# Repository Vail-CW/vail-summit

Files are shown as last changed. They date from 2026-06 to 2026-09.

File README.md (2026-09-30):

# VAIL SUMMIT

A pocket-sized Morse code (CW) trainer and ham radio tool. Learn code from scratch, keep your
skills sharp, and use it on the air. It has a color screen, a built-in paddle and speaker, and
runs on its own battery, so you don't need a computer.





> **Now in testing. Official release is planned for July 2026.** You can get one early during the
> testing phase at [shop.ke9bos.com](https://shop.ke9bos.com), or email me (Brett, KE9BOS) at
> [ke9bos@pigletradio.org](mailto:ke9bos@pigletradio.org).

## What is it?

VAIL SUMMIT is a standalone device for learning and practicing Morse code. New to CW? It will take
you from your first character to real copy. Been at it a while? Use it to warm up, log contacts,
and get on the air.

Turn it on and you start at a home screen with your training progress and the day's band
conditions. From there you can take a lesson, run a quick drill, play a game, key a real radio, or
hop on the internet Morse repeater and ragchew with other ops in code.

It does two jobs:

- It teaches CW with a structured course that starts at full character speed.
- It works as a portable ham tool for logging contacts, POTA, propagation, keying your rig, and
  storing CW messages.

## What you can do with it

### Learn CW

One course that takes you from your first character to solid copy. It uses the Koch method: you
hear letters at full speed from the start, so you learn the sound of each character instead of
counting dits and dahs. Each lesson moves from a quick intro to solo practice, then mixed copy,
then real words and callsigns. It saves your place, so you pick up where you left off.

Three ways to practice once you're going:

- **Daily practice:** a short warm-up that mixes in everything you've learned.
- **Copy practice:** open-ended listen-and-type, for as long as you want.
- **Send practice:** key the paddle and the device decodes your sending as you go.

### Practice and decode

There's a practice oscillator with a live decoder built in. Key on the paddle (or a straight key)
and the device shows your Morse as text on screen, along with your speed in words per minute. It's
a handy way to check your own fist.

### Games

A few games to make practice less of a chore: **Morse Shooter** (arcade-style falling characters),
**Memory Chain**, the maritime-themed **Spark Watch**, a speed challenge, and more. Each one keeps
score.

### On the air

- **Key your radio:** a 3.5 mm jack keys an external transceiver, either as a keyer or a
  straight-through key.
- **CW memories:** store your common calls and exchanges and send them with one button.
- **QSO logger:** log contacts on the device or in your browser, view them on a map, and export to
  ADIF or CSV for your main logging program.
- **POTA:** Parks On The Air lookups and activation tracking for portable operating.
- **Band conditions and band plans:** live solar and propagation numbers, plus frequency
  privileges by license class, so you know where and when to call CQ.

### Vail internet repeater

Connect over WiFi to the Vail Morse repeater (vailmorse.com) and send and receive real, hand-keyed
Morse with other operators around the world. It's an easy way to get on the "air" when you don't
have a radio in front of you.

### Connect it

- **WiFi web interface:** open the device in any browser on your network to practice, log contacts,
  manage files, and change settings on a bigger screen. It's password-protected, and your password
  shows on the device under System Info.
- **Bluetooth:** works as a wireless keyer for software like MorseRunner, speaks standard BLE MIDI,
  and can connect to a Bluetooth keyboard.

## Getting started

### 1. Put firmware on it

No software to install:

1. Open the [web flasher](https://update.vailadapter.com) in Chrome or Edge.
2. Plug the device into your computer with a USB cable.
3. Pick **VAIL SUMMIT**, click **Flash**, and follow the prompts.

### 2. First steps

1. Power on. You'll land on the home screen.
2. Move with the **arrow keys**, select with **Enter**, go back with **Esc**.
3. Pick **Learn CW** to start your first lesson, or look around the menus.
4. For WiFi (needed for the repeater, logging, and the web interface), go to
   **More > Settings > WiFi** and join your network.

### 3. Handy to know

- **Quick settings:** press **V** from a menu to adjust volume, brightness, CW speed, and tone
  without leaving what you're doing.
- **Web access:** once you're on WiFi, open `http://vail-summit.local/` from a browser on the same
  network.
- **Start over:** there's a factory reset under **Settings > Device Settings**, or hold both paddle
  levers while you power on.

## What's in it

A small, battery-powered computer set up for CW:

- **4-inch color LCD** with a card-style menu
- **Built-in speaker**, plus a real **iambic paddle and capacitive touch pads** (straight key works too)
- **Rechargeable battery** with a charge readout on screen
- **WiFi and Bluetooth** built in
- **microSD card** slot for logs and files
- **3.5 mm jack** for keying an external radio

## Help and community

- **Buy a Summit (testing phase):** [shop.ke9bos.com](https://shop.ke9bos.com) or [ke9bos@pigletradio.org](mailto:ke9bos@pigletradio.org)
- **Questions or ideas:** [GitHub Discussions](https://github.com/Vail-CW/vail-summit/discussions)
- **Found a bug?** [GitHub Issues](https://github.com/Vail-CW/vail-summit/issues)

## For tinkerers and developers

VAIL SUMMIT runs on an ESP32-S3, and the firmware source is open for noncommercial use. If you want
to build it, change it, or just look around:

- [Building from source](docs/BUILDING.md): toolchain setup and compiling
- [Hardware reference](docs/HARDWARE.md): board, pins, and interfaces
- [Architecture](docs/ARCHITECTURE.md) and [development notes](docs/DEVELOPMENT.md)

## License

Copyright (c) 2025 Brett Hollifield (KE9BOS) / Vail-CW.

The firmware is licensed under the **PolyForm Noncommercial License 1.0.0** (see
[LICENSE.md](LICENSE.md)). You're free to use, modify, and share it for noncommercial purposes.
Selling devices that run this firmware needs a license from me. It's built with several
open-source libraries; see [THIRD_PARTY_NOTICES.md](THIRD_PARTY_NOTICES.md) for credits.

## Thanks

- The [Vail Morse Repeater](https://vailmorse.com) community for the internet CW connection
- [morse-pro](https://github.com/scp93ch/morse-pro) by Stephen C Phillips for the decoding foundation
- The CW clubs and Elmers who keep new hams getting on the air

*73 de KE9BOS, Brett Hollifield, [ke9bos@pigletradio.org](mailto:ke9bos@pigletradio.org)*

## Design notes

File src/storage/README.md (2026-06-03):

# Storage Module

SD card storage management for VAIL SUMMIT.

## Overview

The storage module provides SD card file management capabilities through a web interface. The SD card shares the SPI bus with the display and uses lazy initialization to avoid boot-time conflicts.

## Files

- **`sd_card.h`** - Core SD card functionality (initialization, file operations, storage stats)

## Hardware Configuration

**GPIO Pin:** 38 (SD_CS - Chip Select)
**Shared SPI Bus:** MOSI=35, SCK=36, MISO=37 (same as display)
**Display CS:** GPIO 10 (separate chip select allows bus sharing)

## SD Card Requirements

- **Format:** FAT32 (required - exFAT not supported)
- **Recommended Size:** 4-32 GB SDHC
- **Speed Class:** Class 10 or higher
- **Important:** Cards >32 GB must be reformatted to FAT32

## Initialization Strategy

The SD card uses **lazy initialization** (on-demand):

1. **Boot Time:** SD card is NOT initialized (prevents SPI conflicts with display)
2. **First Access:** When user accesses `/storage` page, SD card initializes automatically
3. **SPI Sharing:** LovyanGFX display is configured with `bus_shared=true` to allow coexistence

### Why Lazy Init?

Initializing the SD card during boot can interfere with the display's SPI configuration, causing a blank screen. By deferring initialization until first use, we ensure:
- Display always boots correctly
- SPI bus is properly shared between devices
- No user impact (SD init happens transparently on first page access)

## API Functions

### `bool initSDCard()`
Initialize SD card and detect card type. Returns `true` if successful, `false` if no card or init failed.

### `void updateSDCardStats()`
Update global variables for card size and usage statistics.

### `String listSDFiles(const char* dirname, bool recursive = false, int depth = 0)`
List files in directory, returns JSON array of file objects.

### `bool deleteSDFile(const char* path)`
Delete file at specified path.

### `bool fileExists(const char* path)`
Check if file exists.

### `size_t getFileSize(const char* path)`
Get file size in bytes.

### `String readSDFile(const char* path)`
Read entire file contents (for small files).

### `bool writeSDFile(const char* path, const char* data)`
Write data to file (overwrites existing).

### `bool appendSDFile(const char* path, const char* data)`
Append data to existing file.

## Web Interface Integration

The storage module integrates with the web server via:

- **`web_api_storage.h`** - REST API endpoints for file operations
- **`web_pages_storage.h`** - HTML/CSS/JS storage management page

### REST API Endpoints

- `GET /api/storage/status` - Get SD card statistics
- `GET /api/storage/files?path=/` - List files in directory
- `GET /api/storage/download?file=/filename` - Download file
- `DELETE /api/storage/delete?file=/filename` - Delete file
- `POST /api/storage/upload` - Upload file (multipart/form-data)

### Web Page

Access at: `http://vail-summit.local/storage`

Features:
- Storage usage graph
- File browser with icons and sizes
- Upload files via file picker
- Download and delete buttons for each file

## Usage Examples

### Initialize SD Card
```cpp
if (initSDCard()) {
  Serial.println("SD card ready!");
  Serial.printf("Size: %llu MB\n", sdCardSize);
}
```

### Write File
```cpp
writeSDFile("/data.txt", "Hello from VAIL SUMMIT!");
```

### Read File
```cpp
String contents = readSDFile("/data.txt");
Serial.println(contents);
```

### List Files
```cpp
String fileList = listSDFiles("/");
Serial.println(fileList);  // Prints JSON array
```

## Future Use Cases

This SD card infrastructure enables:

1. **Data Logging** - Log training sessions, practice statistics, WPM progress
2. **QSO Backups** - Export QSO logs to SD card for offline backup
3. **Configuration Backups** - Save/restore device settings to SD card
4. **Firmware Updates** - Store firmware binaries for OTA updates
5. **Custom Content** - Load callsign lists, practice text, custom character sets

## Troubleshooting

**Display is blank after boot:**
- Ensure SD card init is NOT called during boot sequence
- SD card should only initialize on first web access

**"SD card not available" error:**
- Check card is inserted
- Verify card is formatted as FAT32 (not exFAT)
- Check wiring: CS=38, MOSI=35, SCK=36, MISO=37

**Cannot upload large files:**
- FAT32 has 4 GB file size limit
- Check available free space on card

**Files not showing in web interface:**
- Ensure card is FAT32 formatted
- Check files are in root directory (/)
- Refresh the page to trigger re-initialization

## Technical Notes

- SD library uses 4 MHz SPI clock (safe speed for compatibility)
- Mount point: `/sd`
- Max open files: 5 (default SD library limit)
- File paths must start with `/` (e.g., `/data.txt`)

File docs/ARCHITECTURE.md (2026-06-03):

# Architecture

This document covers the system architecture, state machine, main loop responsibilities, and critical subsystems.

## Code Organization

The firmware follows a modular architecture with all source code organized into thematic folders:

```
vail-summit/
├── src/
│   ├── core/           # Core system (config, morse code, hardware init)
│   ├── audio/          # Audio system and morse decoder (I2S, WPM, adaptive decoder)
│   ├── ui/             # UI components (menu system, status bar)
│   ├── training/       # Training modes (Practice, CW Academy, Koch Method, Hear It Type It)
│   ├── games/          # Games (Morse Shooter, Memory Chain)
│   ├── radio/          # Radio integration (keying output, CW memories)
│   ├── settings/       # Settings management (WiFi, CW, volume, callsign, web password)
│   ├── qso/            # QSO logging (storage, input, validation, statistics)
│   ├── web/            # Web interface
│   │   ├── server/     # Web server core (AsyncWebServer, routing)
│   │   ├── api/        # REST API endpoints (WiFi, QSO, settings, memories)
│   │   ├── pages/      # HTML/CSS/JS pages (dashboard, logger, settings, games)
│   │   └── modes/      # WebSocket handlers (practice, memory chain, hear it)
│   └── network/        # Network services (Vail repeater, NTP, POTA API)
├── vail-summit.ino     # Main sketch file (setup, loop, mode handlers)
└── docs/               # Documentation
```

**Key Benefits:**
- **Modularity:** Each folder contains related functionality
- **Maintainability:** Easy to locate and modify specific features
- **Scalability:** New features added to appropriate folders
- **Clear dependencies:** Include paths reveal module relationships

**Include Path Conventions:**
- From `.ino` file: `#include "src/core/config.h"`
- Between headers: `#include "../core/config.h"` (relative paths)

## Mode-Based State Machine

The system operates as a state machine with different modes (`MenuMode` enum in vail-summit.ino). Each mode has its own input handler and UI renderer. The main loop delegates to the appropriate mode handler based on `currentMode`.

### Key Modes

**Menu Navigation:**
- `MODE_MAIN_MENU` - Top-level menu (Training, Games, Settings, Radio, Logs, Sleep)
- `MODE_TRAINING_MENU` - Training submenu
- `MODE_SETTINGS_MENU` - Settings submenu
- `MODE_GAMES_MENU` - Games submenu
- `MODE_RADIO_MENU` - Radio submenu

**Training Modes:**
- `MODE_HEAR_IT_TYPE_IT` - Receive training (type what you hear)
- `MODE_PRACTICE` - Practice oscillator with paddle keying
- `MODE_CW_ACADEMY_TRACK_SELECT` - CW Academy track selection
- `MODE_CW_ACADEMY_SESSION_SELECT` - Session selection
- `MODE_CW_ACADEMY_PRACTICE_TYPE_SELECT` - Practice type selection
- `MODE_CW_ACADEMY_MESSAGE_TYPE_SELECT` - Message type selection
- `MODE_CW_ACADEMY_COPY_PRACTICE` - CW Academy copy practice (listen and type)

**Games:**
- `MODE_MORSE_SHOOTER` - Arcade-style game with adaptive decoder (shoot falling letters with morse code, supports straight key and iambic keyer)

**Radio Integration:**
- `MODE_RADIO_OUTPUT` - Key external ham radios via 3.5mm jack outputs
- `MODE_CW_MEMORIES` - Store and playback CW message memories (placeholder)

**Network:**
- `MODE_VAIL_REPEATER` - Internet morse repeater via WebSocket

**Settings:**
- `MODE_WIFI_SETTINGS` - WiFi scanning, connection, credential management
- `MODE_CW_SETTINGS` - CW speed, tone frequency, key type
- `MODE_VOLUME_SETTINGS` - Volume adjustment
- `MODE_CALLSIGN_SETTINGS` - User callsign configuration

**Logging:**
- QSO Logger accessed via web interface (no dedicated device mode for input)

## Main Loop Responsibilities

The `loop()` function (vail-summit.ino) performs:

1. **Status Icon Updates** - Every 5 seconds (except during practice/training to avoid audio interference)
2. **Mode-Specific Updates** - Calls update functions (`updatePracticeOscillator()`, `updateVailRepeater()`, `updateMorseShooterInput()`, `updateMorseShooterVisuals()`, `updateRadioOutput()`)
3. **Keyboard Polling** - CardKB via I2C at 10ms intervals (50ms during practice/game modes for audio priority)
4. **Triple-ESC Sleep Timeout** - Tracks ESC presses for deep sleep entry

### Loop Timing

**Normal operation:** 10ms delay between iterations
**Audio-critical modes (Practice, Morse Shooter, Radio Output):** 50ms keyboard polling, 1ms main loop delay

## Audio System Architecture

The audio system uses **I2S DMA** for high-quality, glitch-free output through the MAX98357A amplifier. This replaces the legacy PWM buzzer.

### Critical Timing Requirements

1. **I2S DMA has highest interrupt priority** (`ESP_INTR_FLAG_LEVEL3`) to beat SPI display DMA
2. **I2S must be initialized BEFORE the display** to establish DMA priority
3. **Audio buffers are filled in interrupt context** - tone generation must be fast
4. **During practice mode, display updates are COMPLETELY DISABLED** to avoid audio glitches
5. **`continueTone()` function maintains phase continuity** for smooth audio transitions

### Volume Control

- **Software attenuation** (0-100%) applied during sample generation in `i2s_audio.h`
- Settings persisted in Preferences namespace "audio"
- Hardware gain on MAX98357A is fixed (GAIN pin configuration)

### Audio Functions

```cpp
beep(frequency_hz, duration_ms);  // Short beeps/tones (blocking)
startTone(frequency_hz);          // Start continuous tone
continueTone();                   // Maintain tone with phase continuity
stopTone();                       // Stop continuous tone
```

**Important:** Always use these functions instead of direct I2S manipulation. They handle volume scaling and phase continuity.

## Morse Code Timing

All timing uses the **PARIS standard** (50 dit units per word):

- **Dit duration:** `1200 / WPM` milliseconds
- **Dah duration:** `3 × dit`
- **Inter-element gap:** `1 × dit`
- **Letter gap:** `3 × dit`
- **Word gap:** `7 × dit`

**WPM Range:** 5-40 WPM (configurable per mode, stored in Preferences)

### MorseTiming Class

```cpp
#include "src/core/morse_code.h"
MorseTiming timing(20);  // 20 WPM timing calculator

// Available properties:
// timing.ditDuration
// timing.dahDuration
// timing.elementGap
// timing.letterGap
// timing.wordGap
```

## Input Handling Pattern

Each mode implements three key functions:

### Required Functions

1. **`start<Mode>(tft)`** - Initialize mode state and draw initial UI
2. **`handle<Mode>Input(key, tft)`** - Process keyboard input, return -1 to exit mode
3. **`update<Mode>()`** (optional) - Called every loop iteration for real-time updates

### Return Codes

Input handlers return:
- **`-1`** - Exit mode (return to parent menu)
- **`0` or `1`** - Normal input processed
- **`2`** - Full UI redraw requested
- **`3`** - Partial UI update (e.g., input box only)

### Example Implementation

```cpp
void startMyMode(LGFX& tft) {
  // Initialize state variables
  myModeState = 0;

  // Draw initial UI
  tft.fillScreen(COLOR_BACKGROUND);
  // ... draw UI elements
}

int handleMyModeInput(char key, LGFX& tft) {
  if (key == 0x1B) {  // ESC key
    return -1;  // Exit mode
  }

  // Process other keys
  // ...

  return 0;  // Input processed
}

void updateMyMode() {
  // Called every loop iteration
  // Perform real-time updates (non-blocking)
}
```

## Menu Navigation

The menu system uses a card-based UI where users scroll through options and select items.

### Navigation Controls

**Arrow Keys:**
- **Up/Down** - Navigate between menu items (scroll through cards)
- **Right** - Select highlighted menu item (enter submenu/mode)

**Other Keys:**
- **Enter** - Select highlighted menu item (same as Right arrow)
- **ESC** - Go back to parent menu / Exit current mode
- **ESC (triple press in main menu)** - Enter deep sleep mode

### Visual Design

Each menu card displays:
- Icon representing the menu option
- Title text
- Right arrow (→) indicating the option can be selected

The right arrow visual matches the keyboard input - pressing the **Right arrow key** or **Enter** selects the highlighted card.

### Implementation

Menu navigation is handled in `src/ui/menu_navigation.h`:
- `handleKeyPress()` routes input based on current mode
- `selectMenuItem()` transitions to the selected mode
- `drawMenuItems()` renders the card-based UI with arrow indicators

## Configuration Management

All user settings are stored in ESP32 Preferences (non-volatile flash storage).

### Preferences Namespaces

- **"wifi"** - Up to 3 WiFi network credentials (ssid1-3, pass1-3)
  - Auto-connect tries all saved networks in order at startup
  - Most recently connected network stored in slot 1
  - Saved networks marked with star (*) in WiFi settings UI
- **"cwsettings"** - WPM speed, tone frequency (Hz), key type
- **"audio"** - Volume percentage
- **"callsign"** - User callsign for Vail repeater
- **"cwa"** - CW Academy progress (track, session, practice type, message type)
- **"radio"** - Radio mode (Summit Keyer vs Radio Keyer)
- **"qso_operator"** - Station info (callsign, grid square, POTA reference)
- **"cw_memories"** - CW memory presets (10 slots)
  - Keys: "label1" through "label10", "message1" through "message10"
  - Each slot stores a label (max 15 chars) and message (max 100 chars)
  - Empty slots stored as empty strings
  - Loaded at startup via `loadCWMemories()` in `src/radio/radio_cw_memories.h`
  - Saved immediately on create/edit/delete
  - Debug logging: All load/save operations print to Serial for troubleshooting

### Best Practices

- Load settings on startup
- Save immediately when changed (don't batch writes)
- Use consistent key names across modules

## WiFi Configuration and AP Mode

### WiFi Connectivity Modes

The device supports two WiFi modes for flexible connectivity:

**Station (STA) Mode:**
- Default mode - connects to existing WiFi networks
- Auto-connects to saved networks on startup (tries all 3 slots in order)
- Web server accessible via mDNS at `http://vail-summit.local` or device IP
- Supports up to 3 saved network credentials

**Access Point (AP) Mode:**
- Creates its own WiFi network for direct connection
- Useful when no WiFi available or for initial setup
- SSID format: `VAIL-SUMMIT-XXXXXX` (XXXXXX = chip ID in hex)
- Default password: `vailsummit`
- IP address: `192.168.4.1` (standard ESP32 AP address)
- mDNS not available in AP mode (use IP address only)

### Entering AP Mode

**From Device:**
1. Navigate to Settings → WiFi Setup
2. Press 'A' key to enable AP mode
3. Device creates WiFi network and starts web server
4. Screen shows network name, password, and IP address

**Connecting to AP:**
1. On phone/laptop, connect to `VAIL-SUMMIT-XXXXXX` WiFi network
2. Enter password: `vailsummit`
3. Open browser to `http://192.168.4.1/`
4. Access web interface for device configuration

### Automatic AP Mode Exit

When connecting to a WiFi network from AP mode (via web or device):

1. **Device automatically:**
   - Stops AP mode and web server
   - Connects to the selected WiFi network
   - Saves credentials to preferences
   - Shows "Connected!" message for 2 seconds
   - Returns to main menu
   - Web server restarts in Station mode (via WiFi event handler)

2. **User experience:**
   - Web interface shows success modal: "Check Your Device"
   - Phone loses connection to AP (expected behavior)
   - Device is now accessible on the new WiFi network at its assigned IP

3. **Error handling:**
   - If connection fails, AP mode automatically restarts
   - User can try again without manual intervention

### Web Server Behavior

**WiFi Event Handler** (vail-summit.ino:182-190):
- Automatically starts web server when WiFi connects (Station mode)
- Automatically stops web server when WiFi disconnects
- `setupWebServer()` detects AP vs Station mode and configures accordingly

**AP Mode Web Server:**
- Starts automatically when `startAPMode()` is called
- Skips mDNS setup (not supported in AP mode)
- Accessible only via IP address: `http://192.168.4.1/`
- Stops automatically when AP mode exits

**Station Mode Web Server:**
- Starts via WiFi event handler on connection
- Includes mDNS responder: `http://vail-summit.local/`
- Accessible via mDNS or IP address
- Stops via WiFi event handler on disconnection

### WiFi Settings Module (src/settings/settings_wifi.h)

**State Machine:**
```cpp
enum WiFiSettingsState {
  WIFI_STATE_SCANNING,        // Scanning for networks
  WIFI_STATE_NETWORK_LIST,    // Showing available networks
  WIFI_STATE_PASSWORD_INPUT,  // Entering password
  WIFI_STATE_CONNECTING,      // Attempting connection
  WIFI_STATE_CONNECTED,       // Successfully connected
  WIFI_STATE_ERROR,          // Connection failed
  WIFI_STATE_RESET_CONFIRM,  // Confirming credential reset
  WIFI_STATE_AP_MODE         // Access Point mode active
};
```

**Key Functions:**
- `startAPMode()` - Creates AP, starts web server
- `stopAPMode()` - Stops AP, returns to Station mode
- `connectToWiFi(ssid, password)` - Handles connection with automatic AP exit
- `scanNetworks()` - Scans for available WiFi networks
- `saveWiFiCredentials()` - Stores up to 3 network credentials
- `autoConnectWiFi()` - Tries saved networks on startup

**Tracking Variables:**
- `isAPMode` - Global flag for AP mode state
- `connectedFromAPMode` - Tracks if connection made from AP mode
- `connectionSuccessTime` - Timestamp for auto-exit timer

## Vail Repeater Protocol

The Vail repeater (`src/network/vail_repeater.h`) uses a WebSocket connection with JSON messages:

### Transmission Format

```json
{"Timestamp":1759710473428,"Clients":0,"Duration":[198]}
```

- Each tone sent immediately as separate message
- **Timestamp:** Unix epoch milliseconds (when tone started)
- **Duration array:** Contains single tone duration in milliseconds
- Silences are implicit (gaps between tones)

### Reception Format

```json
{"Timestamp":1759710473428,"Clients":2,"Duration":[100,50,100,150]}
```

- **Even indices** (0, 2, 4...): tone durations
- **Odd indices** (1, 3, 5...): silence durations
- Clock skew calculated from initial handshake for synchronization
- 500ms playback delay buffer for network jitter
- Echo filtering: messages with our own timestamp are ignored

## Battery Monitoring

Two battery monitor chips are supported (I2C auto-detection on startup):

- **MAX17048** at address `0x36` (primary, used on Adafruit ESP32-S3 Feather V2)
- **LC709203F** at address `0x0B` (backup/alternative)

The fuel gauge chips provide voltage and state-of-charge percentage. Calibration improves over several charge/discharge cycles.

**USB charging detection is disabled** because GPIO 15 (A3) is used by I2S for the LRC clock signal. Using `analogRead(A3)` reconfigures the pin and completely breaks I2S audio output.

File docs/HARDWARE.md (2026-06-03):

# Hardware Interfaces

This document covers all hardware interfaces, pin assignments, and peripheral configurations for the VAIL SUMMIT device.

## Display (ST7796S 4.0" via SPI)

- **Model:** 4.0" TFT ST7796S LCD
- **Resolution:** 480×320 pixels (landscape orientation, `SCREEN_ROTATION = 1`)
- **Library:** LovyanGFX (replaces Adafruit_ST7789)
- **Chip Select:** GPIO 10 (`TFT_CS`)
- **Reset:** GPIO 11 (`TFT_RST`)
- **Data/Command:** GPIO 12 (`TFT_DC`)
- **MOSI:** GPIO 35 (Hardware SPI)
- **SCK:** GPIO 36 (Hardware SPI)
- **MISO:** GPIO 37 (Hardware SPI - required for ST7796S)
- **Backlight:** Hardwired to 3.3V (always on)

**Configuration:**
- Hardware SPI used for maximum performance
- Display updates disabled during audio-critical operations (practice, games, radio)
- Partial screen updates used where possible to minimize glitches

## SD Card (via SPI - shares bus with display)

- **Chip Select:** GPIO 38 (`SD_CS`)
- **MOSI:** GPIO 35 (Shared with display - Hardware SPI)
- **SCK:** GPIO 36 (Shared with display - Hardware SPI)
- **MISO:** GPIO 37 (Shared with display - Hardware SPI)

**Configuration:**
- SD card shares the same SPI bus as the display
- Separate chip select pins allow independent device control (Display: GPIO 10, SD: GPIO 38)
- Only one device can be active at a time (controlled by CS pin)
- SD card slot is integrated on the back of the ST7796S display board
- Requires separate wiring of all 4 SD card pins to ESP32-S3 Feather

**Library Support:**
- Standard Arduino SD library (FAT32 file system)
- SPI bus must be properly shared between display and SD card operations
- SD card initialized on-demand (first access to storage page) to avoid boot-time SPI conflicts

**Card Requirements:**
- Format: FAT32 (required)
- Recommended size: 4-32 GB SDHC
- Speed class: Class 10 or higher recommended
- Cards larger than 32 GB must be reformatted from exFAT to FAT32

## Keyboard (CardKB via I2C)

- **I2C Address:** `0x5F`
- **SDA:** GPIO 3
- **SCL:** GPIO 4

### Special Key Codes

- `0xB5` - UP arrow
- `0xB6` - DOWN arrow
- `0xB4` - LEFT arrow
- `0xB7` - RIGHT arrow
- `0x0D` - ENTER
- `0x1B` - ESC

### Polling Behavior

- **Normal modes:** 10ms intervals
- **Practice/Game modes:** 50ms intervals (audio priority)

## Paddle Input

**Physical Paddle Pins:**
- **DIT:** GPIO 6 (`PADDLE_DIT_PIN`)
- **DAH:** GPIO 9 (`PADDLE_DAH_PIN`)
- **Configuration:** Active LOW with internal pullups

**Supported Key Types:**
- Straight key (DIT paddle only)
- Iambic A (alternating priority)
- Iambic B (last-contact priority with memory)

**Implementation:**
- Iambic logic in `training_practice.h`
- Implements memory modes and squeeze keying
- State machine handles timing for WPM accuracy

## Capacitive Touch

**Touch Pad Pins:**
- **DIT:** GPIO 8 (T8) - `TOUCH_DIT_PIN`
- **DAH:** GPIO 5 (T5) - `TOUCH_DAH_PIN`
- **Threshold:** Configured in `config.h` (`TOUCH_THRESHOLD = 40000`)

### Critical Notes

**CRITICAL BUG WORKAROUNDS:**
1. **Must use GPIO numbers directly in `touchRead()`**, not T-constants (ESP32-S3 bug)
   - Correct: `touchRead(8)` and `touchRead(5)`
   - Incorrect: `touchRead(T8)` and `touchRead(T5)`

2. **Touch values RISE when touched on ESP32-S3**
   - Check `> threshold`, not `< threshold`
   - Opposite of ESP32 classic behavior

3. **GPIO 13 conflicts with GPIO 14** (I2S/touch shield channel)
   - Causes peripheral freeze
   - Avoid using GPIO 13 for touch sensing

4. **GPIO 8 and GPIO 5 work reliably together** without conflicts

### Hardware Requirements

- Uses ESP32-S3 internal capacitive sensing
- No external components required
- Conductive pads or bare PCB traces sufficient

## Radio Keying Output

**Output Pins:**
- **DIT output:** GPIO 18 (A0) - `RADIO_KEY_DIT_PIN`
- **DAH output:** GPIO 17 (A1) - `RADIO_KEY_DAH_PIN`
- **Format:** 3.5mm TRS jack (Tip = Dit, Ring = Dah, Sleeve = GND)
- **Logic:** Active HIGH (pin goes HIGH when keying)

### Hardware Interface Circuit

**CRITICAL:** Direct GPIO-to-radio connection may damage equipment. Always use driver circuit:

```
GPIO → 1kΩ resistor → NPN transistor base
Transistor collector → Radio keying input
Transistor emitter → GND
```

Recommended transistors: 2N2222, 2N3904, or similar NPN types

### Compatibility

- Tested and working with external ham radios
- Same design as standard Vail adapters
- Transistors pull radio keying inputs to ground when activated

## I2S Audio (MAX98357A)

**I2S Pins:**
- **BCK (Bit Clock):** GPIO 14 (`I2S_BCK_PIN`)
- **LRC (Word Select):** GPIO 15 (`I2S_LRC_PIN`)
- **DIN (Data In):** GPIO 16 (`I2S_DIN_PIN`)

**Audio Configuration:**
- **Sample Rate:** 44.1kHz
- **Bit Depth:** 16-bit
- **Channels:** Stereo (mono signal duplicated to both channels)
- **Software Volume Control:** 0-100%
- **Hardware Gain:** Set by GAIN pin (float=9dB, GND=12dB, VIN=6dB)

### Critical Initialization

1. **I2S must be initialized BEFORE display** - I2S needs higher DMA priority
2. **I2S DMA has highest interrupt priority** (`ESP_INTR_FLAG_LEVEL3`)
3. **Audio buffers filled in interrupt context** - tone generation must be fast

### Volume Control

- Software attenuation applied during sample generation in `i2s_audio.h`
- Settings persisted in Preferences namespace "audio"
- Hardware gain on MAX98357A is fixed (GAIN pin configuration)

## Battery Monitor

Two battery monitor chips supported (I2C auto-detection on startup):

### MAX17048 (Primary)

- **I2C Address:** `0x36`
- **Used on:** Adafruit ESP32-S3 Feather V2
- **Features:** Voltage and state-of-charge percentage
- **Library:** Adafruit MAX1704X

### LC709203F (Backup/Alternative)

- **I2C Address:** `0x0B`
- **Features:** Voltage and state-of-charge percentage
- **Library:** Adafruit LC709203F

### Calibration

- Fuel gauge chips provide voltage and SoC percentage
- Calibration improves over several charge/discharge cycles
- Initial readings may be lower than actual charge

### USB Charging Detection

**USB charging detection is DISABLED** because GPIO 15 (A3) is used by I2S for the LRC clock signal.

**Why:**
- Using `analogRead(A3)` reconfigures the pin
- This completely breaks I2S audio output
- No workaround available - I2S LRC cannot be moved

## Pin Repurposing Notes

### GPIO 5 (Originally BUZZER_PIN)

**Old usage:** PWM buzzer
**New usage:** Capacitive touch dit pad (`TOUCH_DIT_PIN`)
**Reason:** PWM buzzer replaced by I2S audio system

### GPIO 13 (Originally TFT_BL)

**Old usage:** Display backlight PWM
**New usage:** Capacitive touch dah pad (`TOUCH_DAH_PIN`)
**Reason:** Display backlight hardwired to 3.3V for always-on operation

**NOTE:** GPIO 13 was later changed to GPIO 5 due to conflicts with GPIO 14 (I2S)

### GPIO 15 (A3, USB_DETECT_PIN)

**Cannot be used for:** Analog input (USB charging detection)
**Current usage:** I2S LRC clock signal
**Reason:** Any `analogRead(A3)` call breaks audio

### GPIO 38 (SD Card CS)

**Current usage:** SD card chip select
**Notes:** One of the few remaining free GPIO pins on the ESP32-S3 Feather
**Functionality:** Web-based file management (upload, download, delete), data logging support
**Initialization:** On-demand (lazy init when storage management page is accessed)

## I2C Devices

**I2C Bus:**
- **SDA:** GPIO 3
- **SCL:** GPIO 4

**Devices:**
- `0x5F` - CardKB keyboard
- `0x36` - MAX17048 battery monitor (primary)
- `0x0B` - LC709203F battery monitor (backup)

**Auto-Detection:**
- I2C scan performed at startup
- Battery monitor type auto-detected
- Debug output on serial monitor

## GPIO Pin Summary

| GPIO | Function | Direction | Notes |
|---|---|---|---|
| 3 | I2C SDA | Bidirectional | CardKB, battery monitor |
| 4 | I2C SCL | Output | CardKB, battery monitor |
| 5 | Touch DIT | Input | Capacitive touch pad T5 |
| 6 | Paddle DIT | Input | Active LOW with pullup |
| 8 | Touch DAH | Input | Capacitive touch pad T8 |
| 9 | Paddle DAH | Input | Active LOW with pullup |
| 10 | TFT CS | Output | Display chip select |
| 11 | TFT RST | Output | Display reset |
| 12 | TFT DC | Output | Display data/command |
| 14 | I2S BCK | Output | Audio bit clock |
| 15 | I2S LRC | Output | Audio word select |
| 16 | I2S DIN | Output | Audio data |
| 17 | Radio DAH | Output | Radio keying (A1) |
| 18 | Radio DIT | Output | Radio keying (A0) |
| 35 | SPI MOSI | Output | Display/SD card data (hardware SPI) |
| 36 | SPI SCK | Output | Display/SD card clock (hardware SPI) |
| 37 | SPI MISO | Input | Display/SD card data in (hardware SPI) |
| 38 | SD CS | Output | SD card chip select |

## Power Considerations

**Active Power Consumption:**
- WiFi on: ~200mA
- WiFi off: ~100mA
- Deep sleep: ~20µA

**Wake Source:**
- DIT paddle press (GPIO 6)
- Triple-tap ESC in main menu to enter deep sleep

**Battery Life Estimates:**
- 500mAh battery: ~2-5 hours (WiFi dependent)
- Deep sleep: Several days to weeks

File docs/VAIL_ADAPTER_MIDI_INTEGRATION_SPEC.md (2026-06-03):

# Vail Adapter MIDI Integration Specification

## Overview

The Vail Adapter is an open-source Morse code keyer that provides both USB HID keyboard functionality and USB MIDI control. This document specifies how external applications can integrate with the MIDI portion of the adapter to control keyer behavior, tone generation, and timing parameters.

## Device Information

- **Device Type**: USB MIDI Class-Compliant Device
- **MIDI Channel**: 1 (Channel 0 in zero-indexed systems)
- **Vendor**: Open Source Hardware
- **Compatible with**: Any MIDI-capable application or DAW

## MIDI Message Types

The Vail Adapter responds to the following MIDI message types:

### Control Change Messages (0xBn)

#### CC0 - Mode Control
**Purpose**: Switch between Keyboard mode and MIDI mode

- **Message**: `B0 00 xx`
- **Values**:
  - `00-3F` (0-63): Enable Keyboard mode (sends USB HID keyboard events)
  - `40-7F` (64-127): Enable MIDI mode (sends MIDI note events)
- **Default**: Keyboard mode on startup
- **Example**: `B0 00 7F` enables MIDI mode

#### CC1 - Dit Duration (Speed Control)
**Purpose**: Control keying speed by setting dit duration

- **Message**: `B0 01 xx`
- **Formula**: Dit duration = `xx × 2` milliseconds
- **Range**: 2ms to 254ms (corresponds to ~600 WPM down to ~2.4 WPM)
- **Default**: 50 (100ms dit duration ≈ 12 WPM)
- **Example**: `B0 01 32` sets dit duration to 100ms (~12 WPM)

#### CC2 - Sidetone Note
**Purpose**: Set the MIDI note number for the sidetone frequency

- **Message**: `B0 02 xx`
- **Range**: 0-127 (standard MIDI note range)
- **Default**: 69 (A4 = 440Hz)
- **Notes**: Uses equal temperament tuning
- **Example**: `B0 02 45` sets sidetone to A2 (110Hz)

### Program Change Messages (0xCn)

#### Keyer Mode Selection
**Purpose**: Select the keyer algorithm/behavior

- **Message**: `C0 xx`
- **Keyer Types**:
  - `00`: Passthrough (manual control - sends MIDI notes C# and D for dit/dah)
  - `01`: Straight Key (cootie)
  - `02`: Bug (semi-automatic)
  - `03`: Electric Bug
  - `04`: Single Dot
  - `05`: Ultimatic
  - `06`: Plain Iambic
  - `07`: Iambic A
  - `08`: Iambic B
  - `09`: Keyahead
- **Default**: 1 (Straight Key)
- **Invalid values**: Default to passthrough (0)

### Note On/Off Messages (0x9n/0x8n)

#### Sidetone Control
**Purpose**: Manual sidetone generation (works like a standard MIDI synthesizer)

- **Note On**: `90 xx yy` (start playing note xx at velocity yy)
- **Note Off**: `80 xx yy` (stop playing note xx)
- **Range**: 0-127 (standard MIDI notes)
- **Behavior**: Only affects built-in buzzer, not keyer logic

## Integration Example

Here's a sample sequence for an integration to configure the adapter:

```
# Set to MIDI mode
B0 00 7F

# Set medium speed (120ms dit = ~10 WPM)
B0 01 3C

# Set sidetone to middle C (261.6Hz)
B0 02 3C

# Enable Iambic B keyer mode
C0 08
```

## Output Messages

When in MIDI mode, the adapter sends:

### Keyer Output (Passthrough Mode)
- **Dit**: Note On/Off C# (MIDI note 1)
- **Dah**: Note On/Off D (MIDI note 2)
- **Straight Key**: Note On/Off C (MIDI note 0)

### Implementation Notes

1. **Mode Priority**: The adapter automatically prioritizes MIDI mode when receiving MIDI commands, eliminating the need for manual mode switching
2. **Settings Persistence**: All settings (keyer type, dit duration, sidetone note) are saved to EEPROM and restored on power-up
3. **Real-time Response**: All MIDI commands take effect immediately
4. **Thread Safety**: MIDI processing is handled in the main loop with proper state management

## Technical Specifications

- **USB MIDI Class**: 1.0 compliant
- **Latency**: <1ms for MIDI command processing
- **Concurrent Notes**: Single note playback (monophonic)
- **Power Requirements**: USB bus powered
- **Operating System**: Windows, macOS, Linux (class-compliant)

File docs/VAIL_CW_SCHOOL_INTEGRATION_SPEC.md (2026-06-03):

# Vail CW School Integration Spec
## For Summit Device Linking & Progress Sync

**Document Version:** 1.1
**Date:** February 2026
**Audience:** Vail CW School Web Development Team

**Revision History:**
- 1.1: Updated to match Summit device implementation (checkCode uses GET, added device-side storage schema, HTTP headers, token exchange details)
- 1.0: Initial specification

---

## Executive Summary

This document specifies the backend services needed in Vail CW School to support integration with Vail Summit hardware devices. The integration enables:

1. **Device Linking** - Connect a Summit device to a user's CW School account
2. **Progress Sync** - Bidirectional synchronization of training progress
3. **Practice Time Reporting** - Track practice time from device sessions

The Summit device team will implement the device-side client. Your team needs to implement:
- 5 Firebase Cloud Functions (APIs)
- Firestore collections for device and progress data
- Web UI for device management

---

## 0. Configuration Requirements

The Summit device firmware requires the following configuration values from the CW School team:

| Value | Purpose | Example |
|---|---|---|
| `CWSCHOOL_FUNCTIONS_BASE` | Cloud Functions base URL | `https://us-central1-vail-cw-school.cloudfunctions.net` |
| `CWSCHOOL_FIREBASE_API_KEY` | Firebase Web API Key | `REDACTED_CWSCHOOL_API_KEY` |
| `CWSCHOOL_LINK_DEVICE_URL` | Link device web page | `https://learncw.vailmorse.com/link-device` |

These are configured in `src/network/cwschool_link.h` on the device side.

---

## 1. Device Linking Flow

### Overview

Users link their Summit device to their CW School account using a short alphanumeric code. This avoids requiring users to type passwords on a small device keyboard.

### Sequence Diagram

```
┌─────────────┐         ┌──────────────────┐         ┌─────────────────┐
│   Summit    │         │  Cloud Functions │         │   Web App       │
│   Device    │         │  (Firebase)      │         │   (Browser)     │
└──────┬──────┘         └────────┬─────────┘         └────────┬────────┘
       │                         │                            │
       │ 1. POST /requestCode    │                            │
       │ ───────────────────────>│                            │
       │                         │                            │
       │ {code: "ABC123",        │                            │
       │  expires_in: 600}       │                            │
       │ <───────────────────────│                            │
       │                         │                            │
       │                         │    2. User visits          │
       │                         │    vail.school/link-device │
       │                         │ <──────────────────────────│
       │                         │                            │
       │                         │    3. User enters code     │
       │                         │    POST /linkDevice        │
       │                         │ <──────────────────────────│
       │                         │                            │
       │                         │──┐                         │
       │                         │  │ 4. Generate custom      │
       │                         │  │    token for device     │
       │                         │<─┘                         │
       │                         │                            │
       │                         │    {success: true}         │
       │                         │ ──────────────────────────>│
       │                         │                            │
       │ 5. GET /checkCode       │                            │
       │    (polling every 5s)   │                            │
       │ ───────────────────────>│                            │
       │                         │                            │
       │ {status: "linked",      │                            │
       │  custom_token: "..."}   │                            │
       │ <───────────────────────│                            │
       │                         │                            │
       │ 6. Exchange custom      │                            │
       │    token for ID token   │                            │
       │ ───────────────────────>│ Firebase Auth              │
       │ <───────────────────────│                            │
       │                         │                            │
       ▼                         ▼                            ▼
   Device stores              Link complete              Shows success
   tokens locally                                        message
```

### Link Code Requirements

- **Format:** 6 alphanumeric characters (A-Z, 0-9, excluding confusables like 0/O, 1/I/L)
- **Valid characters:** `ABCDEFGHJKMNPQRSTUVWXYZ23456789` (32 chars)
- **Expiry:** 10 minutes from generation
- **Single use:** Code invalidated after successful link

---

## 2. Required Cloud Functions

### 2.1 `api_summit_requestCode`

**Type:** HTTPS REST endpoint (POST)
**Auth:** None required (device not yet linked)

**Request:**
```
POST /api_summit_requestCode
Content-Type: application/json

{
  "device_name": "VAIL Summit",
  "device_type": "vail_summit",
  "firmware_version": "0.41",
  "device_id": "ESP32-AABBCCDD1122"  // Optional on first link, included on re-link
}
```

Note: The `device_id` field is optional on first link (server generates new ID) but should be included when re-linking an existing device.

**Response (Success - 200):**
```json
{
  "code": "ABC123",
  "link_url": "https://learncw.vailmorse.com/link-device",
  "expires_in": 600,
  "device_id": "ESP32-AABBCCDD1122"
}
```

**Response (Error - 429):**
```json
{
  "error": "rate_limited",
  "message": "Too many requests. Try again in 60 seconds.",
  "retry_after": 60
}
```

**Backend Logic:**
1. Generate cryptographically random 6-char code
2. Check for collision with existing active codes
3. Store in Firestore `deviceCodes/{code}`:
   ```json
   {
     "code": "ABC123",
     "device_id": "ESP32-AABBCCDD1122",
     "device_type": "vail_summit",
     "device_name": "VAIL Summit",
     "firmware_version": "0.41",
     "status": "pending",
     "created_at": Timestamp,
     "expires_at": Timestamp (created + 10 min)
   }
   ```
4. Return code and metadata

**Rate Limiting:** Max 5 requests per device_id per hour

---

### 2.2 `api_summit_checkCode`

**Type:** HTTPS REST endpoint (GET)
**Auth:** None required

**Request:** GET with query parameters
```
GET /api_summit_checkCode?code=ABC123&device_id=ESP32-AABBCCDD1122
```

**Response (Pending - 200):**
```json
{
  "status": "pending"
}
```

**Response (Linked - 200):**
```json
{
  "status": "linked",
  "custom_token": "eyJhbGciOiJSUzI1NiIs...",
  "device_id": "ESP32-AABBCCDD1122",
  "user": {
    "uid": "firebase-auth-uid",
    "callsign": "W1ABC",
    "display_name": "John Smith"
  }
}
```

**Response (Expired - 410):**
```json
{
  "status": "expired",
  "error": "Code has expired"
}
```

**Response (Invalid - 404):**
```json
{
  "status": "invalid",
  "error": "Code not found"
}
```

**Backend Logic:**
1. Parse `code` and `device_id` from query parameters
2. Look up code in Firestore
3. Verify device_id matches (prevents code theft)
4. Check expiry time
5. If status is "linked", return custom_token, device_id, and user info
6. If status is "pending" and not expired, return pending
7. If expired, delete document and return expired status

**Polling:** Device will call this every 5 seconds for up to 10 minutes

---

### 2.3 `api_summit_linkDevice`

**Type:** HTTPS Callable
**Auth:** Required (user must be logged in)

**Request:**
```json
{
  "code": "ABC123"
}
```

**Response (Success - 200):**
```json
{
  "success": true,
  "device_id": "ESP32-AABBCCDD1122",
  "device_name": "VAIL Summit"
}
```

**Response (Invalid Code - 400):**
```json
{
  "success": false,
  "error": "invalid_code",
  "message": "Invalid or expired code"
}
```

**Response (Already Linked - 409):**
```json
{
  "success": false,
  "error": "already_linked",
  "message": "This device is already linked to another account"
}
```

**Backend Logic:**
1. Verify user is authenticated
2. Look up code, verify status is "pending" and not expired
3. Generate Firebase custom token: `admin.auth().createCustomToken(uid, { device_id, device_type })`
4. Update Firestore `deviceCodes/{code}`:
   ```json
   {
     "status": "linked",
     "linked_at": Timestamp,
     "user_uid": "auth-uid",
     "custom_token": "generated-token"
   }
   ```
5. Add device to user's device list (see Firestore Schema below)
6. Return success

---

### 2.4 `api_summit_listDevices`

**Type:** HTTPS Callable
**Auth:** Required

**Request:** None (uses auth context)

**Response (200):**
```json
{
  "devices": [
    {
      "device_id": "ESP32-AABBCCDD1122",
      "device_name": "VAIL Summit",
      "device_type": "vail_summit",
      "firmware_version": "0.41",
      "linked_at": "2026-01-30T12:00:00Z",
      "last_sync_at": "2026-02-01T08:30:00Z"
    }
  ]
}
```

---

### 2.5 `api_summit_unlinkDevice`

**Type:** HTTPS Callable
**Auth:** Required

**Request:**
```json
{
  "device_id": "ESP32-AABBCCDD1122"
}
```

**Response (Success - 200):**
```json
{
  "success": true
}
```

**Backend Logic:**
1. Verify user owns this device
2. Delete from `users/{uid}/devices/{device_id}`
3. Optionally: revoke any active refresh tokens for this device

---

## 3. Progress Sync APIs

### 3.1 `api_summit_syncProgress`

**Type:** HTTPS Callable
**Auth:** Required (device uses ID token from custom token exchange)

This is the main bidirectional sync endpoint. Device sends its progress, server merges with cloud data, returns merged result.

**Request:**
```json
{
  "v": 1,
  "device_id": "ESP32-AABBCCDD1122",
  "last_sync_time": 1706900000000,
  "session": {
    "start_time": 1706898200000,
    "duration_sec": 1800,
    "mode": "vail_course"
  },
  "vail_course": {
    "current_module": "letters-3",
    "current_lesson": 2,
    "completed_lessons": ["letters-1-1", "letters-1-2", "letters-2-1"],
    "char_mastery": {
      "E": { "mastery": 850, "attempts": 120, "correct": 108, "avg_ttr_ms": 450 },
      "T": { "mastery": 780, "attempts": 95, "correct": 82, "avg_ttr_ms": 520 },
      "A": { "mastery": 620, "attempts": 45, "correct": 35, "avg_ttr_ms": 680 }
    },
    "achievements": 7
  },
  "practice_time": {
    "today_sec": 1800,
    "total_sec": 72000,
    "history": {
      "2026-02-01": 1800,
      "2026-01-31": 2400
    }
  }
}
```

**Response (200):**
```json
{
  "sync_time": 1706900500000,
  "conflict_resolution": "merged",
  "merged_progress": {
    "vail_course": {
      "current_module": "letters-3",
      "current_lesson": 2,
      "completed_lessons": ["letters-1-1", "letters-1-2", "letters-2-1", "letters-2-2"],
      "module_progress": {
        "letters-1": { "unlocked": true, "lessons_completed": 2, "total_lessons": 2 },
        "letters-2": { "unlocked": true, "lessons_completed": 2, "total_lessons": 3 },
        "letters-3": { "unlocked": true, "lessons_completed": 1, "total_lessons": 3 }
      },
      "char_mastery": {
        "E": { "mastery": 920, "attempts": 180, "correct": 165 },
        "T": { "mastery": 850, "attempts": 140, "correct": 125 },
        "A": { "mastery": 720, "attempts": 85, "correct": 68 }
      }
    },
    "stats": {
      "total_practice_sec": 95000,
      "today_practice_sec": 3600,
      "current_streak": 5,
      "longest_streak": 14,
      "total_xp": 4520
    }
  },
  "xp_earned": 85,
  "new_achievements": ["STREAK_7"]
}
```

**Merge Rules:**
| Field | Resolution Strategy |
|---|---|
| `completed_lessons` | Union (completed on either = completed) |
| `char_mastery.mastery` | Take maximum value |
| `char_mastery.attempts/correct` | Sum deltas since last sync |
| `practice_time.total_sec` | Add session duration |
| `practice_time.history` | Merge maps, sum overlapping dates |
| `achievements` | Bitwise OR |
| `current_module/lesson` | Take furthest progression |

---

### 3.2 `api_summit_getProgress`

**Type:** HTTPS Callable
**Auth:** Required

Read-only endpoint for initial sync when device has no local data.

**Request:**
```json
{
  "device_id": "ESP32-AABBCCDD1122"
}
```

**Response:** Same format as `merged_progress` above

---

## 4. Device-Side Storage Schema

The Summit device stores CW School credentials in ESP32 NVS (flash) under the `cwschool` namespace:

| Key | Type | Description |
|-----|---|---|
| `linked` | bool | Whether device is linked to an account |
| `device_id` | string | Unique device identifier |
| `id_token` | string | Firebase ID token (for authenticated API calls) |
| `refresh_tkn` | string | Firebase refresh token |
| `token_exp` | ulong | Token expiry time (millis timestamp) |
| `uid` | string | Firebase Auth UID of linked user |
| `callsign` | string | User's callsign (if set) |
| `display` | string | User's display name |

---

## 5. Firestore Schema

### Collection: `deviceCodes`

Temporary storage for active link codes. Clean up expired entries periodically.

```
deviceCodes/{code}
├── code: string                    "ABC123"
├── device_id: string               "ESP32-AABBCCDD1122"
├── device_type: string             "vail_summit"
├── device_name: string             "VAIL Summit"
├── firmware_version: string        "0.41"
├── status: string                  "pending" | "linked" | "expired"
├── created_at: timestamp
├── expires_at: timestamp
├── linked_at: timestamp | null
├── user_uid: string | null
└── custom_token: string | null     (only set when linked)
```

**Indexes:**
- `status` + `expires_at` (for cleanup query)

**TTL:** Set Firestore TTL policy to auto-delete documents 24 hours after `expires_at`

---

### Collection: `users/{uid}/devices`

Track which devices are linked to each user.

```
users/{uid}/devices/{device_id}
├── device_id: string               "ESP32-AABBCCDD1122"
├── device_type: string             "vail_summit"
├── device_name: string             "VAIL Summit"
├── firmware_version: string        "0.41"
├── linked_at: timestamp
├── last_sync_at: timestamp
└── last_seen_at: timestamp
```

---

### Collection: `users/{uid}/progress`

Extend existing progress document to include device sync metadata.

```
users/{uid}/progress/current
├── ... (existing progress fields) ...
│
├── device_sync: {
│   ├── last_sync_time: number (timestamp ms)
│   ├── last_device_id: string
│   └── pending_merge: boolean
│ }
│
└── vail_course: {                  (NEW - matches web course structure)
    ├── current_module: string
    ├── current_lesson: number
    ├── completed_lessons: string[]
    ├── module_progress: {
    │   [module_id]: {
    │     unlocked: boolean
    │     lessons_completed: number
    │   }
    │ }
    └── char_mastery: {
        [char]: {
          mastery: number (0-1000)
          attempts: number
          correct: number
          avg_ttr_ms: number
          confused_with: { [char]: count }
        }
      }
    }
```

---

## 6. Security Rules

```javascript
rules_version = '2';
service cloud.firestore {
  match /databases/{database}/documents {

    // Device codes - public read for checking, no direct writes
    match /deviceCodes/{code} {
      allow read: if true;
      allow write: if false;  // Only via Cloud Functions
    }

    // User devices - only owner can read
    match /users/{userId}/devices/{deviceId} {
      allow read: if request.auth != null && request.auth.uid == userId;
      allow write: if false;  // Only via Cloud Functions
    }

    // User progress - only owner can read, write via functions
    match /users/{userId}/progress/{doc} {
      allow read: if request.auth != null && request.auth.uid == userId;
      allow write: if false;  // Only via Cloud Functions
    }
  }
}
```

---

## 7. Web UI Requirements

### 6.1 Device Link Page (`/link-device`)

**Route:** `https://learncw.vailmorse.com/link-device`

**UI Flow:**
1. If not logged in → redirect to login with return URL
2. Show text input for 6-character code
3. On submit → call `api_summit_linkDevice`
4. Show success message with device name
5. Optionally redirect to device management

**Mockup:**
```
┌─────────────────────────────────────────────┐
│           Link Your VAIL Summit             │
│                                             │
│  Enter the code displayed on your device:   │
│                                             │
│  ┌─────────────────────────────────┐        │
│  │  A B C 1 2 3                    │        │
│  └─────────────────────────────────┘        │
│                                             │
│           [ Link Device ]                   │
│                                             │
│  Code expires in 8:42                       │
└─────────────────────────────────────────────┘
```

### 6.2 Device Management (in Account Settings)

**Location:** Account Settings → Linked Devices

**Features:**
- List all linked devices with name, type, last seen
- Unlink button per device (with confirmation)
- Show sync status (last sync time)

**Mockup:**
```
┌─────────────────────────────────────────────┐
│  Linked Devices                             │
├─────────────────────────────────────────────┤
│  ┌─────────────────────────────────────┐    │
│  │ 📟 VAIL Summit                      │    │
│  │    Firmware: v0.41                  │    │
│  │    Last synced: 2 hours ago         │    │
│  │    Linked: Jan 30, 2026             │    │
│  │                        [ Unlink ]   │    │
│  └─────────────────────────────────────┘    │
│                                             │
│  [ + Link New Device ]                      │
└─────────────────────────────────────────────┘
```

---

## 8. XP & Achievement Integration

### XP Awards from Device Activity

| Activity | XP |
|---|-----|
| Correct character (first 100/day) | 1 |
| Complete lesson | 50 |
| Complete module | 200 |
| Daily practice (any duration) | 10 |
| Streak milestone (7 days) | 100 |
| Streak milestone (30 days) | 500 |
| First device link | 50 |

### Device-Specific Achievements

| Achievement ID | Criteria |
|---|---|
| `SUMMIT_LINKED` | First device linked |
| `SUMMIT_FIRST_LESSON` | Complete first lesson on device |
| `SUMMIT_STREAK_7` | 7-day streak with device practice |
| `SUMMIT_PRACTICE_1HR` | 1 hour total practice on device |
| `SUMMIT_PRACTICE_10HR` | 10 hours total practice on device |

---

## 9. HTTP Headers for Authenticated Requests

For all authenticated API calls, the device includes these headers:

```
Authorization: Bearer <firebase_id_token>
X-Device-ID: <device_id>
Content-Type: application/json
```

The `X-Device-ID` header allows the backend to verify the request comes from the claimed device.

---

## 10. Error Handling

### HTTP Status Codes

| Code | Meaning |
|---|---|
| 200 | Success |
| 400 | Bad request (invalid input) |
| 401 | Unauthorized (invalid/expired token) |
| 403 | Forbidden (not allowed for this user) |
| 404 | Not found (invalid code/device) |
| 409 | Conflict (device already linked) |
| 410 | Gone (code expired) |
| 429 | Rate limited |
| 500 | Server error |

### Error Response Format

```json
{
  "error": "error_code",
  "message": "Human-readable message",
  "details": { }
}
```

### Token Exchange (Custom Token → ID Token)

After receiving a custom token from `checkCode`, the device exchanges it for Firebase ID/refresh tokens:

**Endpoint:** `POST https://identitytoolkit.googleapis.com/v1/accounts:signInWithCustomToken?key={API_KEY}`

**Request:**
```json
{
  "token": "<custom_token_from_checkCode>",
  "returnSecureToken": true
}
```

**Response:**
```json
{
  "idToken": "<firebase_id_token>",
  "refreshToken": "<firebase_refresh_token>",
  "expiresIn": "3600"
}
```

The device stores both tokens and uses `idToken` for authenticated API calls.

### Token Refresh

Device uses Firebase Auth REST API to refresh expired tokens:

**Endpoint:** `POST https://securetoken.googleapis.com/v1/token?key={API_KEY}`

**Request:** (`application/x-www-form-urlencoded`)
```
grant_type=refresh_token&refresh_token=<stored_refresh_token>
```

**Response:**
```json
{
  "id_token": "<new_firebase_id_token>",
  "refresh_token": "<new_refresh_token>",
  "expires_in": "3600"
}
```

- Device handles HTTP 401 by attempting token refresh, then retrying the failed request
- If refresh fails (e.g., refresh token revoked), device must re-link
- Tokens are refreshed when expiring within 5 minutes (300 seconds safety margin)

---

## 11. Rate Limits

| Endpoint | Limit |
|---|---|
| `requestCode` | 5/hour per device |
| `checkCode` | 120/10min per code (polling) |
| `linkDevice` | 10/hour per user |
| `syncProgress` | 60/hour per device |
| `getProgress` | 30/hour per device |

---

## 12. Testing Checklist

### Device Linking
- [ ] Code generation returns valid 6-char code
- [ ] Code expires after 10 minutes
- [ ] Linking with valid code succeeds
- [ ] Linking with expired code fails (410)
- [ ] Linking with invalid code fails (404)
- [ ] Device receives custom token after link
- [ ] Custom token can be exchanged for ID token
- [ ] Multiple devices can link to same account
- [ ] Unlinking removes device from list
- [ ] Rate limits enforced

### Progress Sync
- [ ] Initial sync (no local data) returns cloud progress
- [ ] Device progress merges with cloud progress
- [ ] Completed lessons union correctly
- [ ] Character mastery takes max
- [ ] Practice time accumulates correctly
- [ ] Streak calculated from merged history
- [ ] XP awarded for new achievements
- [ ] Concurrent syncs from web and device resolve correctly

### Edge Cases
- [ ] Offline device queues sync, flushes on reconnect
- [ ] Expired token triggers re-auth flow
- [ ] Large progress payload (40 characters) fits response
- [ ] Clock skew between device and server handled

---

## Appendix A: Character Set

Characters tracked for mastery (40 total):

```
Letters: A B C D E F G H I J K L M N O P Q R S T U V W X Y Z (26)
Numbers: 0 1 2 3 4 5 6 7 8 9 (10)
Punctuation: . , ? / (4)
```

Character encoding for Firestore keys (some chars not allowed in keys):
- `.` → `_DOT_`
- `,` → `_COMMA_`
- `?` → `_QUESTION_`
- `/` → `_SLASH_`

---

## Appendix B: Module Definitions

Modules that need to be synced (matching web course):

| Module ID | Name | Characters | Prerequisites |
|---|---|---|---|
| letters-1 | Letters 1 | E, T | None |
| letters-2 | Letters 2 | A, N, I | letters-1 |
| letters-3 | Letters 3 | R, S, O | letters-2 |
| letters-4 | Letters 4 | H, D, L | letters-3 |
| letters-5 | Letters 5 | C, U, M | letters-4 |
| letters-6 | Letters 6 | W, F, Y | letters-5 |
| letters-7 | Letters 7 | P, G, K | letters-6 |
| letters-8 | Letters 8 | V, B, X, J, Q, Z | letters-7 |
| numbers | Numbers | 0-9 | letters-6 |
| punctuation | Punctuation | . , ? / | numbers |
| words-common | Common Words | (words) | punctuation |
| callsigns | Callsigns | (patterns) | words-common |

---

## Contact

**Summit Device Team:** (your contact)
**CW School Web Team:** (web team contact)

Questions about this spec? Reach out before implementing.

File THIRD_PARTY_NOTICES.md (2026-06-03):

# Third-Party Notices

VAIL SUMMIT firmware incorporates the following third-party software. Each component
is the property of its respective copyright holders and is used under the license
noted. Full license texts are in each library's source (bundled under
`arduino-cli/user/libraries/` and the ESP32 Arduino core).

| Component | Version | License | Copyright |
|---|---|---|---|
| ESP32 Arduino core | 2.0.14 | LGPL-2.1 / Apache-2.0 | Espressif Systems |
| LVGL | 8.3.11 | MIT | 2021 LVGL Kft |
| LovyanGFX | 1.1.16 | FreeBSD (BSD-2-Clause) | lovyan03 (Bonsai-Bonsai) |
| NimBLE-Arduino | 1.4.2 | Apache-2.0 | h2zero & contributors |
| ArduinoJson | 7.0.4 | MIT | Benoit Blanchon |
| ESP Async WebServer | 3.6.0 | **LGPL-3.0** | Hristo Gochkov / ESP32Async |
| AsyncTCP | 3.3.2 | **LGPL-3.0** | Hristo Gochkov / ESP32Async |
| WebSockets (arduinoWebSockets) | 2.4.1 | **LGPL-2.1** | 2015 Markus Sattler |
| Adafruit LC709203F | 1.3.4 | BSD-3-Clause | 2019 Adafruit Industries |
| Adafruit MAX1704X | 1.0.3 | BSD-3-Clause | 2022 Adafruit Industries |
| Adafruit BusIO | 1.17.4 | MIT | 2017 Adafruit Industries |

## Morse decoding (derived work)

`src/audio/morse_decoder.h`, `src/audio/morse_decoder_adaptive.h`, and
`src/audio/morse_wpm.h` are ported/derived from **morse-pro** by Stephen C Phillips
(<https://github.com/scp93ch/morse-pro>).

- Original work: Copyright (c) 2024 Stephen C Phillips
- Modifications: Copyright (c) 2025 VAIL SUMMIT Contributors
- License: **European Union Public Licence (EUPL) v1.2** — <https://opensource.org/licenses/EUPL-1.2>

The EUPL is a copyleft license. The source of these modules is made available under the
EUPL; their attribution and license headers must be preserved in distributions.

## Copyleft obligations (important for distribution)

The firmware statically links the **LGPL** components above (ESP Async WebServer,
AsyncTCP, WebSockets) and **LGPL** parts of the ESP32 core. LGPL permits use in a
commercial/closed product, but requires that recipients be able to replace the LGPL
library with a modified version — in practice for embedded firmware this means
distributing either the firmware source or the relinkable object files for the product.
Keeping this repository's source available satisfies that. The **EUPL** modules
similarly require their source to remain available under the EUPL.

> This file is informational, not legal advice. Confirm the obligations above with
> counsel before commercial distribution, especially if any part of the firmware is
> closed-sourced.

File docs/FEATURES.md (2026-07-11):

# Features

This document covers detailed documentation for major features including CW Academy, Morse Shooter, Memory Chain, Radio Mode, and Morse Decoder.

## CW Academy Training Mode

### Overview

The CW Academy mode implements the official CW Academy curriculum across **four training tracks**. Each track is a comprehensive 16-session program with progressive difficulty.

### Training Tracks

1. **Beginner** - Learn CW from zero (4 → 44 characters over Sessions 1-10)
2. **Fundamental** - Build solid foundation (assumes basic CW knowledge)
3. **Intermediate** - Increase speed & skill (higher WPM targets)
4. **Advanced** - Master advanced CW techniques

### Module Architecture: `training_cwa.h`

**Track Structure:**
```cpp
enum CWATrack {
  TRACK_BEGINNER = 0,
  TRACK_FUNDAMENTAL = 1,
  TRACK_INTERMEDIATE = 2,
  TRACK_ADVANCED = 3
};
```

**Session Data Structure:**
```cpp
struct CWASession {
  int sessionNum;           // Session number (1-16)
  int charCount;            // Total characters learned by this session
  const char* newChars;     // New characters introduced
  const char* description;  // Session description
};
```

### Beginner Track Session Progression

**Sessions 1-10:** Progressive character introduction (4 chars → 44 chars)
- Session 1: A, E, N, T (4 chars) - Foundation
- Session 2: + S, I, O, 1, 4 (9 chars) - Numbers Begin
- Session 10: + X, Z, ., <BK>, <SK> (44 chars) - Complete!

**Sessions 11-13:** QSO (conversation) practice with all 44 characters

**Sessions 14-16:** On-air preparation and encouragement

### Practice Types

```cpp
enum CWAPracticeType {
  PRACTICE_COPY = 0,           // Listen and type what you hear
  PRACTICE_SENDING = 1,        // Send with physical key
  PRACTICE_DAILY_DRILL = 2     // Warm-up drills
};
```

**Practice Type Locking:**
- **Sessions 1-10:** Only Copy Practice available (advanced types locked)
- **Sessions 11+:** All practice types unlocked
- Visual lock indicators with "Unlocks at Session 11" hint
- Error beep feedback when attempting to access locked content

### Message Types

```cpp
enum CWAMessageType {
  MESSAGE_CHARACTERS = 0,      // Random character practice
  MESSAGE_WORDS = 1,           // Common words
  MESSAGE_ABBREVIATIONS = 2,   // CW abbreviations (73, QSL, etc.)
  MESSAGE_NUMBERS = 3,         // Number sequences
  MESSAGE_CALLSIGNS = 4,       // Random callsigns
  MESSAGE_PHRASES = 5          // Full sentences
};
```

### Navigation Flow

1. Training Menu → **CW Academy**
2. **Track Selection** (MODE_CW_ACADEMY_TRACK_SELECT)
3. **Session Selection** (MODE_CW_ACADEMY_SESSION_SELECT)
4. **Practice Type Selection** (MODE_CW_ACADEMY_PRACTICE_TYPE_SELECT)
5. **Message Type Selection** (MODE_CW_ACADEMY_MESSAGE_TYPE_SELECT)
6. **Copy Practice** (MODE_CW_ACADEMY_COPY_PRACTICE) - Fully implemented

### State Management

- Progress saved to ESP32 Preferences namespace "cwa"
- Current track, session, practice type, and message type persisted across reboots
- Functions: `loadCWAProgress()`, `saveCWAProgress()`
- Variables: `cwaSelectedTrack`, `cwaSelectedSession`, `cwaSelectedPracticeType`, `cwaSelectedMessageType`

### Implementation Status

**Chunk 1.1 - Track and Session Selection (Complete):**
- ✅ Menu integration: "CW Academy" added to Training menu
- ✅ Track selection screen with 4 tracks
- ✅ Session selection screen with 16 sessions (Beginner track defined)
- ✅ Two-level navigation with ESC back navigation
- ✅ Progress persistence

**Chunk 1.2 - Practice and Message Type Selection (Complete):**
- ✅ Practice type selection screen with 3 types
- ✅ Message type selection screen with 6 types
- ✅ Complete navigation flow
- ✅ Practice type locking for Sessions 1-10
- ✅ Visual lock indicators
- ✅ Error beep feedback

**Chunk 1.3 - Copy Practice Mode (Complete):**
- ✅ MODE_CW_ACADEMY_COPY_PRACTICE mode added
- ✅ Complete character sets for all 16 Beginner sessions
- ✅ 10-round copy practice sessions with score tracking
- ✅ Adjustable character count (1-10)
- ✅ Replay functionality (SPACE bar)
- ✅ Context-aware help text
- ✅ State machine (listening → input → feedback)

**Future Chunks:**
- ⏳ Session content for Fundamental/Intermediate/Advanced tracks
- ⏳ Proper word lists for word practice
- ⏳ Abbreviations content (73, QSL, QTH, etc.)
- ⏳ Number sequences
- ⏳ Realistic callsign generation
- ⏳ Common phrases and QSO exchanges
- ⏳ Sending practice mode
- ⏳ Daily Drill mode
- ⏳ ICR (Instant Character Recognition) mode
- ⏳ QSO practice mode

## Morse Shooter Game

### Overview

The Morse Shooter is an arcade-style game where targets fall from the top of the screen and the player shoots them by keying morse code (straight key, iambic paddle, or ultimatic). The game uses the user-selected morse decoder (Adaptive or Direct, set in CW Settings) for real-time decoding. UI is fully LVGL (`lv_game_screens.h`); game logic lives in `game_morse_shooter.h`.

### Game Modes

| Mode | Targets | Notes |
|---|---|---|
| **Classic** | Single characters | Charset from preset, or custom flags (letters / +numbers / +punctuation) |
| **Progressive** | Single characters | Starts with E/T; unlocks more characters, faster falls, and more concurrent targets as levels advance (every 30s or 10 hits) |
| **Word** | Short CW words (CQ, QTH, RST...) | Word list difficulty follows the preset; words fall at 0.6x speed |
| **Callsign** | Randomly generated callsigns | US + 30% international prefixes |

Each mode keeps its own persistent high score.

### Difficulty Presets

Seven presets (Custom, Beginner, Easy, Medium, Hard, Expert, Insane) control fall speed, spawn rate, lives, max concurrent targets, and charset. Expert/Insane include numbers and punctuation. The Custom preset unlocks the Speed(fall), Lives, and Charset rows. Keying WPM and sidetone are always editable — they are player settings, not difficulty settings.

### Game Loop Architecture

**Dual update system** (both dispatched from `pollTable` every main-loop iteration; the mode is `MODE_FLAG_AUDIO_CRITICAL`, so the loop runs at 1ms):

1. **`updateMorseShooterInput()`** — every iteration: polls paddles, ticks the unified keyer and decoder, flushes the decoder after a word gap of silence.
2. **`updateMorseShooterVisuals()`** — dt-based physics tick every 50ms (speeds are in px/sec). **Frozen while keying**: moving LVGL objects forces display flushes that can crunch live audio, and it gives the player a fair chance to finish the character they started. The tick clock is kept current during the freeze so no teleport-jump happens on unfreeze.

### Shooting

Characters are processed **as soon as they decode** (per-character, at character-gap latency) via the decoder `messageCallback` — not after a word gap. This is what makes Word/Callsign modes playable: every keystroke in a sequence registers.

- **Classic/Progressive**: the matching letter *closest to the ground* is shot.
- **Word/Callsign**: the first matched character "commits" you to a word (prevents callsigns sharing a prefix from stealing keystrokes); a mistype abandons progress and can start another word. Typed prefix renders green via LVGL recolor.
- Prosigns (`<AR>` etc.) are ignored, never treated as targets.
- Miss (decoded char matches nothing): 600 Hz beep, combo resets.

### Scoring

- Base 10 points x combo multiplier (x2 at 3 streak, x3 at 5, x5 at 10, x10 at 20) + speed bonus for hits near the top. Words score x word length.
- High scores update in-memory during play and are committed to NVS **only at game over/exit** — flash commits stall both cores' cache and would crunch live audio if done per hit.

### Spawning

- Letters: random x with 20-attempt collision avoidance (34px horizontal / 40px vertical spacing).
- Words: width-aware placement — the whole word is kept on screen, horizontal overlap with other high words is avoided, and no new word spawns while another is still near the top (prevents same-line overlap).

### Game Over and Restart

- Lives reach 0 (targets hitting the ground each cost one life), or ESC ends the game early to see results.
- Overlay shows final score + NEW HIGH SCORE banner; ENTER restarts (full screen recreation via `startShooterFromSettings()`), ESC exits to the games menu.

## Memory Chain Game

### Overview

Memory Chain is a progressive memory training game that challenges players to remember and reproduce increasingly long sequences of morse code characters. Similar to the classic "Simon Says" game but using CW, it tests both character recognition and short-term memory skills.

### Module: `game_morse_memory.h`

**Game Flow:**
1. Device plays a morse code sequence
2. Player must reproduce the exact sequence using their key
3. On success: sequence grows by one character
4. On failure: game over (Standard mode) or lose a life (Practice mode)

### Game Modes

**Standard Mode:**
- One mistake = game over
- Pure score chase for maximum chain length
- High pressure, tests focus and accuracy

**Practice Mode:**
- 3 lives/hearts per game
- Mistakes cost one life but game continues
- Allows recovery and continued practice
- Better for learning and improvement

**Timed Challenge:**
- Complete as many rounds as possible in 60 seconds
- No game over on mistakes
- Score = total successful chains completed

### Difficulty Levels

**Beginner:**
- Letters only (A-Z)
- 26 character pool
- Ideal for character recognition practice

**Intermediate:**
- Letters + Numbers (A-Z, 0-9)
- 36 character pool
- Increased complexity

**Advanced:**
- Letters + Numbers + Prosigns
- Includes: SK, AR, BT, BK, AS, SN, SOS, HH, CT
- Full morse code challenge

### Settings

**Speed:** 5-40 WPM (adjustable in 5 WPM increments)
**Sound:** ON/OFF (controls sequence playback audio)
**Show Hints:** ON/OFF (default OFF)
- OFF: True memory training - no visual hints
- ON: Display character sequence on screen for reference

All settings persist across power cycles via ESP32 Preferences.

### Keyer Support

Full integration with existing CW settings:
- **Straight Key Mode:** Uses DIT pin only
- **Iambic A/B Mode:** Full paddle squeeze support
- Uses same keyer implementation as Practice Mode and Morse Shooter
- Respects global key type setting from CW Settings menu

### Decoder Integration

**Real-time decoder (Adaptive or Direct based on user setting):**
```cpp
MorseDecoder* mcDecoder = (decoderType == DECODER_DIRECT)
    ? (MorseDecoder*) new MorseDecoderDirect(15, 20, 30)
    : (MorseDecoder*) new MorseDecoderAdaptive(15, 20, 30);
```

**Character Detection:**
- Automatic character gap detection (5× dit duration)
- Decoder flush after character gap for immediate recognition
- Callback-based character processing
- Immediate feedback on correct/incorrect input

**Timing States:**
- Tracks tone-on/tone-off transitions
- Sends positive timing for tone duration
- Sends negative timing for silence duration
- Decoder adapts to player's sending speed

### Visual Feedback

**Game States:**
- **READY:** Green - Game starting (1 second countdown)
- **LISTEN:** Blue - Device playing sequence
- **YOUR TURN:** Yellow/Orange - Awaiting player input
- **CORRECT!:** Green - Successful sequence reproduction
- **WRONG!:** Red - Incorrect character sent

**Display Elements:**
- Chain length (top right): "Chain: X"
- Current score and all-time best (bottom)
- Lives remaining (Practice mode only)
- Optional character hints (if enabled)
- Instructions: "ESC=Menu  S=Settings"

### Audio Feedback

**Success Sounds:**
- Correct answer: High beep (1000 Hz, 200ms)
- New high score: Victory fanfare (3 ascending tones)

**Error Sounds:**
- Wrong answer: Low buzz (200 Hz, 300ms)

**Sidetone:**
- Always plays during keying (regardless of Sound setting)
- Uses global CW tone setting
- Provides immediate audio feedback

### Data Persistence

**Saved Settings (ESP32 Preferences "memory" namespace):**
- Difficulty level
- Game mode
- WPM speed
- Sound enabled/disabled
- Show hints enabled/disabled
- All-time high score

**High Score Tracking:**
- Session high score (resets on game start)
- All-time best (persists across power cycles)
- Separate high scores per difficulty level (future enhancement)

### State Machine

```cpp
enum MemoryGameState {
  MEMORY_STATE_READY,      // Countdown before first round
  MEMORY_STATE_PLAYING,    // Device playing sequence
  MEMORY_STATE_LISTENING,  // Player's turn to reproduce
  MEMORY_STATE_FEEDBACK,   // Show correct/wrong feedback
  MEMORY_STATE_GAME_OVER   // Final score display
};
```

**State Transitions:**
1. READY → PLAYING (after 1 second)
2. PLAYING → LISTENING (after sequence playback)
3. LISTENING → FEEDBACK (on complete sequence or error)
4. FEEDBACK → LISTENING (correct, next round) or GAME_OVER (out of lives)
5. GAME_OVER → READY (ENTER to play again)

### In-Game Menu (Press 'S')

Navigate settings without exiting the game:
- Up/Down arrows: Navigate menu
- Left/Right arrows: Change values
- Enter: Save & Return

Allows quick adjustment of difficulty, mode, speed, and hints during practice sessions.

### Technical Implementation

**Character Pool Management:**
```cpp
const char* getMemoryCharacterSet(MemoryDifficulty difficulty);
```
Returns appropriate character set based on difficulty.

**Sequence Generation:**
```cpp
void startNextRound() {
  memoryGame.sequenceLength++;
  char newChar = characterSet[random(0, setSize)];
  memoryGame.sequence[memoryGame.sequenceLength - 1] = newChar;
}
```
Adds one random character each round.

**Input Validation:**
```cpp
bool checkPlayerSequence(char inputChar) {
  char expected = memoryGame.sequence[memoryGame.playerPosition];
  bool correct = (inputChar == expected);
  memoryGame.playerPosition++;
  return correct;
}
```
Validates each character as it's decoded.

### Menu Integration

**Location:** Games Menu → Memory Chain
**Menu Icon:** "C" (for Chain)
**Menu Navigation:** Same as other game modes

Access from main menu via right arrow on "Memory Chain" card.

## Radio Mode

### Overview

The Radio Mode provides integration with external ham radios via 3.5mm jack outputs. It allows keying a connected radio using the Summit's paddle inputs with two distinct operating modes.

### Architecture: `radio_output.h`

**Radio Mode Types:**
```cpp
enum RadioMode {
  RADIO_MODE_SUMMIT_KEYER,   // Summit does keying logic, outputs straight key format
  RADIO_MODE_RADIO_KEYER     // Passthrough dit/dah contacts to radio's internal keyer
};
```

**Output Pins:**
- **DIT output:** GPIO 18 (A0) - `RADIO_KEY_DIT_PIN`
- **DAH output:** GPIO 17 (A1) - `RADIO_KEY_DAH_PIN`
- **Format:** 3.5mm TRS jack (Tip = Dit, Ring = Dah, Sleeve = GND)
- **Logic:** Active HIGH (pin goes HIGH when keying)

### Summit Keyer Mode

Device performs all keying logic internally and outputs a straight key format signal:

**Straight Key:**
- DIT pin outputs key-down/key-up timing
- DAH pin remains LOW
- Timing follows physical paddle presses directly

**Iambic (A or B):**
- Summit's iambic keyer generates dit/dah elements with proper timing
- DIT pin outputs composite keyed signal (straight key format)
- DAH pin remains LOW
- Timing based on configured WPM speed (`cwSpeed`)
- Full memory paddle support (squeeze keying)

**No Audio Output:**
- Radio output mode does not play sidetone through Summit's speaker
- External radio provides sidetone

### Radio Keyer Mode

Device passes paddle contacts directly to the radio:

**Straight Key:**
- DIT pin mirrors DIT paddle state (HIGH when pressed)
- DAH pin remains LOW

**Iambic:**
- DIT pin mirrors DIT paddle state
- DAH pin mirrors DAH paddle state
- Radio's internal keyer interprets squeeze keying and timing
- Radio's WPM setting controls speed (Summit's WPM ignored)

### Radio Output UI

The Radio Output screen displays three configurable settings:

1. **Speed (WPM):** 5-40 WPM
   - Only affects Summit Keyer mode
   - Ignored in Radio Keyer mode (radio controls speed)
   - Shares global `cwSpeed` setting with Practice mode

2. **Key Type:** Straight / Iambic A / Iambic B
   - Determines paddle input interpretation
   - Affects both modes
   - Shares global `cwKeyType` setting

3. **Radio Mode:** Summit Keyer / Radio Keyer
   - Toggles between internal and external keying logic
   - Persisted in Preferences namespace "radio"

**Navigation:**
- UP/DOWN: Select setting
- LEFT/RIGHT: Adjust value
- ESC: Exit to Radio menu

### Input Sources

Radio Output accepts input from multiple sources simultaneously (OR logic):

1. **Physical Paddle** (GPIO 6 for DIT, GPIO 9 for DAH)
2. **Capacitive Touch** (GPIO 8 for DIT, GPIO 5 for DAH)

Both checked every loop iteration for responsive keying.

### Use Cases

**Contest Operation:**
- Summit Keyer mode for consistent sending at configured speed
- Memory messages for exchanges (future feature)
- Physical paddle for flexibility

**Casual QSOs:**
- Radio Keyer mode to use radio's built-in keyer settings
- Capacitive touch pads for portable operation
- Radio provides sidetone and QSK

**Training Aid:**
- Practice sending at various speeds
- Compare Summit Keyer vs. Radio Keyer behavior
- Use with actual radio for on-air confidence

### CW Memories

The **CW Memories** feature allows storage and management of up to 10 reusable morse code message presets. Presets can be created, edited, deleted, and previewed on the device, or managed via the web interface. They integrate seamlessly with Radio Output mode for transmission.

#### Architecture: `radio_cw_memories.h`

**Preset Structure:**
```cpp
#define CW_MEMORY_MAX_SLOTS 10
#define CW_MEMORY_LABEL_MAX_LENGTH 15
#define CW_MEMORY_MESSAGE_MAX_LENGTH 100

struct CWMemoryPreset {
  char label[CW_MEMORY_LABEL_MAX_LENGTH + 1];     // Label (15 chars + null)
  char message[CW_MEMORY_MESSAGE_MAX_LENGTH + 1]; // Message (100 chars + null)
  bool isEmpty;
};
```

**Storage:**
- Persistent storage via ESP32 Preferences namespace `"cw_memories"`
- Keys: `"label1"` through `"label10"`, `"message1"` through `"message10"`
- Loaded at startup via `loadCWMemories()`
- Saved immediately on create/edit/delete

#### Device UI - CW Memories Mode

Accessible from: **Radio Menu → CW Memories**

**Main Screen:**
- Scrollable list of all 10 preset slots (5 visible at a time)
- Shows `[Slot #] Label` or `[Slot #] (empty)` for unused slots
- Navigation: UP/DOWN to select, ENTER to open action menu, ESC to exit
- Footer: `↑↓ Select  ENTER Menu  ESC Back`

**Action Menu (Full-Screen):**
When ENTER is pressed on a slot, a full-screen action menu appears:

**Empty Slot Actions:**
- **Create Preset** - Opens label entry screen
- **Cancel** - Returns to main list

**Occupied Slot Actions:**
- **Preview** - Plays preset on device speaker
- **Edit Preset** - Opens label/message editor
- **Delete Preset** - Shows delete confirmation
- **Cancel** - Returns to main list

Navigation: UP/DOWN to select action, ENTER to confirm, ESC to cancel

**Create/Edit Flow (Full-Screen):**
1. **Label Entry Screen:**
   - Title: "CREATE PRESET" or "EDIT PRESET"
   - Input box with character counter (max 15 chars)
   - Auto-uppercase text entry
   - Blinking cursor indicator
   - Footer: `Type text  ENTER Save  ESC Cancel`

2. **Message Entry Screen:**
   - Title: "CREATE PRESET" or "EDIT PRESET"
   - Multi-line input box with word wrap (max 100 chars)
   - Character counter showing current/max
   - Validation for valid morse characters (A-Z, 0-9, space, `.`,`,`,`?`,`/`,`-`)
   - Supports prosigns entered as `<AR>`, `<SK>`, etc.
   - Footer: `Type text  ENTER Save  ESC Cancel`

3. **Save:** ENTER advances from label → message → save, ESC cancels at any time

**Delete Confirmation (Full-Screen):**
- Title: "DELETE PRESET?" in red
- Shows preset label being deleted
- Warning: "This action cannot be undone"
- Two large buttons: **Yes, Delete** (red highlight) and **No, Cancel** (blue highlight)
- Navigation: UP/DOWN arrows to select, ENTER to confirm
- Footer: `↑↓ Select  ENTER Confirm  ESC Cancel`

**Preview:**
- Plays preset message on device speaker using current WPM and tone settings
- Does NOT transmit via radio output pins (GPIO 18/17 remain LOW)
- Press ESC to stop playback early

#### Radio Output Mode Integration

In Radio Output mode, press the **'M'** key to open the memory selector:

**Memory Selector Overlay:**
- Modal overlay showing all 10 preset slots
- Scrollable list (5 visible at a time)
- Shows slot number and label (or "(empty)")
- Navigation: UP/DOWN to select, ENTER to queue for transmission, ESC to cancel

**Transmission:**
- Selected preset message is queued via existing `queueRadioMessage()` function
- Uses current WPM speed and Radio Mode settings
- Transmitted via radio output pins (GPIO 18/17)
- Queue limit: 5 messages (error beep if full)

**UI Indicator:**
- Footer in Radio Output mode shows: `M Memories` as hint

#### Debugging and Troubleshooting

**Debug Logging:**
The CW Memories module includes comprehensive debug output via Serial (115200 baud) for troubleshooting:

- `loadCWMemories()` - Prints each slot's label and message when loading from Preferences
- `saveCWMemory()` - Prints label and message when saving to Preferences
- `previewCWMemory()` - Prints label, message, and length before playback
- `queueRadioMessage()` - Prints message and length when queuing for transmission
- `processRadioMessageQueue()` - Prints message and length when transmitting via radio
- `radioIambicKeyerHandler()` - Prints dit/dah duration values for timing verification

**Known Issues:**

1. **Summit Keyer Mode Timing:**
   - In Summit Keyer mode, if `radioDitDuration` becomes corrupted or zero, both manual keying and memory transmission produce "random dits" (rapid/instant timing)
   - Radio Keyer mode works correctly for manual keying (passthrough to radio's keyer)
   - Memories may still sound incorrect in Radio Keyer mode if message queue conflicts with keyer state machine

2. **State Machine Conflict:**
   - `playMorseCharViaRadio()` uses blocking delays while `updateRadioOutput()` keyer state machine runs simultaneously
   - Both functions control the same GPIO pins (18 and 17), causing interference
   - Current mitigation: `processRadioMessageQueue()` waits for keyer state machine to be idle in Summit Keyer mode (checks `radioKeyerActive` and `radioInSpacing` flags)

3. **Preview Crashes:**
   - Preview function (`previewCWMemory()`) may crash and reset device halfway through playback
   - Likely related to blocking audio playback conflicting with other system tasks
   - Workaround: Keep preview messages short or use radio transmission instead

**Troubleshooting Steps:**

1. Enable Serial Monitor at 115200 baud
2. Create a simple test memory (e.g., "TEST" → "SOS")
3. Preview the memory and check serial output for:
   - Correct label and message strings
   - Correct message length
   - Dit/dah duration values (should be non-zero and proportional to WPM)
4. Compare behavior between Summit Keyer and Radio Keyer modes
5. Check if manual keying works correctly in both modes (isolates keyer vs. message queue issues)

#### Supported Characters

**Valid Characters:**
- Letters: A-Z (auto-uppercased)
- Numbers: 0-9
- Punctuation: `.` `,` `?` `/` `-`
- Prosigns: Entered as text like `<AR>`, `<SK>`, `<BK>`, `<BT>`, `<CT>`, `<HH>`, `<SN>`, `<SOS>`
- Spaces: Word spacing in morse code

**Validation:**
- Label and message cannot be empty
- Message must contain only valid morse characters
- Invalid characters trigger error beep and validation message

#### Use Cases

**Contest Operation:**
- Store common exchanges: `"5NN CA"`, `"TU K6ABC"`, `"CQ CQ DE K6ABC K"`
- Quick send via 'M' key in Radio Output mode
- Consistent, error-free messaging

**Casual Operation:**
- Store callsign, standard sign-offs: `"73 ES CUL <SK>"`
- CQ calls with proper prosigns
- Frequently used phrases

**Training:**
- Pre-configured examples for learning proper formats
- Practice sending stored messages

#### State Variables

```cpp
CWMemoryPreset cwMemories[CW_MEMORY_MAX_SLOTS];  // Global array of presets
int cwMemorySelection;                            // Currently selected slot in UI
CWMemoryContextMenu contextMenuActive;            // Current context menu state
CWMemoryEditMode editMode;                        // Current edit mode state
bool memorySelectorActive;                        // True when selector active in Radio Output
int memorySelectorSelection;                      // Selected slot in Radio Output selector
```

## Hear It Type It Training Mode

### Overview

Hear It Type It is a morse code receive training mode that plays random character groups (callsigns, letters, numbers, or custom sets) and challenges users to type what they hear. Available both on-device and via the web interface.

### Module: `training_hear_it_type_it.h`

**Training Workflow:**
1. Device/browser plays a morse code character group
2. User types what they heard
3. System provides instant feedback (correct/incorrect)
4. On success: new group plays
5. On error: same group replays for practice

### Training Modes

**Five Training Modes:**
```cpp
enum HearItMode {
  MODE_CALLSIGNS,        // Realistic ham radio callsigns (W1ABC format)
  MODE_RANDOM_LETTERS,   // Random letters A-Z only
  MODE_RANDOM_NUMBERS,   // Random numbers 0-9 only
  MODE_LETTERS_NUMBERS,  // Mixed letters and numbers
  MODE_CUSTOM_CHARS      // User-specified character set
};
```

**Mode Details:**

1. **Callsigns Mode (Default)**
   - Generates realistic amateur radio callsigns
   - Format follows FCC call patterns: 1-2 prefix letters + number + 1-4 suffix letters
   - Examples: W1ABC, K6XYZ, VE3ABC, N7MNO
   - Prepares users for on-air copy work

2. **Random Letters**
   - Pure alphabet practice (A-Z)
   - Variable length groups (3-10 characters)
   - Tests letter recognition skills

3. **Random Numbers**
   - Number-only practice (0-9)
   - Variable length groups (3-10 characters)
   - Useful for contest exchanges and signal reports

4. **Letters + Numbers**
   - Mixed alphanumeric groups
   - Variable length (3-10 characters)
   - Full character set practice

5. **Custom Characters**
   - User specifies exact character set
   - Can practice specific problem characters
   - Examples: "ETI" (common letters), "QZ" (difficult letters), "0189" (similar numbers)
   - Groups randomly selected from custom set

### Settings

**Group Length:** 3-10 characters (adjustable)
- Callsigns mode: Fixed length based on callsign format (5-7 characters typical)
- All other modes: User-configurable length

**Custom Character Set:** (Custom mode only)
- Specify exact characters to practice
- Max 36 characters (A-Z, 0-9)
- Must contain at least 1 character
- Groups randomly generated from this set

**Speed:** Uses global CW speed setting (5-40 WPM)

**Persistence:** Settings stored in ESP32 Preferences namespace `"hear_it"` with keys:
- `"mode"` - Selected training mode (0-4)
- `"groupLength"` - Character count (3-10)
- `"customChars"` - Custom character string

### Device Implementation

**Navigation:** Training Menu → Hear It Type It

**UI Display:**
```
┌─────────────────────────┐
│  Hear It, Type It       │
│                         │
│  Mode: Letters+Numbers  │
│  Length: 5 chars        │
│  Speed: 20 WPM          │
│                         │
│  [Listening...]         │
│                         │
│  Your input:            │
│  ABC█                   │
│                         │
│  S Settings  ESC Menu   │
└─────────────────────────┘
```

**Settings Overlay (Press 'S'):**
- Full-screen settings menu
- Navigate with UP/DOWN arrows
- Adjust mode with 'M' key (cycles through 5 modes)
- Adjust length with '+' and '-' keys (3-10 range)
- Enter custom characters when Custom mode selected
- ESC to close and return to training
- Settings saved immediately to Preferences

**Input Handling:**
- Type characters as you decode them
- BACKSPACE to correct mistakes
- ENTER to submit answer
- SPACE bar to replay current group
- 'S' key to open settings overlay
- ESC to return to menu

**Feedback:**
- Green highlight + success beep for correct answers
- Red highlight + error beep for incorrect answers
- Automatic replay on errors for reinforcement
- New group generated on success

### Web Interface Implementation

**Access:** `http://vail-summit.local/hear-it`

**Files:**
- `web_pages_hear_it_type_it.h` - Complete HTML/CSS/JavaScript interface
- `web_hear_it_mode.h` - Device-side mode handler
- `web_hear_it_socket.h` - WebSocket communication handler

**Architecture:**

```
Browser (Computer)
├── Settings Panel (Mode, Length, Custom Chars)
├── Audio Playback (Web Audio API - browser plays morse)
├── Input Field (Type what you hear)
└── WebSocket Client (Submit answers, receive results)
        ↕ WebSocket (/ws/hear-it)
VAIL SUMMIT Device
├── Character Generation (generateCharacterGroup)
├── Answer Validation (check correctness)
└── Device Display (Static "Web Hear It Mode Active")
```

**Key Design Decision - Browser Audio:**
- Audio playback handled entirely in browser using Web Audio API
- Device sends morse pattern (e.g., ".- -... -.-.") via WebSocket
- Browser plays morse tones using OscillatorNode with PARIS timing
- Prevents device crashes from audio conflicts
- Provides cleaner, more reliable audio playback

**Settings Panel:**
- **Mode Dropdown:** Callsigns, Random Letters, Random Numbers, Letters+Numbers, Custom
- **Length Input:** Number selector (3-10), hidden for Callsigns mode
- **Custom Characters Input:** Text field, visible only in Custom mode
- Settings sent to device via POST before starting training
- Device applies settings and generates groups accordingly

**Training Flow:**
1. User opens `/hear-it` in browser
2. Selects mode, length, custom characters
3. Clicks "Start Training"
   - Browser sends POST `/api/hear-it/start` with settings
   - Device applies settings to `hearItSettings` struct
   - Device switches to `MODE_WEB_HEAR_IT`
   - Browser opens WebSocket to `/ws/hear-it`
4. Device generates character group using selected mode
5. Device sends morse pattern to browser via WebSocket
6. Browser plays morse code audio using Web Audio API
7. Browser shows input field when audio completes
8. User types answer and submits
9. Browser sends answer to device
10. Device validates and sends result (correct/incorrect)
11. On correct: device generates new group after 2s delay
12. On incorrect: device replays same group after 2s delay
13. User can click "Replay" or "Skip" buttons at any time

**WebSocket Protocol:**

**Device → Browser Messages:**
```json
// New character group
{
  "type": "new_callsign",
  "callsign": "W1ABC",
  "wpm": 18,
  "morse": ".- -.-- .---- .- -... -.-."
}

// Start audio playback
{
  "type": "playing"
}

// Ready for user input
{
  "type": "ready_for_input"
}

// Validation result
{
  "type": "result",
  "correct": true,
  "answer": "W1ABC"
}
```

**Browser → Device Messages:**
```json
// Submit answer
{
  "type": "submit",
  "answer": "W1ABC"
}

// Replay request
{
  "type": "replay"
}

// Skip to next
{
  "type": "skip"
}
```

**Audio Implementation (Web Audio API):**
```javascript
async function playMorsePattern(patterns, wpm) {
  const audioContext = new AudioContext();
  const ditDuration = 1200 / wpm;  // PARIS standard

  for (const pattern of patterns.split(' ')) {
    for (const symbol of pattern) {
      if (symbol === '.') {
        playTone(audioContext, 700, ditDuration);
      } else if (symbol === '-') {
        playTone(audioContext, 700, ditDuration * 3);
      }
      await sleep(ditDuration);  // Inter-element gap
    }
    await sleep(ditDuration * 3);  // Letter gap
  }
}

function playTone(context, frequency, duration) {
  const oscillator = context.createOscillator();
  const gainNode = context.createGain();

  oscillator.frequency.value = frequency;
  gainNode.gain.value = 0.3;  // Constant volume (matches Memory Chain)

  oscillator.connect(gainNode);
  gainNode.connect(context.destination);
  oscillator.start(context.currentTime);
  oscillator.stop(context.currentTime + duration / 1000);
}
```

**State Management:**
```javascript
let ws = null;
let currentTrainingState = 'idle';  // idle, playing, waiting_input, replay, skip
let currentCallsign = '';
let currentWPM = 0;
```

### API Endpoints

**`POST /api/hear-it/start`**
- Starts web-based Hear It Type It mode
- Body: `{"mode": 0-4, "length": 3-10, "customChars": "ABC..."}`
- Device applies settings to `hearItSettings` struct
- Switches device to `MODE_WEB_HEAR_IT`
- Returns: `{"status": "active", "endpoint": "ws://vail-summit.local/ws/hear-it"}`

**WebSocket: `/ws/hear-it`**
- Bidirectional communication for training session
- Device sends morse patterns and validation results
- Browser sends answers and control commands (replay/skip)

### Character Generation Algorithm

**Callsigns Mode:**
```cpp
String generateCharacterGroup() {
  String prefix = randomPrefix();         // 1-2 letters (e.g., "W", "K", "VE")
  String number = String(random(0, 10));  // 0-9
  String suffix = randomSuffix();         // 1-4 letters
  return prefix + number + suffix;        // e.g., "W1ABC"
}
```

**Other Modes:**
```cpp
String generateCharacterGroup() {
  String pool = getCharacterPool();  // Based on mode setting
  String group = "";
  for (int i = 0; i < hearItSettings.groupLength; i++) {
    group += pool[random(0, pool.length())];
  }
  return group;
}
```

**Character Pools:**
- Random Letters: `"ABCDEFGHIJKLMNOPQRSTUVWXYZ"`
- Random Numbers: `"0123456789"`
- Letters+Numbers: `"ABCDEFGHIJKLMNOPQRSTUVWXYZ0123456789"`
- Custom: `hearItSettings.customChars`

### Use Cases

**Beginner Training:**
- Start with MODE_RANDOM_LETTERS, length 3-4
- Focus on common letters ("ETIANMSURWDKGO")
- Use custom mode to practice specific problem characters
- Gradually increase length as proficiency improves

**Number Practice:**
- Use MODE_RANDOM_NUMBERS for contest exchanges
- Practice RST reports (599, 579, etc.)
- Build confidence with number recognition

**Callsign Copy:**
- Use MODE_CALLSIGNS to prepare for on-air work
- Realistic patterns match FCC/international formats
- Essential for contesting and casual QSOs

**Advanced Training:**
- Use MODE_LETTERS_NUMBERS with length 8-10
- Increase WPM speed (30+ WPM)
- Custom mode for procedural signs and punctuation

**Remote Training:**
- Use web interface to practice from computer
- Larger display easier to read than device LCD
- Settings adjustable without touching device
- Browser audio quality excellent for recognition

### Advantages of Web vs Device Mode

**Web Interface:**
- ✅ Larger display (computer monitor vs 240px LCD)
- ✅ Full keyboard for fast typing
- ✅ Settings panel always visible
- ✅ Better audio quality (dedicated speakers)
- ✅ Can train while device is across room
- ⚠️ Requires WiFi connection (battery drain)
- ⚠️ 10-50ms network latency for validation

**Device Mode:**
- ✅ Fully offline (no WiFi required)
- ✅ Portable and self-contained
- ✅ No computer needed
- ✅ Settings overlay available via 'S' key
- ⚠️ Small screen (harder to read)
- ⚠️ CardKB keyboard less comfortable for extended typing

### Implementation Status

**Completed Features:**
- ✅ 5 training modes with configurable settings
- ✅ Device implementation with settings overlay
- ✅ Web interface with full settings panel
- ✅ WebSocket bidirectional communication
- ✅ Browser audio playback using Web Audio API
- ✅ Persistent settings (ESP32 Preferences)
- ✅ Answer validation and feedback
- ✅ Replay and skip functionality
- ✅ Group length configuration (3-10 chars)
- ✅ Custom character set support

**Future Enhancements:**
- ⏳ Session statistics (accuracy percentage, average WPM)
- ⏳ Difficulty progression (auto-increase length/speed)
- ⏳ Prosign support (<AR>, <SK>, etc.)
- ⏳ Timed challenge mode (X correct answers in Y minutes)
- ⏳ Leaderboard for web users

## Morse Code Decoder

### Overview

The morse decoder provides real-time decoding of paddle/key input. Two decoder algorithms are bundled and runtime-selectable from CW Settings ("Decoder Type"):

- **Adaptive** — adapts WPM estimate from incoming timings using a weighted moving average. Best when the operator's speed varies or for decoding incoming morse from another op (Vail Repeater Decoder room).
- **Direct** — timer-driven, fixed-WPM. Faster character flush at the cost of not auto-adjusting to speed drift. Best when the operator keys at a known consistent WPM.

The selected decoder is used everywhere morse needs to be decoded on-device: Practice, CW Academy, LICW, Vail Master, Memory Chain, Morse Shooter, CW Speeder, Morse Notes, web Practice/Memory, and the Vail Repeater Decoder room.

Based on the open-source [morse-pro](https://github.com/scp93ch/morse-pro) JavaScript library by Stephen C Phillips, ported to C++ for ESP32.

### Architecture: Four-Module Design

**Module Structure:**
- **`morse_wpm.h`** - WPM timing utilities (PARIS standard formulas)
- **`morse_decoder.h`** - Base decoder class (timings → morse patterns → text), virtual methods for `addTiming` / `reset` / `tick`
- **`morse_decoder_adaptive.h`** - Adaptive speed tracking with weighted averaging
- **`morse_decoder_direct.h`** - Timer-driven flush at fixed WPM (subclass of `MorseDecoderAdaptive` for the timing classification, but overrides flush behavior)

The base class is virtual so callers can hold a `MorseDecoder*` and let the concrete class be selected at runtime via `decoderType` (defined in `src/settings/settings_decoder.h`).

### How It Works

**Input Format:**
- Decoder accepts timing values in milliseconds
- **Positive values** = tone ON (dit or dah)
- **Negative values** = silence (element gap, character gap, word gap)

**Adaptive Speed Algorithm:**

Every decoded element provides speed information:
- Dit → duration = 1 dit
- Dah → duration = 3 dits
- Character gap → duration = 3 fdits (Farnsworth)

The decoder maintains a circular buffer of the last 30 timing samples and uses **weighted averaging** (newer samples weighted more heavily: 1, 2, 3, ..., 30) to continuously refine its WPM estimate.

**Classification Thresholds:**
- Dit/Dah boundary: 2 × dit length
- Dah/Space boundary: 5 × Farnsworth dit length
- Noise threshold: 10ms (filters glitches)
- **Word gap stability:** fditLen locked to ditLen for consistent word detection (prevents threshold drift)

### Integration with Practice Mode

**Real-Time Decoding:**
- Enabled by default in practice mode
- Press 'D' key to toggle display on/off
- Modern card-style UI with three info panels:
  - **SET WPM** (cyan badge): Configured speed
  - **ACTUAL** (green badge): Detected WPM with color coding (green = matches, yellow = different)
  - **KEY TYPE** (yellow badge): Straight/Iambic A/Iambic B
- Decoder display shows 2 lines of decoded text (17 chars per line, size 3 font)
- Supports 9 prosigns: AR, AS, BK, BT, CT, HH, SK, SN, SOS (displayed as `<AR>`, etc.)
- Hovering colored badges for visual hierarchy
- Arrow keys adjust speed (up/down) and key type (left/right)

**Timing Capture:**
- **Straight Key:** Measures tone-on and silence durations directly
- **Iambic:** Uses element start/stop times from iambic state machine
- Feeds timings to decoder after each element completes
- **First-run initialization:** `lastStateChangeTime` set to 0 to prevent spurious decoding on first entry
- Only calculates durations after first valid key press

**UI Update Strategy:**
- Decoder callback sets `needsUIUpdate = true`
- Main loop checks flag after `updatePracticeOscillator()`
- **Only updates when tone is NOT playing** to avoid audio glitches
- Calls `drawDecodedTextOnly()` for partial screen update
- Full redraw avoided during practice for best audio performance

**Auto-Flush Logic:**
- Character boundary detection: 2.5 dits of silence triggers automatic flush (in `addTiming()`)
- Backup timeout: Word gap duration (7 dits) for mid-character abandonment (in `updatePracticeOscillator()`)
- Prevents premature character splitting due to timing jitter
- Ensures real-time character display without waiting for next element
- Character overflow protection: Auto-clears after 34 characters (17 chars × 2 lines)

### Performance

**Memory Footprint:**
- `MorseDecoderAdaptive` instance: ~1-2 KB
- Decoded text buffers (200 chars): ~200 bytes
- Timing buffers (30 samples × 2): ~240 bytes
- **Total: ~2.5 KB** (negligible on ESP32-S3)

**CPU Usage:**
- Decoder processing: <1ms per character
- No floating-point intensive operations
- Real-time suitable for ESP32 at 240 MHz

### Licensing

The morse decoder modules are licensed under **EUPL v1.2** (European Union Public Licence):

- Original code: Copyright (c) 2024 Stephen C Phillips
- ESP32 port: Copyright (c) 2025 VAIL SUMMIT Contributors
- **Weak copyleft** - can be used in proprietary firmware
- **Must keep decoder modules open source** if modified
- Compatible with GPL, LGPL, MPL

Main VAIL SUMMIT firmware can remain under any license. Only the four decoder modules (`morse_wpm.h`, `morse_decoder.h`, `morse_decoder_adaptive.h`, `morse_decoder_direct.h`) are EUPL-licensed.

### Future Applications

The decoder is designed as a reusable component for:

1. **Receive training** - Decode audio from I2S microphone (requires tone detection)
2. **Accuracy metrics** - Compare intended vs. decoded patterns
3. **Contest logging** - Real-time callsign/exchange capture

(CW Academy validation and Vail Repeater Decoder-room decoding are already shipping as of v0.527+.)

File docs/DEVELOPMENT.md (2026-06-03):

# Development Guide

This document covers building, development patterns, critical constraints, and troubleshooting for VAIL SUMMIT development.

## Building the Firmware

### Required: Use Bundled Arduino CLI

This project uses a **standalone Arduino CLI environment** with pinned library and ESP32 core versions located in the `arduino-cli/` folder. This ensures reproducible builds across all development machines.

**NEVER use a system-installed Arduino CLI or Arduino IDE** - always use the bundled version to ensure correct library versions.

### Building on Windows (Recommended Method)

Due to Windows path length limitations (260 char limit), the standard build script often fails. **Use the short-path method instead:**
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

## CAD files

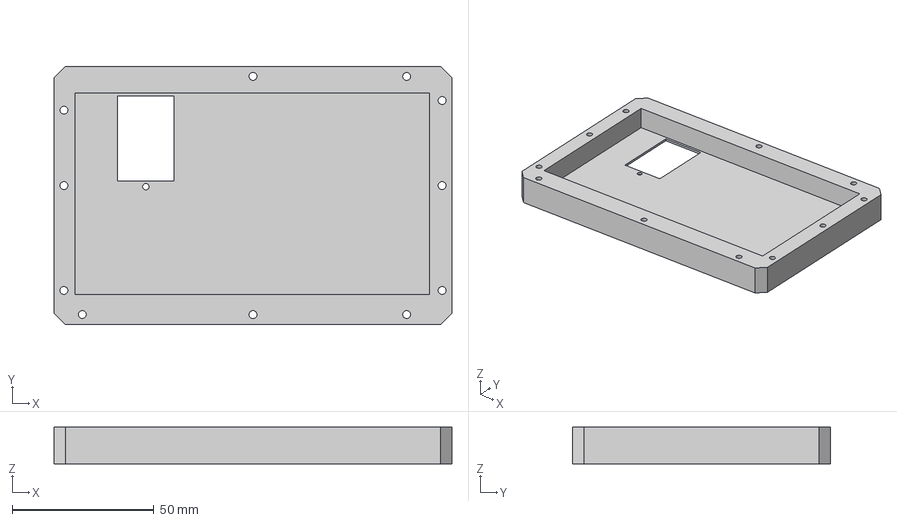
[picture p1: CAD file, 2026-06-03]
3d prints/battery bottom.3mf
140.4 x 91.0 x 13.0 mm

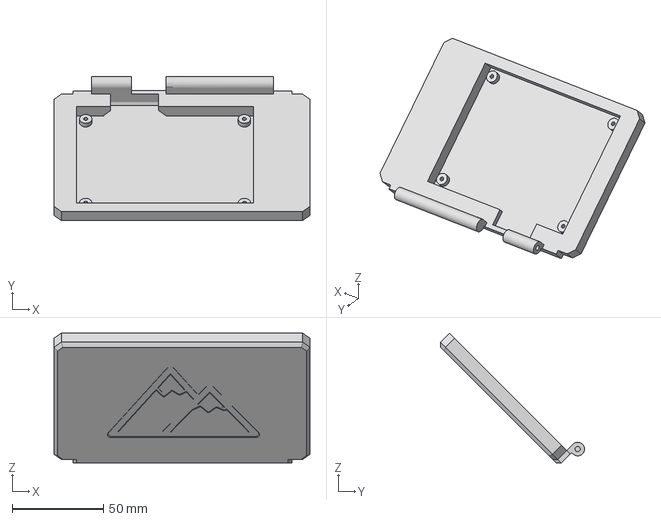
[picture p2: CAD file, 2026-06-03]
3d prints/summitkybdvinalv1.3mf
140.4 x 79.0 x 71.2 mm

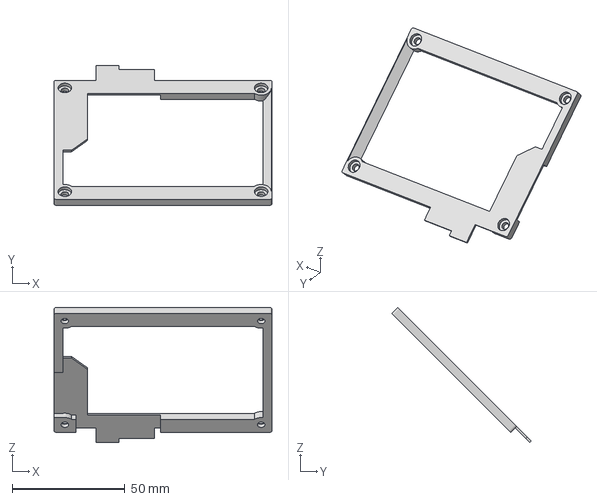
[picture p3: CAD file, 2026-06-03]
3d prints/keyboard top trim.3mf
96.6 x 61.9 x 59.9 mm

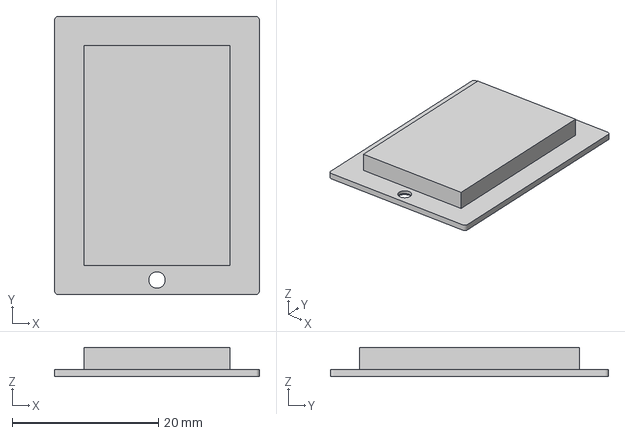
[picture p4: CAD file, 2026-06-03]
3d prints/expansion hatch.3mf
28.0 x 38.0 x 4.00 mm

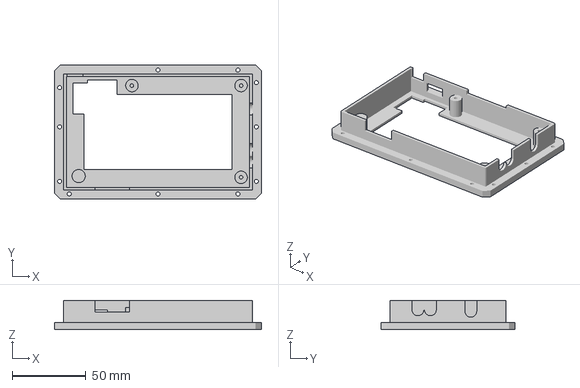
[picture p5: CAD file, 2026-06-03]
3d prints/summitbodybatterymod.3mf
140.4 x 91.0 x 20.0 mm

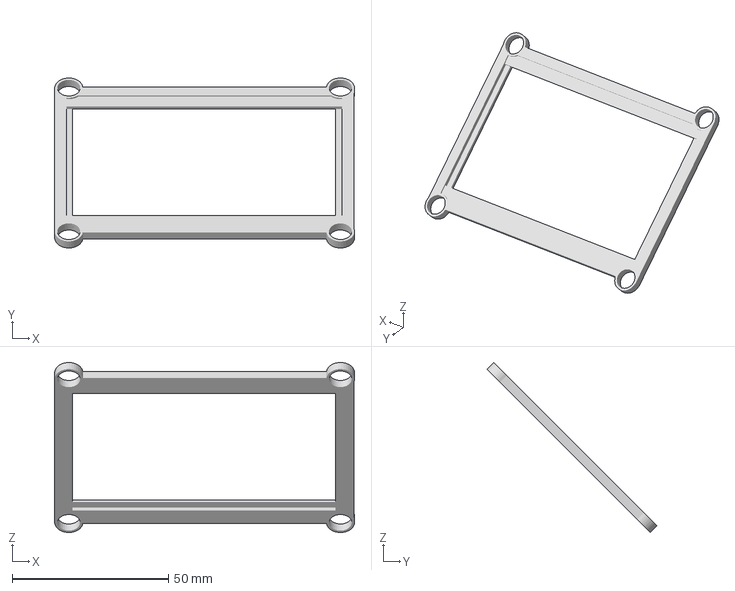
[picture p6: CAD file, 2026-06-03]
3d prints/keyboard trim.3mf
96.1 x 54.4 x 54.4 mm

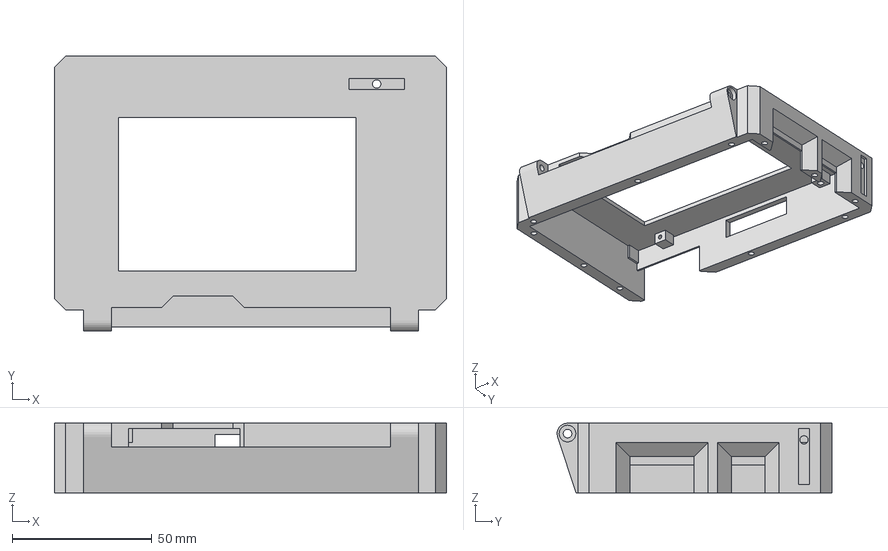
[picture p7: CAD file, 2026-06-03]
3d prints/summittopfinalv1.3mf
140.4 x 98.4 x 25.0 mm

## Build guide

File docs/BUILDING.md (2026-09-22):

# Building and Development

This document covers build setup, compilation, upload, and firmware updates for the VAIL SUMMIT morse code trainer.

## Arduino IDE Setup

### Board Configuration

Select **Adafruit Feather ESP32-S3 2MB PSRAM** from the boards menu, then configure:

| Setting | Value | Notes |
|---|---|---|
| **Board** | Adafruit Feather ESP32-S3 2MB PSRAM | Not "No PSRAM" variant |
| **USB CDC On Boot** | Enabled | Required for serial output |
| **USB Mode** | Hardware CDC and JTAG | **NOT TinyUSB** - TinyUSB causes boot failures |
| **Upload Mode** | UART0 / Hardware CDC | |
| **Flash Size** | 4MB (32Mb) | |
| **PSRAM** | QSPI PSRAM | **NOT OPI** - OPI causes PSRAM detection failures |
| **Partition Scheme** | Huge APP (3MB No OTA/1MB SPIFFS) | Provides 3MB app space + 1MB storage |
| **Upload Speed** | 921600 | |

**⚠️ Critical Settings:**
- **USB Mode must be "Hardware CDC and JTAG"** - Using "USB-OTG (TinyUSB)" will cause the device to crash before any serial output appears
- **PSRAM must be "QSPI PSRAM"** - The Adafruit Feather ESP32-S3 2MB PSRAM uses QSPI, not OPI. Using OPI will cause PSRAM detection to fail with error: `E (360) opi psram: PSRAM ID read error`

### ESP32 Core Version

**IMPORTANT:** This project requires **Arduino ESP32 core version 2.0.14** for display compatibility (especially for 4" ST7796S displays).

**To install/verify in Arduino IDE:**
1. Go to Tools → Board → Boards Manager
2. Search for "esp32"
3. Find "esp32 by Espressif Systems"
4. Select version **2.0.14** from dropdown
5. Click "Install" or verify current version

**Note:** Newer core versions (2.0.15+, 3.0.x) have compatibility issues with the ST7796S display driver that cause boot loops. Always use 2.0.14 for this project.

### Required Libraries

Install via Arduino Library Manager:

1. **LovyanGFX by lovyan03** - Advanced display graphics library for ST7796S 4.0" display
2. **lvgl v8.3.x** - UI framework (**must be v8.3.x, NOT v9.x** - API incompatible)
3. **Adafruit MAX1704X** - Battery monitoring for MAX17048
4. **Adafruit LC709203F** - Backup battery monitor support
5. **WebSockets by Markus Sattler** - WebSocket client for Vail repeater
6. **ArduinoJson by Benoit Blanchon** - JSON parsing/serialization
7. **NimBLE-Arduino** - Bluetooth Low Energy for BLE HID/MIDI

**Install from GitHub** (not in Library Manager):
- **ESPAsyncWebServer** - `https://github.com/me-no-dev/ESPAsyncWebServer`
- **AsyncTCP** - `https://github.com/me-no-dev/AsyncTCP` (dependency for ESPAsyncWebServer)

**⚠️ LVGL Version:** This project requires LVGL 8.3.x. LVGL 9.x has breaking API changes and will not compile. If using Arduino Library Manager, ensure you install version 8.3.11 or similar 8.3.x version.

**Note:** This project uses a 4.0" ST7796S display (480×320) with LovyanGFX library instead of the older Adafruit ST7789 library.

### Compilation and Upload

**Arduino IDE:**
```bash
# Open the main sketch in Arduino IDE
arduino morse_trainer/morse_trainer_menu.ino
```

**Arduino CLI:**
```bash
# Compile with required board options
arduino-cli compile \
  --fqbn "esp32:esp32:adafruit_feather_esp32s3:CDCOnBoot=cdc,PartitionScheme=huge_app,PSRAM=enabled,FlashSize=4M" \
  vail-summit/

# Upload (replace COM<X> with your port)
arduino-cli upload -p COM<X> \
  --fqbn "esp32:esp32:adafruit_feather_esp32s3:CDCOnBoot=cdc,PartitionScheme=huge_app,PSRAM=enabled,FlashSize=4M" \
  vail-summit/
```

**FQBN Options Explained:**
- `CDCOnBoot=cdc` - Enable USB CDC for serial output
- `PartitionScheme=huge_app` - 3MB app space, 1MB SPIFFS
- `PSRAM=enabled` - Enable PSRAM (auto-detects QSPI/OPI)
- `FlashSize=4M` - 4MB flash

### Serial Monitor

```bash
# Connect at 115200 baud for debug output
arduino-cli monitor -p COM<X> --config baudrate=115200
```

Debug output includes:
- I2C device detection (CardKB, battery monitor)
- WiFi connection status
- File system operations
- QSO logging activity
- Web server lifecycle events

## Firmware Version Management

### Version Information Location

`config.h` (lines 9-14):

```cpp
#define FIRMWARE_VERSION "1.0.0"
#define FIRMWARE_DATE "2025-01-30"  // Update this date each time you build new firmware
#define FIRMWARE_NAME "VAIL SUMMIT"
```

### When to Update

**FIRMWARE_VERSION:** Increment for major releases
- **Major version** (1.x.x → 2.x.x): Breaking changes or major new features
- **Minor version** (x.1.x → x.2.x): New features, backward compatible
- **Patch version** (x.x.1 → x.x.2): Bug fixes only

**FIRMWARE_DATE:** Update to current date (YYYY-MM-DD) **every time** you build firmware for distribution

**FIRMWARE_NAME:** Should remain "VAIL SUMMIT" unless device name changes

### Where Version Appears

- Web dashboard footer
- System Info page (version + build date)
- Serial output on startup
- ADIF export headers

**Important:** Always update FIRMWARE_DATE before building firmware, even if FIRMWARE_VERSION stays the same. This helps track when a specific build was created.

## Firmware Updates

VAIL SUMMIT firmware can be updated via:

1. **Web-based flasher** at `https://update.vailadapter.com` (recommended for users)
2. **Arduino IDE** (for developers)

### Repository Integration

**Important:** This is the Vail Summit source code in the Vail-CW/vail-summit repository. The default branch is `main`.

**How users get firmware:**

The web flasher at `https://update.vailadapter.com` reads its dropdown from this repository's GitHub Releases via the GitHub API:
- "Latest" entry = most recent non-prerelease
- "Test Release" entry = most recent prerelease (visible when "Show test release" is checked)

To make a build appear in the flasher, a corresponding GitHub Release must exist on `Vail-CW/vail-summit` with the three binaries (`vail-summit.bin`, `bootloader.bin`, `partitions.bin`) attached as assets.

### Building Firmware for Distribution

#### Option 1: Build-and-Release Workflow (Recommended)

The repository includes a GitHub Actions workflow that builds the firmware AND publishes a GitHub Release in a single dispatch. The release is what the flasher reads.

1. Go to the **Actions** tab on GitHub
2. Select **"Build and Release Summit Firmware"**
3. Click **"Run workflow"**
4. Set inputs:
   - **`source_branch`** (default: `main`) — the branch to build from
   - **`release_type`** (default: `prerelease`):
     - `prerelease` — appears as the **Test Release** entry in the flasher dropdown
     - `release` — appears as **Latest** in the flasher dropdown
     - `none` — build only, attach artifacts to the workflow run, no release
   - **`release_title`** (optional) — custom title; defaults to `vX.YZ - Test Release` / `Release`
   - **`release_notes`** (optional) — body markdown; defaults to a minimal template
   - **`psram`** (default: `enabled`) - leave it enabled for normal builds. `disabled` makes a build that acts like the 8MB no-PSRAM Feather (#5323), which runs on either board, so testers can try it on what they already have. A no-PSRAM build gets "(no PSRAM)" on the default title, a PSRAM line in the default notes, and a `-no-psram` suffix on the workflow artifact. The `.bin` names do not change, because the flasher looks for them by name.
5. Click the green **"Run workflow"** button

The workflow:
- Installs the pinned ESP32 core 2.0.14 and the pinned third-party libraries (LovyanGFX 1.1.16, lvgl 8.3.11, NimBLE-Arduino 1.4.2, ArduinoJson 7.0.4, ESP Async WebServer 3.6.0, etc. — versions live as `env:` vars at the top of the workflow file)
- Copies the in-repo `lv_conf.h` next to the lvgl library so LVGL finds its config
- Compiles with `--clean` and `-mtext-section-literals` for a clean reproducible build
- Captures `FIRMWARE_VERSION` from `src/core/config.h` and uses it to derive the tag (e.g. `v0.529`)
- If a release with that tag already exists, deletes and re-publishes it with the new binaries (useful for iterative test builds at the same `FIRMWARE_VERSION`)
- Uploads build artifacts to the workflow run for 30-day retention regardless of release type

#### Option 2: Manual Build (Windows - Recommended Method)

Due to Windows path length limitations (260 char limit), use the short-path method:

**One-Time Setup:**
```powershell
# Create junction for project (short path)
New-Item -ItemType Junction -Path 'C:\vs' -Target 'C:\Users\brett\Documents\Coding Projects\vail-summit'

# Copy arduino-cli to short path (required - arduino-cli resolves real paths internally)
Copy-Item -Path 'C:\vs\arduino-cli\*' -Destination 'C:\acli' -Recurse -Force

# Sync lv_conf.h next to the lvgl library so LVGL finds its config (must repeat
# any time the repo's lv_conf.h changes)
Copy-Item -Force 'C:\vs\lv_conf.h' 'C:\acli\user\libraries\lv_conf.h'
```

**Compiling:**
```powershell
cd C:\acli
.\arduino-cli.exe compile --config-file arduino-cli.yaml --fqbn "esp32:esp32:adafruit_feather_esp32s3:CDCOnBoot=cdc,PartitionScheme=huge_app,PSRAM=enabled,FlashSize=4M,USBMode=hwcdc" --output-dir C:\vs\build --export-binaries C:\vs
```

The compiled binaries land in `C:\vs\build\` as `vail-summit.ino.bin`, `vail-summit.ino.bootloader.bin`, and `vail-summit.ino.partitions.bin`. To distribute via the flasher, attach them to a GitHub Release on `Vail-CW/vail-summit` (or use Option 1 instead, which does this for you).

#### Option 3: Manual Build (Linux/macOS)

No path length issues on Linux/macOS:

```bash
cd arduino-cli
# Sync lv_conf.h next to the lvgl library
cp ../lv_conf.h user/libraries/lv_conf.h

./arduino-cli compile --config-file arduino-cli.yaml \
  --fqbn "esp32:esp32:adafruit_feather_esp32s3:CDCOnBoot=cdc,PartitionScheme=huge_app,PSRAM=enabled,FlashSize=4M,USBMode=hwcdc" \
  --output-dir ../build --export-binaries ..
```

**Firmware Stats:**
- Bootloader: ~15KB
- Partitions: ~3KB
- Application: ~2.4MB
- Total flash time: ~30 seconds

### Web-Based Flasher Details

The web updater at `https://update.vailadapter.com` uses **esptool-js** for browser-based flashing.

**Two-Step Process:**

1. **Step 1: Enter Bootloader Mode**
   - User selects device in normal mode (e.g., COM31)
   - Tool triggers 1200 baud reset to enter bootloader
   - Device reconnects with new COM port (e.g., COM32)

2. **Step 2: Connect and Flash**
   - User selects device in bootloader mode
   - Tool flashes all three binary files with progress indicators
   - User unplugs/replugs device after flashing completes

**Technical Implementation:**
- Uses Web Serial API (Chrome/Edge/Opera only)
- Converts firmware to binary strings for esptool-js compatibility
- MD5 verification disabled to avoid format issues
- Real-time progress indicators for each file
- Dark mode UI matching site theme

See `SUMMIT_INTEGRATION.md` in the vail-summit repository for complete technical details.

## Deep Sleep Power Management

**Entering sleep:** Triple-tap ESC in main menu within 2 seconds

**Wake source:** DIT paddle press (GPIO 6)

**Power consumption:**
- Active (WiFi on): ~200mA
- Active (WiFi off): ~100mA
- Deep sleep: ~20µA

Device performs full restart from `setup()` after wake.

## Troubleshooting

### Device won't boot / No serial output

**Symptom:** Device flashes successfully but crashes immediately with no serial output. COM port disappears until using physical boot/reset buttons.

**Cause:** Wrong USB Mode setting.

**Fix:** In Arduino IDE, change Tools → USB Mode to **"Hardware CDC and JTAG"** (not "USB-OTG (TinyUSB)").

### PSRAM detection failure

**Symptom:** Serial output shows `E (360) opi psram: PSRAM ID read error: 0x00000000` and device fails to boot properly.

**Cause:** Wrong PSRAM type selected.

**Fix:** In Arduino IDE, change Tools → PSRAM to **"QSPI PSRAM"** (not "OPI PSRAM"). The Adafruit Feather ESP32-S3 2MB PSRAM board uses QSPI PSRAM.

### LVGL display buffer allocation failed

**Symptom:** Serial output shows `[LVGL] ERROR: Failed to allocate display buffers!`

**Cause:** PSRAM not properly initialized, usually due to wrong PSRAM setting in build options.

**Fix:** Ensure firmware is compiled with correct PSRAM setting. For GitHub Actions builds, the workflow uses `PSRAM=enabled`. For Arduino IDE, use "QSPI PSRAM".

### Build errors with LVGL 9.x

**Symptom:** Compilation fails with errors like `'getLVGLInputGroup' was not declared`, `lv_msgbox_create` wrong number of arguments, or `LV_INDEV_STATE_PRESSED` not found.

**Cause:** LVGL 9.x installed instead of 8.3.x.

**Fix:** Uninstall LVGL 9.x and install LVGL 8.3.11 (or any 8.3.x version). The APIs changed significantly between v8 and v9.

### Display shows wrong colors or garbled output

**Symptom:** Display works but colors are inverted or image is corrupted.

**Cause:** Wrong ESP32 core version or display configuration.

**Fix:** Ensure Arduino ESP32 core version 2.0.14 is installed. Newer versions (2.0.15+, 3.x) have compatibility issues with the ST7796S display.

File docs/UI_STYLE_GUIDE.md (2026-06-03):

# VAIL SUMMIT UI Style Guide

**Version:** 2.0
**Last Updated:** 2025-01-10
**Design System:** Modern Minimal with Pastel Blue-Green Palette

---

## Overview

VAIL SUMMIT uses a clean, modern minimal design system inspired by iOS and contemporary mobile interfaces. This guide ensures visual consistency across all features and screens.

## Design Principles

1. **Solid Colors Only** - No banding or fake gradients (RGB565 limitation)
2. **Pastel Palette** - Subtle, muted blue-green colors throughout
3. **iOS-like Aesthetics** - Clean, minimal, modern design
4. **Clear Visual Hierarchy** - Text and element importance through color and size
5. **Context-Aware Accents** - Colors match content purpose (volume, brightness, status)

---

## Color Palette

### Background Colors

Foundation colors for the interface:

```cpp
COLOR_BG_DEEP           0x0841  // RGB(15, 20, 35) - Deep dark background
COLOR_BG_LAYER2         0x1082  // RGB(20, 30, 50) - Subtle raised layer
```

**Usage:**
- BG_DEEP: Main screen background
- BG_LAYER2: Card backgrounds, containers

### Card & Surface Colors (Pastel Blue-Green)

Solid pastel colors for cards and interactive elements:

```cpp
COLOR_CARD_BLUE         0x32AB  // RGB(50, 85, 90) - Soft muted blue
COLOR_CARD_TEAL         0x2B0E  // RGB(40, 95, 115) - Soft teal
COLOR_CARD_CYAN         0x3471  // RGB(50, 140, 140) - Muted cyan
COLOR_CARD_MINT         0x3D53  // RGB(60, 170, 155) - Soft mint
```

**Usage:**
- Use solid colors for cards (no gradients)
- Rotate through palette for variety (e.g., practice cards use teal, cyan, mint)
- Selection highlights: `COLOR_CARD_CYAN`

### Accent Colors (Subtle Highlights)

Brighter accents for important elements:

```cpp
COLOR_ACCENT_BLUE       0x4D5F  // RGB(75, 170, 255) - Soft bright blue
COLOR_ACCENT_CYAN       0x5EB9  // RGB(90, 215, 210) - Soft cyan accent
COLOR_ACCENT_GREEN      0x5712  // RGB(85, 225, 150) - Soft green accent
```

**Usage:**
- Icon circles, selected values, active states
- Use sparingly for emphasis

### Status Colors (Pastels)

Soft status indicators:

```cpp
COLOR_SUCCESS_PASTEL    0x4E91  // RGB(75, 210, 140) - Soft pastel green
COLOR_WARNING_PASTEL    0xFE27  // RGB(255, 195, 60) - Soft pastel orange
COLOR_ERROR_PASTEL      0xFACB  // RGB(250, 90, 90) - Soft pastel red
```

**Usage:**
- SUCCESS: Connected states, high battery, good values
- WARNING: Connecting, medium levels, caution
- ERROR: Disconnected, low battery, errors

### Border & Outline Colors

Subtle borders for depth:

```cpp
COLOR_BORDER_SUBTLE     0x39EC  // RGB(55, 65, 100) - Very subtle border
COLOR_BORDER_LIGHT      0x632C  // RGB(100, 100, 100) - Light neutral border
COLOR_BORDER_ACCENT     0x6D7F  // RGB(110, 170, 255) - Soft blue border
```

**Usage:**
- SUBTLE: Card outlines, container borders
- LIGHT: Progress bars, icon outlines
- ACCENT: Selection highlights, active borders

### Text Hierarchy Colors

Establish clear visual priority:

```cpp
COLOR_TEXT_PRIMARY      0xFFFF  // RGB(255, 255, 255) - White (main text)
COLOR_TEXT_SECONDARY    0xBDF7  // RGB(190, 190, 190) - Light gray (labels)
COLOR_TEXT_TERTIARY     0x8410  // RGB(130, 130, 130) - Medium gray (hints)
COLOR_TEXT_DISABLED     0x5ACB  // RGB(90, 90, 90) - Dark gray (inactive)
```

**Usage:**
- PRIMARY: Main content, values, headings, selected text
- SECONDARY: Labels, unselected items
- TERTIARY: Hints, placeholders
- DISABLED: Inactive states

### Background Color

```cpp
COLOR_BACKGROUND        COLOR_BG_DEEP  // Dark background (never pure black)
```

**Rule:** NEVER use pure black (0x0000). Always use COLOR_BACKGROUND or COLOR_BG_DEEP.

---

## Layout Constants

### Screen Dimensions

```cpp
SCREEN_WIDTH            480     // Display width
SCREEN_HEIGHT           320     // Display height
HEADER_HEIGHT           45      // Top status bar (reduced for better proportions)
FOOTER_HEIGHT           30      // Bottom instruction bar
```

### Common Dimensions

```cpp
CARD_MAIN_WIDTH         450     // Main menu card width
CARD_MAIN_HEIGHT        80      // Main menu card height
CARD_STACK_WIDTH_1      405     // First stacked card
CARD_STACK_WIDTH_2      375     // Second stacked card
STATUS_ICON_SIZE        12      // Battery/WiFi icon height
```

---

## Component Patterns

### 1. Clean Container Card

**Standard Pattern:**

```cpp
// Example: Settings screen, info display

int cardX = 20;
int cardY = 60;
int cardW = SCREEN_WIDTH - 40;  // 20px margins
int cardH = 150;

// Solid card background (no gradients)
display.fillRoundRect(cardX, cardY, cardW, cardH, 10, COLOR_BG_LAYER2);

// Subtle border
display.drawRoundRect(cardX, cardY, cardW, cardH, 10, COLOR_BORDER_SUBTLE);
```

**Rules:**
- Use solid colors only (no banding/gradients)
- 10px radius for cards, 8px for smaller elements
- Single subtle border (no double borders or glow)
- No shadow layers or shimmer effects

### 2. Info Card (Practice Mode)

**For displaying key metrics (speed, WPM, key type):**

```cpp
// Example: Practice mode info cards

int cardX = 10;
int cardY = 75;
int cardW = 155;
int cardH = 50;

// Solid card background (use pastel color from palette)
display.fillRoundRect(cardX, cardY, cardW, cardH, 8, COLOR_CARD_TEAL);

// Subtle border
display.drawRoundRect(cardX, cardY, cardW, cardH, 8, COLOR_BORDER_SUBTLE);

// Label at top (small, inside card)
display.setTextSize(1);
display.setTextColor(COLOR_TEXT_SECONDARY);
display.setCursor(cardX + 8, cardY + 8);
display.print("SET WPM");

// Value text (centered, large)
display.setFont(&FreeSansBold18pt7b);
display.setTextSize(1);
display.setTextColor(COLOR_TEXT_PRIMARY);
display.setCursor(cardX + (cardW - w) / 2, cardY + 36);  // Properly centered
display.print(value);
display.setFont(nullptr);
```

**Card Color Rotation:**
- Card 1: `COLOR_CARD_TEAL`
- Card 2: `COLOR_CARD_CYAN`
- Card 3: `COLOR_CARD_MINT`

### 3. Progress Bar (Solid Fill)

**Clean progress bars with single color:**

```cpp
// Example: Volume/Brightness bars

int barX = cardX + 20;
int barY = cardY + 70;
int barW = cardW - 40;
int barH = 14;

// Bar container (dark background)
display.fillRoundRect(barX, barY, barW, barH, 7, COLOR_BG_DEEP);

// Filled portion (solid color based on level)
int fillW = (barW * value) / 100;
if (fillW > 0) {
  uint16_t fillColor;
  if (value > 70) {
    fillColor = COLOR_ACCENT_CYAN;      // High
  } else if (value > 30) {
    fillColor = COLOR_CARD_CYAN;        // Medium
  } else {
    fillColor = COLOR_CARD_TEAL;        // Low
  }

  display.fillRoundRect(barX + 2, barY + 2, fillW - 4, barH - 4, 5, fillColor);
}

// Border on bar
display.drawRoundRect(barX, barY, barW, barH, 7, COLOR_BORDER_LIGHT);
```

**Rules:**
- Use solid colors only (no banding)
- Choose color based on value/context
- Keep consistent with overall pastel palette

### 4. Selection Highlight

**For interactive lists, settings rows:**

```cpp
// When item is selected

if (isSelected) {
  // Solid highlight background
  display.fillRoundRect(itemX, itemY, itemW, itemH, 8, COLOR_CARD_CYAN);

  // Accent border
  display.drawRoundRect(itemX, itemY, itemW, itemH, 8, COLOR_BORDER_ACCENT);
}

// Text color changes
display.setTextColor(isSelected ? COLOR_TEXT_PRIMARY : COLOR_TEXT_SECONDARY);
```

**Rules:**
- Background: `COLOR_CARD_CYAN` for selections
- Single border with `COLOR_BORDER_ACCENT`
- Text: white when selected, light gray when not

### 5. Menu Card (Main Selected)

**The signature VAIL SUMMIT card design:**

```cpp
int mainCardX = (SCREEN_WIDTH - CARD_MAIN_WIDTH) / 2;
int mainCardY = 110;

// Solid pastel background (no gradients)
tft.fillRoundRect(mainCardX, mainCardY, CARD_MAIN_WIDTH, CARD_MAIN_HEIGHT, 12, COLOR_CARD_CYAN);

// Clean border
tft.drawRoundRect(mainCardX, mainCardY, CARD_MAIN_WIDTH, CARD_MAIN_HEIGHT, 12, COLOR_BORDER_ACCENT);

// Icon circle (simple, clean)
int iconX = mainCardX + 40;
int iconY = mainCardY + 40;

// Solid icon circle
tft.fillCircle(iconX, iconY, 26, COLOR_ACCENT_BLUE);
tft.drawCircle(iconX, iconY, 26, COLOR_BORDER_LIGHT);

// Icon letter (clean white, no shadow)
tft.setFont(&FreeSansBold18pt7b);
tft.setTextColor(ST77XX_WHITE);
tft.setCursor(mainCardX + 30, mainCardY + 25);
tft.print(icon);

// Menu text (clean, no shadow)
tft.setCursor(mainCardX + 85, mainCardY + 25);
tft.print(menuText);

// Simple arrow indicator
tft.fillTriangle(mainCardX + CARD_MAIN_WIDTH - 30, mainCardY + 32,
                 mainCardX + CARD_MAIN_WIDTH - 30, mainCardY + 48,
                 mainCardX + CARD_MAIN_WIDTH - 15, mainCardY + 40, COLOR_TEXT_PRIMARY);
```

**Critical Pattern:**
- Solid pastel card color
- Single clean border
- Simple solid icon circle
- No shadows, no glow effects
- Clean text alignment

### 6. Stacked Cards (Background/Preview)

**For carousel/preview effects:**

```cpp
// Stacked card (next/previous item)
int stackY = mainCardY + CARD_MAIN_HEIGHT + 12;

// Solid dimmed background
display.fillRoundRect(stackX, stackY, stackW, stackH, 8, COLOR_BG_LAYER2);

// Subtle border
display.drawRoundRect(stackX, stackY, stackW, stackH, 8, COLOR_BORDER_SUBTLE);

// Small icon circle
display.fillCircle(stackX + 18, stackY + 16, 12, COLOR_CARD_BLUE);
display.drawCircle(stackX + 18, stackY + 16, 12, COLOR_BORDER_SUBTLE);

// Icon and text use secondary/tertiary colors
display.setTextColor(COLOR_TEXT_SECONDARY);
```

**Rules:**
- Darker solid backgrounds = further back in visual stack
- Smaller size, less detail = visual hierarchy
- Text: secondary or tertiary colors only

---

## Typography

### Font Sizes

```cpp
FreeSansBold18pt7b  // Main headings, selected items, large values
FreeSansBold12pt7b  // Menu text, settings labels, card headers
FreeSansBold9pt7b   // Secondary items, stacked cards, footer text
nullptr (default)   // Fallback for basic UI elements
```

### Text Color Usage

| Context | Color | Use Case |
|---|---|---|
| Primary content | `COLOR_TEXT_PRIMARY` | Main values, headings, selected items |
| Labels | `COLOR_TEXT_SECONDARY` | Field labels, descriptions |
| Hints | `COLOR_TEXT_TERTIARY` | Placeholder text, less important info |
| Disabled | `COLOR_TEXT_DISABLED` | Inactive elements, shadows |
| Success | `COLOR_GREEN_ACCENT` | Positive values, connected states |
| Warning | `COLOR_WARNING_NEW` | Caution, medium states |
| Error | `COLOR_ERROR_NEW` | Errors, low values, disconnected |
| Info | `COLOR_CYAN` | Neutral highlight, set values |

### Text Shadow (Optional Depth)

For large text on gradients, add subtle shadow:

```cpp
// Shadow (1px offset, dark color)
display.setTextColor(COLOR_TEXT_DISABLED);
display.setCursor(x + 1, y + 1);
display.print(text);

// Main text (white)
display.setTextColor(COLOR_TEXT_PRIMARY);
display.setCursor(x, y);
display.print(text);
```

---

## Spacing & Dimensions

### Corner Radius Standards

| Element Type | Radius | Use Case |
|---|---|---|
| Large cards | 10-12px | Settings containers, main cards |
| Medium cards | 8-10px | Info cards, decoder boxes |
| Small elements | 7-8px | Progress bars, badges |
| Icon circles | 26px (diameter 52px) | Menu icon circles |

### Padding & Margins

| Element | Spacing | Notes |
|---|---|---|
| Screen margins | 20px | Left/right margins for full-width cards |
| Card padding | 15px | Internal padding from edges |
| Label position | 8px from top | Labels inside cards |
| Line spacing | 45px | Vertical spacing between settings rows |
| Card gap | 4-12px | Space between stacked cards |

### Safe Zones

```
Screen: 480×320

Header: 0-45 (reserved - reduced height)
Footer: 308-320 (reserved for help text)
Content area: 47-306 (safe zone for UI elements)

Horizontal margins: 15-30px recommended
```

---

## Header & Footer Patterns

### Clean Minimal Header

```cpp
void drawHeader() {
  // Clean solid background
  tft.fillRect(0, 0, SCREEN_WIDTH, HEADER_HEIGHT, COLOR_BG_LAYER2);

  // Subtle bottom border
  tft.drawLine(0, HEADER_HEIGHT, SCREEN_WIDTH, HEADER_HEIGHT, COLOR_BORDER_SUBTLE);

  // Title (vertically centered)
  tft.setFont(&FreeSansBold12pt7b);  // Smaller font
  tft.setTextColor(COLOR_TEXT_PRIMARY);
  tft.setCursor(15, 28);  // y=28 for vertical center in 45px header
  tft.print(title);
  tft.setFont(nullptr);

  // Status icons (properly sized and positioned)
  drawStatusIcons();
}
```

**Rules:**
- Always 45px tall (HEADER_HEIGHT - reduced for better proportions)
- Use FreeSansBold12pt7b for title (not 18pt)
- Title at y=28 for perfect vertical centering
- Single subtle border at bottom

### Footer

```cpp
void drawFooter() {
  display.setFont(&FreeSansBold9pt7b);
  display.setTextColor(COLOR_WARNING_PASTEL);  // Soft pastel orange

  String helpText = "UP/DN Navigate   ENTER Select   ESC Back";

  // Center text
  int16_t x1, y1;
  uint16_t w, h;
  getTextBounds_compat(display, helpText.c_str(), 0, 0, &x1, &y1, &w, &h);
  int centerX = (SCREEN_WIDTH - w) / 2;

  display.setCursor(centerX, SCREEN_HEIGHT - 22);
  display.print(helpText);
  display.setFont(nullptr);
}
```

**Rules:**
- Use COLOR_WARNING_PASTEL (soft pastel orange)
- Single line, centered
- Position at y = SCREEN_HEIGHT - 22 (298px)

---

## Status Icons

### Battery Icon (Clean Minimal)

```cpp
// Clean battery outline (24x12)
int battW = 24;
int battH = 12;

tft.drawRoundRect(x, y, battW, battH, 2, COLOR_BORDER_LIGHT);

// Battery nub (small terminal)
tft.fillRect(x + battW, y + 4, 2, 4, COLOR_BORDER_LIGHT);

// Determine fill color based on level
uint16_t fillColor;
if (batteryPercent > 60) {
  fillColor = COLOR_SUCCESS_PASTEL;  // Soft green for high
} else if (batteryPercent > 20) {
  fillColor = COLOR_ACCENT_CYAN;     // Soft cyan for medium
} else {
  fillColor = COLOR_ERROR_PASTEL;    // Soft red for low
}

// Solid fill (no banding)
int fillWidth = (batteryPercent * (battW - 4)) / 100;
if (fillWidth > 0) {
  tft.fillRect(x + 2, y + 2, fillWidth, battH - 4, fillColor);
}
```

### WiFi Icon (Clean Simple Bars)

```cpp
// Simple WiFi bars (4 bars, increasing height)
uint16_t barColor = wifiConnected ? COLOR_ACCENT_CYAN : COLOR_TEXT_DISABLED;

// Draw 4 signal bars (3px wide each)
tft.fillRect(x, y + 8, 3, 4, barColor);
tft.fillRect(x + 5, y + 5, 3, 7, barColor);
tft.fillRect(x + 10, y + 2, 3, 10, barColor);
tft.fillRect(x + 15, y, 3, 12, barColor);
```

---

## Common Pitfalls & Solutions

### ❌ DON'T: Use Pure Black Background

```cpp
// WRONG
display.fillRect(0, 0, SCREEN_WIDTH, SCREEN_HEIGHT, 0x0000);
```

### ✅ DO: Use Deep Dark Background

```cpp
// CORRECT
display.fillRect(0, 0, SCREEN_WIDTH, SCREEN_HEIGHT, COLOR_BACKGROUND);
```

---

### ❌ DON'T: Use Hardcoded Colors

```cpp
// WRONG - Hardcoded hex values
display.setTextColor(0x7BEF);
display.fillRect(x, y, w, h, 0x1082);
```

### ✅ DO: Use Named Color Constants

```cpp
// CORRECT - Named constants from palette
display.setTextColor(COLOR_TEXT_SECONDARY);
display.fillRoundRect(x, y, w, h, 10, COLOR_BG_LAYER2);
```

---

### ❌ DON'T: Use Banded Gradients

```cpp
// WRONG - 16-bit banding looks tacky
int bandW = w / 3;
display.fillRect(x, y, bandW, h, COLOR_BLUE_MED);
display.fillRect(x + bandW, y, bandW, h, COLOR_BLUE_CYAN);
display.fillRect(x + 2*bandW, y, w - 2*bandW, h, COLOR_CYAN_GREEN);
```

### ✅ DO: Use Solid Pastel Colors

```cpp
// CORRECT - Single solid pastel color
display.fillRoundRect(x, y, w, h, 10, COLOR_CARD_CYAN);
display.drawRoundRect(x, y, w, h, 10, COLOR_BORDER_SUBTLE);
```

---

### ❌ DON'T: Text Without Hierarchy

```cpp
// WRONG - Everything is white
display.setTextColor(ST77XX_WHITE);
display.print("Label");  // Should be secondary
display.print(value);    // Should be primary
```

### ✅ DO: Clear Text Hierarchy

```cpp
// CORRECT - Labels vs values
display.setTextColor(COLOR_TEXT_SECONDARY);
display.print("Label");

display.setTextColor(COLOR_TEXT_PRIMARY);
display.print(value);
```

---

## Checklist for New Features

Before submitting new UI code, verify:

- [ ] Uses `COLOR_BACKGROUND` instead of pure black
- [ ] All cards have shadow layer (+2 or +3 offset)
- [ ] Glass borders include both glow and border layers
- [ ] Shimmer highlights on glass elements (top-left)
- [ ] Text uses hierarchy (PRIMARY/SECONDARY/TERTIARY)
- [ ] Progress bars use gradient fills (not flat colors)
- [ ] Rounded corners: 16px (large), 12px (medium), 8px (small)
- [ ] Status colors use modern palette (SUCCESS_NEW, WARNING_NEW, ERROR_NEW)
- [ ] No hardcoded color hex values (use named constants)
- [ ] Badges hover above cards (-8px offset)
- [ ] All elements fit within safe zones (62-306 vertical)
- [ ] Footer uses `COLOR_WARNING` (warm orange)
- [ ] Header title at y=35 for vertical centering
- [ ] Gradients use blue→cyan→green spectrum appropriately

---

## Quick Reference: Color Selection

**When to use which color:**

| Need | Color Constant | Notes |
|---|---|---|
| Main container background | `COLOR_GLASS_MED` | Standard glass body |
| Deep background | `COLOR_BACKGROUND` or `COLOR_BG_DEEP` | Never pure black |
| Shadow layer | `COLOR_GLASS_DARK` | Offset +2 or +3 |
| Light overlay | `COLOR_GLASS_LIGHT` | Top portion of containers |
| Border glow | `COLOR_GLASS_BORDER_GLOW` | Outer border |
| Border line | `COLOR_GLASS_BORDER` | Inner border |
| Shimmer | `COLOR_GLASS_SHIMMER` | Top-left highlights |
| Main text | `COLOR_TEXT_PRIMARY` | White, most important |
| Label text | `COLOR_TEXT_SECONDARY` | Light gray, labels |
| Hint text | `COLOR_TEXT_TERTIARY` | Medium gray, hints |
| Inactive text | `COLOR_TEXT_DISABLED` | Dark gray, shadows |
| Success state | `COLOR_GREEN_ACCENT` | Connected, high, good |
| Warning state | `COLOR_WARNING_NEW` | Caution, medium |
| Error state | `COLOR_ERROR_NEW` | Error, low, disconnected |
| Info badge | `COLOR_CYAN` | Neutral information |
| Progress start | `COLOR_BLUE_CYAN` | Blue end of spectrum |
| Progress mid | `COLOR_CYAN_GREEN` | Middle of spectrum |
| Progress end | `COLOR_GREEN_ACCENT` | Green end of spectrum |

---

## Examples

See these files for reference implementations:

- **Menu cards**: `src/ui/menu_ui.h` (lines 452-520)
- **Settings container**: `src/settings/settings_cw.h` (lines 94-108)
- **Info cards**: `src/training/training_practice.h` (lines 180-294)
- **Progress bars**: `src/settings/settings_volume.h` (lines 96-125)
- **Header**: `src/ui/menu_ui.h` (lines 294-410)
- **Status icons**: `src/ui/status_bar.h` (lines 29-119)

---

## Version History

**v1.0 (2025-01-10)**
- Initial glassmorphic design system
- Blue-green gradient spectrum
- Glass effect simulation patterns
- Text hierarchy system
- Complete component library

---

**Questions?** Refer to existing implementations or contact the design team.

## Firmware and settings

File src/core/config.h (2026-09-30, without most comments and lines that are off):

#define CONFIG_H
#define FIRMWARE_VERSION "0.87"
#define FIRMWARE_DATE "2026-09-29"  // Update this date each time you build new firmware
#define FIRMWARE_NAME "VAIL SUMMIT"
#define WEB_FILES_VERSION "1.7.0"   // Expected web interface version for this firmware
#define SETTINGS_SCHEMA_VERSION 2
#define TFT_CS      10    // Chip Select
#define TFT_RST     11    // Hardware Reset
#define TFT_DC      12    // Data/Command
#define TFT_MOSI    35    // SPI Data Out (hardware SPI)
#define TFT_SCK     36    // SPI Clock (hardware SPI)
#define TFT_MISO    37    // SPI Data In (required for ST7796S)
#define TFT_BL      39    // Backlight control (GPIO 39)
#define SCREEN_WIDTH    480
#define SCREEN_HEIGHT   320
#define SCREEN_ROTATION 3     // 0=Portrait, 1=Landscape, 2=Portrait flipped, 3=Landscape flipped
#define SD_CS       38    // SD Card Chip Select
#define SD_MOSI     35    // SPI Data Out (shared with display)
#define SD_SCK      36    // SPI Clock (shared with display)
#define SD_MISO     37    // SPI Data In (shared with display)
#define CARDKB_ADDR 0x5F  // I2C Address
#define I2C_SDA     3     // I2C Data (STEMMA QT)
#define I2C_SCL     4     // I2C Clock (STEMMA QT)
#define KEY_UP      0xB5  // Up arrow
#define KEY_DOWN    0xB6  // Down arrow
#define KEY_LEFT    0xB4  // Left arrow
#define KEY_RIGHT   0xB7  // Right arrow
#define KEY_ENTER   0x0D  // Enter/Return
#define KEY_ENTER_ALT 0x0A // Alternate Enter
#define KEY_BACKSPACE 0x08 // Backspace (Fn+X)
#define KEY_ESC     0x1B  // ESC (Fn+Z)
#define KEY_TAB     0x09  // Tab (Fn+Space)
#define I2S_BCK_PIN     14    // I2S Bit Clock (BCLK)
#define I2S_LCK_PIN     15    // I2S Left/Right Clock (LRC/WS)
#define I2S_DATA_PIN    16    // I2S Data Output (DIN)
#define TONE_SIDETONE   700   // Hz - Morse code audio tone
#define TONE_MENU_NAV   520   // Hz - Menu navigation beep (gentle, was 800)
#define TONE_SELECT     660   // Hz - Selection confirmation (gentle, was 1200)
#define TONE_SUCCESS    1000  // Hz - Success confirmation
#define TONE_ERROR      400   // Hz - Error/invalid beep
#define TONE_STARTUP    1000  // Hz - Startup beep
#define BEEP_SHORT      30    // ms - Short beep duration
#define BEEP_MEDIUM     100   // ms - Medium beep duration
#define BEEP_LONG       200   // ms - Long beep duration
#define I2S_SAMPLE_RATE 22050 // 22.05kHz sample rate (reduced for less I2S bus noise)
#define I2S_BUFFER_SIZE 256   // Total samples (128 stereo pairs = 256 int16 values)
#define DEFAULT_VOLUME  50    // Default volume (0-100%)
#define VOLUME_MIN      0     // Minimum volume
#define VOLUME_MAX      100   // Maximum volume
#define DEFAULT_BRIGHTNESS      100   // Default brightness (0-100%)
#define BRIGHTNESS_MIN          10    // Minimum brightness (prevent completely dark)
#define BRIGHTNESS_MAX          100   // Maximum brightness
#define BRIGHTNESS_PWM_CHANNEL  0     // ESP32 LEDC channel for backlight
#define BRIGHTNESS_PWM_FREQ     5000  // PWM frequency in Hz
#define BRIGHTNESS_PWM_RESOLUTION 8   // 8-bit resolution (0-255)
#define DIT_PIN     6     // Dit paddle (tip on 3.5mm jack)
#define DAH_PIN     9     // Dah paddle (ring on 3.5mm jack)
#define PADDLE_ACTIVE   LOW   // Paddles are active LOW (pullup enabled)
#define PADDLE_DEBOUNCE_MS 10 // Debounce time in milliseconds (prevents double-dits from contact bounce)
#define TOUCH_DIT_PIN   8     // GPIO 8 (T8) - Capacitive touch dit pad
#define TOUCH_DAH_PIN   5     // GPIO 5 (T5) - Capacitive touch dah pad
#define TOUCH_THRESHOLD 40000 // Touch threshold (values rise when touched on ESP32-S3)
#define RADIO_KEY_DIT_PIN   18    // A0 - Dit output for keying ham radio
#define RADIO_KEY_DAH_PIN   17    // A1 - Dah output for keying ham radio
#define VBAT_FULL   4.2   // Fully charged voltage
#define VBAT_EMPTY  3.3   // Empty voltage (cutoff)
#define DEFAULT_WPM     20    // Words per minute
#define WPM_MIN         5     // Minimum WPM
#define WPM_MAX         40    // Maximum WPM
#define DIT_DURATION(wpm) (1200 / wpm)
#define SERIAL_BAUD 115200
#define DEBUG_ENABLED true
#define WEB_FILES_BASE_URL "https://raw.githubusercontent.com/Vail-CW/vail-summit/main/firmware_files/web/www/"
#define WEB_FILES_MANIFEST "manifest.json"
#define WEB_FILES_PATH "/www/"  // SD card path for web files
#define ST77XX_BLACK       0x0000  // Black
#define ST77XX_WHITE       0xFFFF  // White
#define ST77XX_RED         0xF800  // Red
#define ST77XX_GREEN       0x07E0  // Green
#define ST77XX_BLUE        0x001F  // Blue
#define ST77XX_CYAN        0x07FF  // Cyan
#define ST77XX_MAGENTA     0xF81F  // Magenta
#define ST77XX_YELLOW      0xFFE0  // Yellow
#define ST77XX_ORANGE      0xFC00  // Orange
#define COLOR_BG_DEEP           0x0841  // RGB(15, 20, 35) - Deep dark background
#define COLOR_BG_LAYER2         0x1082  // RGB(20, 30, 50) - Subtle raised layer
#define COLOR_CARD_BLUE         0x32AB  // RGB(50, 85, 90) - Soft muted blue
#define COLOR_CARD_TEAL         0x2B0E  // RGB(40, 95, 115) - Soft teal
#define COLOR_CARD_CYAN         0x3471  // RGB(50, 140, 140) - Muted cyan
#define COLOR_CARD_MINT         0x3D53  // RGB(60, 170, 155) - Soft mint
#define COLOR_ACCENT_BLUE       0x4D5F  // RGB(75, 170, 255) - Soft bright blue
#define COLOR_ACCENT_CYAN       0x5EB9  // RGB(90, 215, 210) - Soft cyan accent
#define COLOR_ACCENT_GREEN      0x5712  // RGB(85, 225, 150) - Soft green accent
#define COLOR_SUCCESS_PASTEL    0x4E91  // RGB(75, 210, 140) - Soft pastel green
#define COLOR_WARNING_PASTEL    0xFE27  // RGB(255, 195, 60) - Soft pastel orange
#define COLOR_ERROR_PASTEL      0xFACB  // RGB(250, 90, 90) - Soft pastel red
#define COLOR_BORDER_SUBTLE     0x39EC  // RGB(55, 65, 100) - Very subtle border
#define COLOR_BORDER_LIGHT      0x632C  // RGB(100, 100, 100) - Light neutral border
#define COLOR_BORDER_ACCENT     0x6D7F  // RGB(110, 170, 255) - Soft blue border
#define COLOR_TEXT_PRIMARY      0xFFFF  // RGB(255, 255, 255) - White (main text)
#define COLOR_TEXT_SECONDARY    0xBDF7  // RGB(190, 190, 190) - Light gray (labels)
#define COLOR_TEXT_TERTIARY     0x8410  // RGB(130, 130, 130) - Medium gray (hints)
#define COLOR_TEXT_DISABLED     0x5ACB  // RGB(90, 90, 90) - Dark gray (inactive)
#define COLOR_BACKGROUND    COLOR_BG_DEEP
#define COLOR_TITLE         COLOR_ACCENT_CYAN
#define COLOR_TEXT          COLOR_TEXT_PRIMARY
#define COLOR_HIGHLIGHT_BG  COLOR_CARD_CYAN
#define COLOR_HIGHLIGHT_FG  COLOR_TEXT_PRIMARY
#define COLOR_SUCCESS       COLOR_SUCCESS_PASTEL
#define COLOR_ERROR         COLOR_ERROR_PASTEL
#define COLOR_WARNING       COLOR_WARNING_PASTEL
#define COLOR_SEPARATOR     COLOR_BORDER_SUBTLE
#define HEADER_HEIGHT       45    // Top status bar height (reduced for better proportions)
#define FOOTER_HEIGHT       30    // Bottom instruction bar height
#define CARD_MAIN_WIDTH     450   // Main menu card width
#define CARD_MAIN_HEIGHT    80    // Main menu card height
#define CARD_STACK_WIDTH_1  405   // First stacked card width
#define CARD_STACK_WIDTH_2  375   // Second stacked card width
#define ICON_RADIUS         30    // Menu card icon circle radius
#define STATUS_ICON_SIZE    36    // Status bar icon size (battery, WiFi)
#define GROUND_Y            300   // Ground position for Morse Shooter game
#define TITLE_SAFE_RIGHT_MARGIN 95
#define MENU_ITEMS      4
#define MENU_START_Y    55
#define MENU_ITEM_HEIGHT 35
#define MENU_TEXT_SIZE  3     // Increased from 2 for better readability on larger display
template<typename T>
inline void getTextBounds_compat(T& display, const char* text, int16_t x, int16_t y,
                                  int16_t* x1, int16_t* y1, uint16_t* w, uint16_t* h) {
  *w = display.textWidth(text);
  *h = display.fontHeight();
  *x1 = x;
  *y1 = y - *h;  // LovyanGFX draws from baseline, Adafruit from top-left
}

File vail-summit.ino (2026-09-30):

/*
 * VAIL SUMMIT - Morse Code Training Device
 * Main program file (refactored for modularity)
 */

// Note: PSRAM is enabled via Arduino IDE board settings (PSRAM: "OPI PSRAM")
// No explicit PSRAM initialization code needed for Arduino ESP32 core 2.0.14

// LovyanGFX for ST7796S 4.0" display (requires Arduino ESP32 core 2.0.14)
#define LGFX_USE_V1
#include <LovyanGFX.hpp>

// LVGL Graphics Library
// Uses lv_conf.h from Arduino/libraries folder (next to lvgl folder)
#include <lvgl.h>

// Use LovyanGFX built-in fonts (in lgfx::v1::fonts namespace)
// Available: FreeSansBold9pt7b, FreeSansBold12pt7b, FreeSansBold18pt7b, etc.
using namespace lgfx::v1::fonts;

// Standard libraries
#include <SPI.h>
#include <SD.h>
#include <Wire.h>
#include <WiFi.h>
#include <esp_task_wdt.h>

// Watchdog: reboot if loop() stalls this long (genuine hang/deadlock). Generous
// enough to tolerate blocking network ops (which have ~10-15s internal timeouts)
// and the chunked web-files download (polled per loop), so only a real hang trips it.
#define LOOP_WDT_TIMEOUT_S 30

// Configuration and battery monitoring
#include "src/core/config.h"
#include "src/core/settings_migration.h"
#include "src/core/memory_monitor.h"
#include "src/core/psram_json.h"
#include <Adafruit_LC709203F.h>
#include <Adafruit_MAX1704X.h>

// Core modules
#include "src/audio/i2s_audio.h"
#include "src/core/morse_code.h"
#include "src/core/task_manager.h"

// Hardware initialization (defines LGFX class, must come before LVGL modules)
#include "src/core/hardware_init.h"

// LVGL modules (must come after hardware_init.h for LGFX type)
#include "src/lvgl/lv_init.h"
#include "src/lvgl/lv_screen_manager.h"
#include "src/lvgl/lv_theme_summit.h"
#include "src/lvgl/lv_widgets_summit.h"
#include "src/lvgl/lv_menu_screens.h"

// LVGL is the only UI system - no legacy rendering

// Boot splash screen (LVGL version)
#include "src/lvgl/lv_splash_screen.h"

// Status bar
#include "src/ui/status_bar.h"

// Menu system
#include "src/ui/menu_ui.h"

// Training modes
#include "src/training/training_practice.h"
#include "src/training/training_license_ui.h"
#include "src/training/training_license_input.h"

// Games
#include "src/games/game_morse_shooter.h"
#include "src/games/game_memory_chain.h"
#include "src/games/game_story_time.h"
#include "src/games/game_cw_speeder.h"

// Settings modes
#include "src/settings/settings_wifi.h"
#include "src/settings/settings_cw.h"
#include "src/settings/settings_volume.h"
#include "src/settings/settings_brightness.h"
#include "src/settings/settings_general.h"
#include "src/settings/settings_web_password.h"

// Connectivity
#include "src/network/vail_repeater.h"
#include "src/network/morse_mailbox.h"
#include "src/network/cwschool_link.h"

// Practice time tracking (for CW School sync)
#include "src/settings/settings_practice_time.h"

// Progress sync (CW School cloud sync)
#include "src/network/progress_sync.h"

// Vail Course training mode
#include "src/training/training_vail_course_core.h"

// Radio modes (CW memories must be included before radio_output)
#include "src/radio/radio_cw_memories.h"
#include "src/radio/radio_output.h"

// NTP Time
#include "src/network/ntp_time.h"

// QSO Logger (order matters - validation and API must come first)
#include "src/qso/qso_logger_validation.h"
#include "src/network/pota_api.h"
#include "src/qso/qso_logger.h"
#include "src/qso/qso_logger_storage.h"
#include "src/qso/qso_logger_input.h"
#include "src/qso/qso_logger_ui.h"
#include "src/qso/qso_logger_view.h"
#include "src/qso/qso_logger_statistics.h"
#include "src/qso/qso_logger_settings.h"

// POTA Recorder (must come after QSO Logger for storage access)
#include "src/pota/pota_recorder.h"

// Web Server (must come after QSO Logger to access storage)
#include "src/web/server/web_server.h"

// Web Practice Mode
#include "src/web/modes/web_practice_mode.h"

// Web Memory Chain Mode
#include "src/web/modes/web_memory_chain_mode.h"

// Web Hear It Type It Mode
#include "src/web/modes/web_hear_it_mode.h"

// SD Card Storage
#include "src/storage/sd_card.h"

// SD-card settings backup/restore (must come after sd_card.h)
#include "src/settings/settings_sd_backup.h"

// Web File Downloader (needed early for boot-time download check)
#include "src/web/server/web_file_downloader.h"

// Web First Boot (must come after sd_card.h)
#include "src/web/server/web_first_boot.h"

// LVGL Web Download Screen (must come after web_first_boot.h)
#include "src/lvgl/lv_web_download_screen.h"

// Bluetooth modes
#include "src/bluetooth/ble_hid.h"
#include "src/bluetooth/ble_midi.h"

// Bluetooth keyboard host (external keyboard input)
#include "src/settings/settings_bt_keyboard.h"

// Menu navigation (must come after all mode headers that define input handlers)
#include "src/ui/menu_navigation.h"

// Additional LVGL screen modules (must come after settings modules for type access)
#include "src/lvgl/lv_settings_screens.h"
#include "src/lvgl/lv_training_screens.h"
#include "src/lvgl/lv_game_screens.h"
#include "src/lvgl/lv_mode_screens.h"
#include "src/lvgl/lv_pota_recorder.h"
#include "src/lvgl/lv_home_screen.h"
#include "src/lvgl/lv_school_screens.h"
#include "src/lvgl/lv_quick_settings.h"
#include "src/lvgl/lv_mode_integration.h"

// ============================================
// cwKeyType accessor functions for LVGL (needed because cwKeyType is KeyType enum)
// ============================================
int getCwKeyTypeAsInt() { return (int)cwKeyType; }
void setCwKeyTypeFromInt(int keyType) { cwKeyType = (KeyType)keyType; }

// ============================================
// Audio priority gate
// ============================================
// Audio wins over everything else, WiFi included. While audio priority is
// active, background work that can stall the Core-1 loop (blocking HTTPS,
// flash commits, SD writes, BLE scans) is held off, and WiFi modem sleep is
// turned off so the radio isn't cycling sleep/wake bursts under the tone.
// The hold keeps the gate closed through gaps between elements/characters
// so a multi-second TLS handshake can't start in a gap and land mid-tone.
#define AUDIO_PRIORITY_HOLD_MS 3000

static unsigned long lastAudioActiveMs = 0;
static bool audioPriorityWasActive = false;
static bool audioPriorityWifiWasUp = false;

bool audioPriorityActive() {
  if (isModeAudioCritical((int)currentMode)) return true;
  if (isTonePlaying() || isMorsePlaybackActive()) {
    lastAudioActiveMs = millis();
    return true;
  }
  return lastAudioActiveMs != 0 && (millis() - lastAudioActiveMs) < AUDIO_PRIORITY_HOLD_MS;
}

// Called once per loop: apply WiFi power-save changes on gate edges only
// (and when WiFi comes up, since a fresh connection starts in modem sleep)
void updateAudioPriority() {
  bool active = audioPriorityActive();
  bool wifiUp = (WiFi.status() == WL_CONNECTED);
  if (active == audioPriorityWasActive && wifiUp == audioPriorityWifiWasUp) return;
  audioPriorityWasActive = active;
  audioPriorityWifiWasUp = wifiUp;
  if (wifiUp) {
    WiFi.setSleep(active ? WIFI_PS_NONE : WIFI_PS_MIN_MODEM);
  }
}

// Deferred NVS saves (src/core/deferred_save.h) may only commit when no audio
// is active: a flash commit disables both cores' caches, and even in an
// inter-element gap it would delay the start of the next element.
bool deferredSavesAllowed() {
  return !audioPriorityActive();
}

// ============================================
// Global Hardware Objects
// ============================================

// Battery monitor (one of these will be present)
Adafruit_LC709203F lc;
Adafruit_MAX17048 maxlipo;
bool hasLC709203 = false;
bool hasMAX17048 = false;
bool hasBatteryMonitor = false;

// Create display object (LovyanGFX configured in hardware_init.h)
LGFX tft;

// ============================================
// Menu System State
// ============================================

MenuMode currentMode = MODE_MAIN_MENU;
int currentSelection = 0;
bool menuActive = true;

// Getter/setter for currentMode to allow LVGL integration without circular includes
int getCurrentModeAsInt() { return (int)currentMode; }
void setCurrentModeFromInt(int mode) { currentMode = (MenuMode)mode; }

// ============================================
// Early Boot Download Screen (direct TFT, no LVGL)
// ============================================
// Used during web file downloads that happen before LVGL init.
// Draws directly to the display using LovyanGFX.

#define DL_BAR_X      60
#define DL_BAR_Y      160
#define DL_BAR_W      360
#define DL_BAR_H      22
#define DL_STATUS_Y   210
#define DL_FILE_Y     245

void drawEarlyBootDownloadScreen() {
  tft.fillScreen(COLOR_BACKGROUND);

  // Title
  tft.setFont(&FreeSansBold18pt7b);
  tft.setTextColor(COLOR_TITLE);
  tft.setTextDatum(lgfx::top_center);
  tft.drawString("VAIL SUMMIT", SCREEN_WIDTH / 2, 30);

  // Subtitle
  tft.setFont(&FreeSansBold12pt7b);
  tft.setTextColor(COLOR_TEXT_PRIMARY);
  tft.drawString("Downloading Web Files", SCREEN_WIDTH / 2, 90);

  // "Please wait" note
  tft.setFont(&FreeSansBold9pt7b);
  tft.setTextColor(0x8C71);  // dim gray
  tft.drawString("Device will reboot when complete", SCREEN_WIDTH / 2, 125);

  // Progress bar outline
  tft.drawRect(DL_BAR_X, DL_BAR_Y, DL_BAR_W, DL_BAR_H, COLOR_TEXT_PRIMARY);

  // Initial status
  tft.setFont(nullptr);
  tft.setTextSize(2);
  tft.setTextColor(COLOR_ACCENT_CYAN);
  tft.setTextDatum(lgfx::top_center);
  tft.drawString("Initializing...", SCREEN_WIDTH / 2, DL_STATUS_Y);
  tft.setTextSize(1);
}

void earlyBootProgressCallback(const char* status, int currentFile, int totalFiles) {
  // Update progress bar fill
  if (totalFiles > 0) {
    int fillW = ((DL_BAR_W - 4) * currentFile) / totalFiles;
    tft.fillRect(DL_BAR_X + 2, DL_BAR_Y + 2, fillW, DL_BAR_H - 4, COLOR_ACCENT_CYAN);
  }

  // Clear text areas
  tft.fillRect(0, DL_STATUS_Y, SCREEN_WIDTH, 80, COLOR_BACKGROUND);

  // File counter
  tft.setFont(nullptr);
  tft.setTextSize(2);
  tft.setTextDatum(lgfx::top_center);

  if (totalFiles > 0) {
    char countBuf[32];
    snprintf(countBuf, sizeof(countBuf), "File %d / %d", currentFile, totalFiles);
    tft.setTextColor(COLOR_TEXT_PRIMARY);
    tft.drawString(countBuf, SCREEN_WIDTH / 2, DL_STATUS_Y);
  }

  // Status / filename
  tft.setTextColor(COLOR_ACCENT_CYAN);
  tft.drawString(status, SCREEN_WIDTH / 2, DL_FILE_Y);
  tft.setTextSize(1);
}

// ============================================
// Setup - Hardware Initialization
// ============================================

void setup() {
  Serial.begin(SERIAL_BAUD);
  // Never block on USB serial. Once a host enumerates the port, HWCDC defaults
  // to a 100ms TX timeout, so with nothing reading it every print into a full
  // buffer stalls the loop (and the keyer) for up to 100ms. Drop logs instead.
  Serial.setTxTimeoutMs(0);
  delay(500); // Brief wait for serial monitor
  Serial.println("\n\n=== VAIL SUMMIT STARTING ===");
  Serial.printf("Firmware: %s (Build: %s)\n", FIRMWARE_VERSION, FIRMWARE_DATE);

  // Log why the device last reset - useful for field diagnostics (a watchdog,
  // panic, or brownout reset points at a different problem than a clean power-on).
  switch (esp_reset_reason()) {
    case ESP_RST_POWERON:  Serial.println("Reset reason: power-on"); break;
    case ESP_RST_SW:       Serial.println("Reset reason: software restart"); break;
    case ESP_RST_PANIC:    Serial.println("Reset reason: PANIC/exception (crash)"); break;
    case ESP_RST_TASK_WDT: Serial.println("Reset reason: TASK WATCHDOG (loop hang)"); break;
    case ESP_RST_INT_WDT:  Serial.println("Reset reason: interrupt watchdog"); break;
    case ESP_RST_WDT:      Serial.println("Reset reason: other watchdog"); break;
    case ESP_RST_BROWNOUT: Serial.println("Reset reason: BROWNOUT (low voltage)"); break;
    case ESP_RST_DEEPSLEEP: Serial.println("Reset reason: deep sleep wake"); break;
    default:               Serial.println("Reset reason: other"); break;
  }
  Serial.println("Starting setup...");

  // ============================================
  // PSRAM Diagnostic - Run First
  // ============================================
  Serial.println("\n--- PSRAM Diagnostic ---");
  Serial.printf("ESP32 Chip Model: %s\n", ESP.getChipModel());
  Serial.printf("Chip Revision: %d\n", ESP.getChipRevision());
  Serial.printf("CPU Frequency: %d MHz\n", ESP.getCpuFreqMHz());
  Serial.printf("Flash Size: %d bytes\n", ESP.getFlashChipSize());

  Serial.println("\nChecking PSRAM (before manual init)...");
  Serial.printf("psramFound(): %s\n", psramFound() ? "true" : "false");
  Serial.printf("ESP.getPsramSize(): %d bytes\n", ESP.getPsramSize());

  // PSRAM is auto-initialized when "OPI PSRAM" is selected in Arduino IDE
  // Manual initialization (esp_psram_init) is not available in Arduino ESP32 core 2.0.14
  if (psramFound() && ESP.getPsramSize() == 0) {
    Serial.println("\nWARNING: PSRAM detected but reports 0 bytes size.");
    Serial.println("This may indicate a board configuration issue.");
  }

  Serial.println("\nRechecking PSRAM (after manual init)...");
  Serial.printf("psramFound(): %s\n", psramFound() ? "true" : "false");
  Serial.printf("ESP.getPsramSize(): %d bytes\n", ESP.getPsramSize());
  Serial.printf("ESP.getFreePsram(): %d bytes\n", ESP.getFreePsram());
  Serial.printf("ESP.getMinFreePsram(): %d bytes\n", ESP.getMinFreePsram());

  // Try a test allocation
  if (psramFound()) {
    Serial.println("\nPSRAM found! Testing allocation...");
    void* testPtr = ps_malloc(1024);
    if (testPtr) {
      Serial.println("PSRAM test allocation: SUCCESS");
      free(testPtr);
    } else {
      Serial.println("PSRAM test allocation: FAILED");
    }
  } else {
    Serial.println("\nWARNING: PSRAM NOT DETECTED!");
    Serial.println("Possible causes:");
    Serial.println("  1. PSRAM not enabled in Arduino IDE (Tools > PSRAM)");
    Serial.println("  2. Wrong board selected (should be ESP32-S3 variant)");
    Serial.println("  3. Hardware doesn't have PSRAM");
    Serial.println("  4. ESP32 Arduino core version issue");
  }
  Serial.println("--- End PSRAM Diagnostic ---\n");

  // NOTE: settings schema migration now runs AFTER initDisplay() below, so the
  // SD card (which shares SPI with the display and must init second) can take
  // a pre-migration backup. Constraint: only the "display" and "wifi"
  // namespaces are read before migrations run - migrations must never alter
  // the meaning of existing keys in those two namespaces.

  // Recovery gesture: hold BOTH paddles at power-on for 3s to factory-reset.
  // Display-independent so a misconfigured device can be recovered even if the
  // normal UI won't load. No-op unless both paddles are held at this moment.
  checkFactoryResetGesture(DIT_PIN, DAH_PIN, PADDLE_ACTIVE);

  // ============================================
  // Early Boot Web Download Check
  // ============================================
  // Check if a web files download was requested (via reboot)
  // This MUST happen before LVGL initialization when RAM is plentiful
  Serial.println("Checking for pending web download...");
  bool downloadPending = isWebDownloadPending();
  Serial.printf("Download pending flag: %s\n", downloadPending ? "TRUE" : "FALSE");
  if (downloadPending) {
    Serial.println("\n========================================");
    Serial.println("WEB DOWNLOAD PENDING - EARLY BOOT MODE");
    Serial.println("========================================");
    Serial.printf("Free heap: %d bytes, max block: %d bytes\n",
      ESP.getFreeHeap(), ESP.getMaxAllocHeap());

    // Initialize display + backlight early so user sees progress
    setupBrightnessPWM();
    loadBrightnessSettings();
    applyBrightness(brightnessValue);
    initDisplay();
    drawEarlyBootDownloadScreen();

    // Saved WiFi credentials live in "wifi" prefs as ssid1/pass1 .. ssid3/pass3.
    // The downloader tries all of them, starting with the one that was connected
    // when the download was requested.
    if (hasSavedWiFiForEarlyBoot()) {
      // Perform the download with progress callback for display updates
      bool success = performEarlyBootWebDownload(earlyBootProgressCallback);

      // Clear the pending flag
      clearWebDownloadPending();

      // Show result on screen before rebooting
      tft.fillRect(0, DL_STATUS_Y, SCREEN_WIDTH, 80, COLOR_BACKGROUND);
      tft.setFont(nullptr);
      tft.setTextSize(2);
      tft.setTextDatum(lgfx::top_center);
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
void loop() {

  // Feed the loop watchdog. If we never get back here within LOOP_WDT_TIMEOUT_S
  // (a hang/deadlock somewhere below), the WDT reboots the device.
  esp_task_wdt_reset();

  // Process LVGL timer tasks (handles ALL UI, input, animations, redraws)
  // LVGL reads CardKB directly via its input driver
  lv_timer_handler();

  // Display workload profiling (compiled out when DISPLAY_PERF_INSTRUMENT is 0)
  reportDisplayPerf((int)currentMode);

  // Process any pending deferred screen operations
  // (screen creation is deferred from event callbacks to avoid stack overflow)
  processQSOViewLogsPending();

  // Poll non-blocking WiFi connection state machine
  // This must be called every loop to check connection progress
  if (updateWiFiConnection()) {
    // State changed - if we're in WiFi settings, update the UI
    if (currentMode == MODE_WIFI_SETTINGS) {
      updateWiFiScreen();
    }
  }

  // Keep the clock synced once WiFi is up (non-blocking), so QSO timestamps are
  // correct even if WiFi connected after boot.
  ensureNTPStarted();

  // Update practice time activity accumulator (for inactivity detection)
  // This must run every loop to accurately track active practice time
  updateActivityAccumulator();

  // Check for pending web server restart (after file upload)
  if (isWebServerRestartPending()) {
    restartWebServer();
  }

  // Check for deferred web mode starts (safe to call LVGL from main loop)
  extern volatile bool webPracticeStartPending;
  extern volatile bool webHearItStartPending;
  extern volatile bool webMemoryChainStartPending;
  extern volatile bool webModeDisconnectPending;

  if (webPracticeStartPending) {
      webPracticeStartPending = false;
      onLVGLMenuSelect(MODE_WEB_PRACTICE);
  }
  if (webHearItStartPending) {
      webHearItStartPending = false;
      onLVGLMenuSelect(MODE_WEB_HEAR_IT);
  }
  if (webMemoryChainStartPending) {
      webMemoryChainStartPending = false;
      onLVGLMenuSelect(MODE_WEB_MEMORY_CHAIN);
  }
  if (webModeDisconnectPending) {
      webModeDisconnectPending = false;
      // Only trigger back-nav if we're actually in a web mode
      if (currentMode == MODE_WEB_PRACTICE || currentMode == MODE_WEB_HEAR_IT || currentMode == MODE_WEB_MEMORY_CHAIN) {
          onLVGLBackNavigation();
      }
  }

  // Note: Automatic web files version check disabled due to SSL RAM constraints
  // Users can manually download via Settings > WiFi > Web Files
  // The version check requires SSL which needs ~40KB internal RAM not available when LVGL runs
  // performWebFilesCheck();  // Disabled - SSL fails with low RAM
  // if (isWebFilesPromptPending() && !isWebDownloadScreenActive() && currentMode == MODE_MAIN_MENU) {
  //   showWebFilesUpdateNotification();
  //   clearWebFilesPromptPending();
  // }

  // Handle web download screen input and progress updates
  if (isWebDownloadScreenActive()) {
    updateWebDownloadProgressUI();

    // ONLY poll keyboard during download progress (no buttons on that screen)
    // Other screens (prompting, complete, error) handle input via LVGL events
    if (getWebDownloadUIState() == WD_UI_DOWNLOADING) {
      char key = readKeyboardNonBlocking();
      if (key != 0) {
        handleWebDownloadInput(key);
      }
    }
  }

  // Periodic memory health check (runs every 30 seconds internally)
  checkMemoryHealth();

  // Audio priority: evaluated once here, gates the background work below
  updateAudioPriority();
  bool audioBusy = audioPriorityWasActive;

  // Update status data periodically (skip during audio-critical/busy modes)
  static unsigned long lastStatusUpdate = 0;
  // (internet check is a blocking HTTP request - held off while audio has priority)
  if (!isModeNoStatus((int)currentMode) && !audioBusy && millis() - lastStatusUpdate > 5000) {
    updateStatus();
    // Refresh header status icons on the active screen (menu headers set
    // these at creation time and would otherwise show stale state)
    updateWiFiStatusIcon();
    updateMailboxStatusIcon();
    lastStatusUpdate = millis();
  }

  // Dispatch mode-specific polling via registry table
  dispatchModeCallback(pollTable, pollTableSize, (int)currentMode);

  // Update Morse Mailbox polling (background; blocking HTTPS, so never while audio has priority)
  if (!audioBusy) {
    updateMailboxPolling();
  }

  // Commit deferred NVS saves once values settle and audio is idle
  updateDeferredSaves();

  // Mirror changed settings to the SD backup (debounced; skipped while audio
  // has priority so an SD write never crunches active audio)
  if (!audioBusy) {
    updateSettingsBackup();
  }

  // Update BLE Keyboard host (for auto-reconnect, skip during BT modes).
  // Also paused while the satellite data download streams: BLE scanning and
  // sustained WiFi TLS share the 2.4GHz radio and RAM, and running both is
  // an intermittent-crash recipe (seen mid-download with scans in the log).
  // Also held off while audio has priority: BLE scans contend with WiFi for the radio.
  if (currentMode != MODE_BT_HID && currentMode != MODE_BT_MIDI && !satUpdateJobActive() && !audioBusy) {
    updateBLEKeyboardHost();
  }

  // Minimal delay - faster for audio-critical modes
  delay(isModeAudioCritical((int)currentMode) ? 1 : 10);
}

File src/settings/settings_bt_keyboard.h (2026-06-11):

/*
 * Bluetooth Keyboard Settings Module
 * Handles BLE keyboard scanning, pairing, and connection management
 */

#ifndef SETTINGS_BT_KEYBOARD_H
#define SETTINGS_BT_KEYBOARD_H

#include "../core/config.h"
#include "../bluetooth/ble_keyboard_host.h"

// Bluetooth keyboard settings state machine
enum BTKeyboardSettingsState {
  BTKB_UI_STATUS,         // Show current status and paired device
  BTKB_UI_SCANNING,       // Actively scanning for keyboards
  BTKB_UI_DEVICE_LIST,    // Show list of found devices
  BTKB_UI_CONNECTING,     // Connecting to selected device
  BTKB_UI_FORGET_CONFIRM  // Confirm forget pairing
};

// UI state
BTKeyboardSettingsState btkbUIState = BTKB_UI_STATUS;
int btkbSelectedDevice = 0;
unsigned long btkbLastUIUpdate = 0;
bool btkbForgetConfirm = false;

// LVGL mode flag - when true, skip legacy draw functions (LVGL handles display)
bool btKeyboardUseLVGL = true;  // Default to LVGL mode

// Forward declarations
void startBTKeyboardSettings(LGFX &display);
void drawBTKeyboardSettingsUI(LGFX &display);
int handleBTKeyboardSettingsInput(char key, LGFX &display);
void drawBTKBStatusScreen(LGFX &display);
void drawBTKBScanningScreen(LGFX &display);
void drawBTKBDeviceList(LGFX &display);
void drawBTKBConnectingScreen(LGFX &display);
void drawBTKBForgetConfirm(LGFX &display);
void updateBTKeyboardSettingsUI(LGFX &display);

// Helper: truncate a string into a char buffer with ellipsis
static void truncateStr(char* dest, size_t destSize, const char* src, int maxChars) {
  size_t srcLen = strlen(src);
  if ((int)srcLen > maxChars && maxChars > 3) {
    strncpy(dest, src, maxChars - 3);
    dest[maxChars - 3] = '\0';
    strncat(dest, "...", destSize - strlen(dest) - 1);
  } else {
    strncpy(dest, src, destSize - 1);
    dest[destSize - 1] = '\0';
  }
}
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

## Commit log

2026-06-03 v0.7 — Major Overhaul
    Major UI/UX overhaul to a single, focused learning path plus reliability hardening.
    - Learn CW: one Koch-method curriculum (Vail CW course) replacing the scattered
    training modes, with daily / copy / send practice and unified mastery tracking.
    - Home dashboard as the boot screen — training progress, band conditions, quick actions.
    - Global quick-settings overlay (volume / brightness / CW speed / sidetone).
    - Reliability: NVS settings schema versioning + migration, user factory reset
    (menu + hold-both-paddles recovery), loop watchdog with reset-reason logging,
    and a secure-by-default web interface.
    - QSO logger timestamps from NTP, left blank when offline inst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
    [battery bottom.3mf, expansion hatch.3mf, keyboard top trim.3mf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]
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2026-06-03 fix: quick-settings overlay layout and key handling
    The V quick-settings panel clipped its rows off both edges and ignored ESC and
    up/down. Rebuild the layout with normal flex containers (the old
    remove-style-all rows misbehaved), and route keys straight to the overlay from
    handleGlobalHotkey while it is open instead of relying on LVGL keypad-group and
    editing-mode behavior, which swallowed ESC and the arrows on a slider. Up/Down
    now select a row, Left/Right adjust it live, ESC or Enter closes.
2026-06-10 v0.71: tester feedback fixes
    - Delete QSO confirmation now keyboard-operable (buttons join input group)
    - License Study pool downloads repointed at pinned upstream commit
    (branch/file renames had 404'd all three URLs); partial downloads
    are removed instead of left as broken JSON on the SD card
    - QSO Logger Settings layout fits the screen (QTH ran off the bottom)
    - POTA Recorder inputs no longer clipped
    - QSO Statistics numbers sized below the screen title
    - Menu footers say 'V Quick Settings' instead of 'V Volume'
    [config.h]
2026-06-11 v0.72: UI/UX overhaul - stability, focus memory, faster display pipeline
    Stability:
    - Add cleanup table entries for CW Academy, License study, QSO logger,
    CW Memories, Radio Output, Vail repeater, and mailbox link screens
    (zombie timers / stale static widget pointers on back-nav)
    - Replace blocking delay(250) in Vail room switch with deferred reconnect
    - Remove delay(100) from Band Conditions startup
    - Guard all LVGL timer callbacks with widget validity checks
    - Convert raw strcpy/strcat to strlcpy/strlcat (POTA filters, CWA, license)
    - Fix event handler registration order in QSO entry form
    - Fix POTA stuck-refresh flag that disabled retry after a failed fetch
    UX:
    - Focus memory: backin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
    [ble_hid.h, ble_keyboard_host.h, ble_midi.h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]
2026-06-12 v0.73: settings reliability overhaul, repeater dashboard UI, keying protocol fixes
    - NVS schema v2: consolidate per-key training stats into blobs (partition was
    filling up, making every settings write silently fail)
    - New deferred-save system: NVS commits wait for idle audio, no more crunch
    - SD-card settings backup with auto-restore when NVS comes up wiped
    - Vail Repeater: dashboard-style UI, TX strip with ON AIR pill, break-in
    state tile, pinned Decoder room, decoded strip shows own + received text
    - Vail protocol: key-down timestamps, exact-match echo filter, clock-sync
    fix (chat history no longer poisons skew), sends deferred out of tone window
    - Crash fix: room-list join read acti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
    [config.h, i2s_audio.h, settings_brightness.h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]
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2026-06-25 fix: defer callsign-settings back-nav and harden against re-entry
    User report: factory reset, then setting callsign in Settings reboots/crashes,
    reproducible every time. No serial trace was captured, so this is a defensive
    fix against the most likely causes for that path:
    - The textarea ENTER handler called onLVGLBackNavigation() synchronously,
    tearing the current screen down (clearNavigationGroup + new screen +
    lv_scr_load_anim) while LVGL was still walking sibling event callbacks
    on objects belonging to it. Defer the back-nav with lv_async_call so it
    runs after the current event dispatch unwinds.
    - A repeating/double ENTER could fire save+nav twice before the screen
    swap complet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
2026-06-26 fix: web password saves on ENTER, add requirements guide, fix teal contrast
    User report: "I hit enter to save the password. That doesn't work, I have to
    hit escape. That is a weird flow." Plus: wanted a guide of what's allowed, and
    teal buttons with light text are hard to read on this and other screens.
    - ENTER now saves the web password (matches every other settings screen).
    ESC cancels/exits without wiping an existing password. Shared validate-and-
    save helper shows a specific reason on rejection ("Too short - need 8-16
    (have N)") instead of silently disabling protection and reporting "Saved".
    - Added an always-visible requirements hint under the field:
    "8-16 chars. Letters, numbe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
2026-06-26 v0.74: onboarding wizard, callsign & web-password fixes, contrast
    Bug-fix/feature release rolling up work since v0.73:
    - First-run onboarding wizard with device tour
    - Fix callsign-settings crash on save
    - Web password saves on ENTER (was ESC-only) with a requirements guide
    - Practice decode text wrapping fix
    - Readability: dark text on teal focused buttons
    [config.h]
2026-06-26 fix: web password disable now persists; ESC is a true cancel
    Follow-up to the web-password flow change. Two issues found in review:
    - Turning protection OFF never took effect. Toggling to disabled only updated
    the UI; webPassword/webAuthEnabled kept their old values because ESC was a
    pure exit and nothing persisted the disable. Now the enabled->disabled
    toggle clears the password and auth flag and persists immediately.
    - ESC was labelled "Cancel" but still silently saved a valid typed password.
    ESC is now a true cancel (discards the unsaved password edit); ENTER remains
    the save key. A toggled-off state is already persisted, so it survives cancel.
    Builds clean (79% flash, 34% RAM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
2026-06-26 fix: callsign/web-password save no longer crashes (swallow ENTER release)
    Real root cause of the callsign-save reboot, confirmed from a device trace:
    saving with ENTER navigates back to the parent menu, then the ENTER key's
    RELEASE synthesizes a phantom CLICKED on the now-focused "Callsign" menu row
    (mode 29). That re-enters the screen mid-teardown -> LoadProhibited
    (EXCVADDR 0x20, re-entrant "Menu selected mode: 29" right before the panic).
    Fix: on ENTER-save, swallow the rest of the press with
    lv_indev_wait_release(getLVGLKeypad()) so the release can't generate a click
    on the parent screen. This is the same guard the onboarding callsign field,
    quick settings, and the alert dialog already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
2026-06-26 fix: practice decode wraps long unbroken character streams
    A continuous run of decoded characters with no spaces (e.g. a nonstop
    string of E's) overflowed the decoder box instead of wrapping. Root cause:
    LV_TXT_LINE_BREAK_LONG_LEN is 0 in lv_conf.h, so LVGL's label wrap never
    breaks a "long word" that has no space to break on.
    Rather than change that global config (and the local/CI lv_conf.h sync it
    entails), pre-wrap the decoded text in updatePracticeDecoderDisplay():
    measure glyph widths against the label width and insert newlines before any
    glyph that would overrun the line. Lines now fill edge-to-edge and any
    stream wraps cleanly. The existing 4-line overflow-clear is preserved.
    Builds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
2026-07-06 fix: external Bluetooth keyboard now actually works
    - Route BLE keyboard buffer into both input paths (LVGL keypad driver and
    readKeyboardNonBlocking) - keys were buffered but never consumed
    - Enable Just Works bonding/encryption; HID keyboards refuse to send input
    reports on an unencrypted link
    - Persist and use the BLE address type; reconnecting to a random-static
    address as public never succeeds, which killed reconnect after reboot
    - Auto-reconnect now scans for the paired keyboard in the background and
    connects only when it is seen, instead of a blind blocking connect that
    froze the UI for 10s of every 30s while the keyboard was off; retries
    from the ERROR state instead of de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
    [ble_keyboard_host.h, vail-summit.ino]
2026-07-06 fix: BT keyboard screen freeze, scan feedback, first-pairing dead keys
    - Use the non-blocking NimBLEScan::start overload; the (duration, bool)
    overload blocks the calling task for the entire 10s scan, freezing the
    UI on every scan including background reconnect scans
    - Live scan feedback: status shows animated 'Scanning... (N found)' and
    discovered keyboards appear in the device list as they are found
    - Verify link encryption after pairing and automatically redo the
    connection once if unencrypted - on a first-time pairing the report
    subscription could land before encryption, leaving a 'connected'
    keyboard that never sent a single report until manually reconnected
    - Rescan ~2s aft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
    [ble_keyboard_host.h]
2026-07-06 feat: two-panel arrow navigation + pairing reliability on BT keyboard screen
    - Add panel_nav_handler/NavPanelContext to lv_screen_manager.h for screens
    with two side-by-side lists of different lengths: UP/DOWN moves within a
    column, LEFT/RIGHT jumps to the matching row of the other column
    - BT keyboard screen uses it: RIGHT from the action buttons enters the
    device list, LEFT returns; document the new handler in CLAUDE.md
    - Delete stale bond before a fresh user-initiated pairing and clear
    half-formed bonds on the encryption retry - a bond the keyboard has
    forgotten (it's back in pairing mode) makes encryption fail until both
    devices are power-cycled
    - Passkey support (DISPLAY_ONL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
    [ble_keyboard_host.h]
2026-07-06 fix: BT keyboard finally sends input - confirmed CCCD writes + full HOGP host behavior
    Root cause of 'connected but keyboard never sends a report': NimBLE's
    subscribe() defaults to enabling notifications with an unacknowledged
    write command. The keyboard's stack ignored it (and subscribe() reports
    success either way since there is no response to check), so it never
    finished its host-setup sequence - staying in pairing mode and sending
    nothing. Subscribing with response=true fixed it on the spot; the
    keyboard immediately sent its conn param request and began reporting.
    Supporting fixes found on the way:
    - Full HOGP enumeration like a real OS host: read PnP ID, HID info,
    Report Map and Repo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
    [ble_keyboard_host.h]
2026-07-11 fix: Morse Shooter end-to-end overhaul - smooth physics, per-char shooting, word overlap
    Gameplay fixes:
    - Physics now dt-based (50ms ticks, px/sec speeds) instead of 1s jumps with
    px-per-second-scale speeds that took minutes to cross the screen
    - Characters shoot as soon as they decode (character-gap latency) instead of
    only the last char after a full word gap - Word/Callsign modes now register
    every keystroke in a sequence
    - Word/Callsign spawn is width-aware: words stay on screen, no horizontal
    overlap, no stacking on the same line (fixes overlapping-callsign display)
    - Words render plain text with green typed-prefix recolor instead of
    dot-separated letters that tripled label wi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
    [game_morse_shooter.h]
2026-07-11 perf: fix UI-wide input lag - non-blocking beeps, 10ms input poll, instant transitions
    Every menu keypress was paying for three stacked delays:
    - beep() blocked the LVGL thread for duration+10ms after the tone was
    already queued in I2S DMA. Nav beeps froze the UI ~50ms, select beeps
    ~200ms, all before the screen could redraw. The DMA drains the tone by
    itself (playTone already appends a silence tail), so the trailing
    delay is gone. Back-to-back beeps still play in order since i2s_write
    self-paces when the queue is full.
    - LVGL polled the CardKB every 30ms. Now 10ms, so keypresses reach
    widgets with up to 20ms less latency. Synced in both lv_conf.h and
    the local build env copy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
    [i2s_audio.h]
2026-07-11 feat: get-ready countdown when entering school practice modes
    Daily, Copy, and Send practice used to fire their first target the same
    instant the screen appeared, so selecting them from the Learn CW hub
    dumped you straight into a lesson with no time to react.
    All three now open with a 3-2-1 countdown (~2s) in the big character
    slot before the first target plays or shows. SPACE skips it. Countdown
    keying in Send practice is discarded since the decoder buffer clears
    when the first real target is set.
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2026-07-11 feat: sort by next pass, Sky Window planner, settings contrast fix
    - P toggles the satellite list between name sort and next-pass sort;
    in pass-sort mode the background worker sweeps the entire catalog
    (favorites first) and the list reorders as results land, keeping the
    cursor on the same satellite; header shows compute progress
    - New Sky Window screen (T from the list): pick a date and start time
    (L/R adjusts, +-1 day / +-15 min, clamped to now..+7 days) and see
    every satellite with a pass touching the following 60 minutes,
    sorted by AOS - ENTER opens the full pass detail
    - Fix satellite setup rows: value text was accent-on-accent when a row
    was focused (unreadable while typin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
    [modes.h]
2026-07-11 fix: pass prediction returned zero passes; feat: Satellites hub menu
    Prediction bug: nextpass() reports failure whenever its elevation-search
    loop exhausts the iteration count - including when the final orbit it
    checked qualifies. Calling it with iterations=1 for chunking therefore
    failed 100% of the time: every satellite showed 'no passes in 48h'.
    Now called with 2 iterations, rewinding one orbit on failure so the
    possibly-qualifying final hop is re-checked next call. Net progress
    stays one orbit per call, keeping the search chunkable.
    UX: entering Satellites now lands on a hub menu instead of the full
    catalog with hotkey soup:
    My Sats / Popular Birds / Next 60 Minutes / Plan Date & Time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
    [modes.h]
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2026-07-12 feat: captive portal detection with wifi login help screen
    hotel and coffee shop wifi with browser login pages used to just silently fail. now after connecting we probe a known 204 endpoint and if the portal hijacks the response we show a login required screen with the device MAC so you can register it on the network add-a-device page. also shows the portal login host when we catch the redirect.
    background internet checks flag suspected portals too, and the apple endpoint check no longer counts a hijacked login page as real internet. current connection view shows a press I for info hint when a portal is suspected.
    [captive_portal.h, internet_check.h]
2026-07-12 tweak: drop portal probe timeout to 3s per endpoint
    worst case ui stall when both check endpoints are dead goes from 8s to 6s. the 204 endpoints and portal redirects both answer fast so 3s is still plenty
    [captive_portal.h]
2026-07-12 feat: full transmitter database from SatNOGS - offline frequencies for every bird
    One-stop shop: Update TLEs (and the first-visit auto-download) now also
    pulls the SatNOGS DB transmitter list. The ~2-3MB JSON is stream-parsed
    in 2KB object chunks and filtered to active transmitters for catalog
    satellites (~few hundred records, capped 8/sat, 800 total in PSRAM),
    then cached beside the TLEs (SD preferred, SPIFFS fallback) so all
    frequency data works offline in the field.
    - New FREQS screen (MODE_SAT_FREQS) from pass detail: every known
    transmitter with uplink/downlink MHz, mode, inverting flag; curated
    operating note (tones, schedules) shown on top when we have one
    - Pass detail and live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
    [modes.h]
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2026-07-12 fix: pause BLE keyboard scanning while satellite data downloads
    The serial log showed BLEKB HID scans running mid-download. BLE active
    scanning and a sustained multi-MB WiFi TLS stream contend for the
    shared 2.4GHz radio and heap - the known recipe for the intermittent
    crash seen ~3.5MB into the frequency stage. The loop now skips
    updateBLEKeyboardHost() while the update job is active; auto-reconnect
    resumes as soon as it finishes.
    [vail-summit.ino]
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2026-09-13 fix: Morse Notes surfaces SD-card errors and warns when space is low
    A tester's Record button did nothing; the only clue was the serial line
    "[MorseNotes] ERROR: Insufficient SD card space". mnRecBtnClick() had no
    else branch, so every start failure was silent on-device.
    - mnStartRecording() now records why it failed (MnStartError) and the UI
    shows a matching alert: "SD Card Required", "SD Card Full" (with free vs
    required space), or "Out of Memory". A failed save also alerts.
    - The record screen shows a one-time SD indicator: "SD free: X", a warning
    below 5 MB, error below the 500 KB floor, or "No SD card".
    - mnCheckSpace() had two latent bugs: no sdCardAvailable guard (a missing
    c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
    [morse_notes_recorder.h, morse_notes_types.h]
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2026-09-13 fix: report a card pulled after mount as no card, not full
    sdCardAvailable is set once at mount and never cleared, so yanking the card
    later left it "available" while the free-space read returned 0, which the
    new indicator and the Record path both showed as "SD full".
    getSDFreeBytes() now clears the flag when the filesystem read fails (a
    mounted card always reports a nonzero total), and mnStartRecording() reads
    free space before testing the flag so that case surfaces as "no card".
    [morse_notes_recorder.h]
2026-09-20 display: run the panel SPI at 40MHz instead of 80MHz
    One unit out of a three-board build showed a black screen while the firmware
    booted and ran fine. The panel itself was good: it rendered correctly at every
    clock below 80MHz, all six display pins drove cleanly with no short or open,
    and the controller answered over MISO. The fault was marginal signal integrity
    on SCK/MOSI at the part's maximum rate.
    80MHz is the ST7796S ceiling, so running there left no margin for normal
    board-to-board variation. Note there is nothing to fall back to between 40 and
    80: ESP32-S3 SPI divides the 80MHz APB by an integer, so a request for 60MHz
    silently resolves to 40MHz anyway. The old comment suggesting 60M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
    [hardware_init.h]
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2026-09-20 display: add per-second flush profiling behind a compile flag
    Reports bytes pushed, average draw time per buffer, average and worst blocking
    transfer, and the share of wall-clock time the SPI bus is busy, tagged with the
    active mode. Gaps longer than 50ms are treated as idle so a static screen does
    not dominate the draw-time average.
    Off by flipping DISPLAY_PERF_INSTRUMENT to 0, which compiles the counters and
    the report call away entirely. Profiling aid, not intended to ship enabled.
    [vail-summit.ino]
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2026-09-20 audio: keep the sidetone path out of flash so cache stalls cannot stall it
    Dropping the panel to 40MHz doubled how long each display transfer holds SPI0,
    and that showed up as a crunch at the start of every character in copy
    practice. Flash and PSRAM share SPI0 and one cache on the S3, so core 1 doing
    display work stalls core 0 fetching its own instructions, and the audio misses
    its refill deadline.
    Chasing the flash consumers one at a time is a losing game, the thing runs out
    of flash and renders fonts out of flash. So make the real time path not care:
    - audio hot path now in IRAM. audioTask, processAudioRequests,
    processMorsePlayback, samplePaddleInput, continueTone, startToneInternal,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
    [i2s_audio.h, task_manager.h]
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2026-09-20 remove the four training paths that nothing could reach
    Training was collapsed to the single Learn CW path a while back. LICW, CW
    Academy, Vail Master and Hear It Type It stayed in the tree but no menu points
    at any of them, so none of it has been reachable on a device for some time.
    Grep confirms zero menu references. Taking them out rather than carrying them
    through the UI rework.
    Gone: lv_licw_screens.h, lv_vail_master_screens.h, the training_licw,
    training_vail_master, training_hear_it_type_it and training_cwa files, 30 mode
    enum values, their modeInfoTable rows, their init and cleanup entries, their
    poll wrappers, and the legacy drawHeader title branches in menu_ui.h. The mode
    numbers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
    [modes.h, vail-summit.ino]
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2026-09-23 morse notes: stop reserving 160KB twice
    Recording and playback each held a fixed 40000 event buffer, 156KB apiece,
    allocated on first use and never given back. With PSRAM that is invisible.
    Without it the allocation just fails, so recording never starts and playback
    never loads.
    Recording now sizes itself to what the board can actually do: the full 40000
    events with PSRAM, 8000 without, which is about five minutes of steady
    sending. Playback asks the library how long the recording is and allocates
    exactly that, so a short note costs a few KB instead of 156.
    Both buffers are released on the way out of the screen now rather than held
    for the rest of the session.
    The file format has not chan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
    [morse_notes_playback.h, morse_notes_recorder.h, morse_notes_types.h]
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2026-09-29 fix: audio gets priority over background network work, sturdier web files download
    audio
    - one audioPriorityActive() gate: audio-critical mode, or any tone in the last 3s
    - while it's up: no mailbox https poll, internet check, sd backup or ble scans,
    and wifi modem sleep is off so the radio isn't cycling sleep/wake under the tone
    - repeater traffic is untouched
    web files download
    - refuse to reboot into the download when wifi isn't connected, say why instead
    - snapshot the live connection (ssid, psk, bssid, channel) at request time and
    rejoin that first, pinned, then fall back to every saved slot, not just slot 1
    - clean radio reset per attempt, failure reason stays on screen
    - snapshot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
    [vail-summit.ino]
2026-09-29 ram: stop parking feature data and json in internal ram, fix a double free
    everything under 4KB mallocs internal on this core, and tls needs ~40KB of it
    contiguous, so small permanent stuff and json pools add up to wifi trouble.
    - psram-first ArduinoJson allocator (falls back to internal on no-psram boards),
    used for mailbox, pota, license data, cwschool, progress sync, qso, backups, notes
    - vail course progress, band conditions, satellite buffers, mailbox record timing
    and a qso popup buffer are psram pointers now instead of internal statics
    - qso stats: String[100] callsign list is a char table allocated for the call
    - mailbox: drop the loaded message when playback cleans up
    - web ser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
    [morse_mailbox.h, progress_sync.h]
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2026-09-29 serial: never block on usb cdc, and drop per-element decoder prints from the keying path
    with the port enumerated by a host that isn't reading, hwcdc defaults to a
    100ms tx timeout, so every print into a full buffer stalled the loop and the
    keyer. setTxTimeoutMs(0) makes logs drop instead.
    [vail-summit.ino]
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2026-09-30 audio: prefill the whole dma ring when a keyed tone starts
    keyed modes drive startTone/continueTone from the core 1 loop, and the start of
    an element is when that loop is busiest (last character's decode and redraw,
    measured 20-35ms). startTone only queued one 5.8ms chunk, so the dma ran dry
    mid element and the tone crunched. now it fills the ring (~46ms) with
    non-blocking writes and rewinds phase over anything that didn't fit. key-up is
    unchanged since stopTone zeroes the dma.
    [i2s_audio.h]
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

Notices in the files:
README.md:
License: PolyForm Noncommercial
